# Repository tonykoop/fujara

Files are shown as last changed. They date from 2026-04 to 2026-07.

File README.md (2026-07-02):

# Fujara — Engineering Documentation for the Slovak Overtone Shepherd's Flute

> *Parametric design documentation for stave-built fujaras — the deep, harmonics-driven Slovak shepherd's flute, traditionally 5–8 feet tall and tuned to play melodies from the natural overtone series rather than from finger holes.*

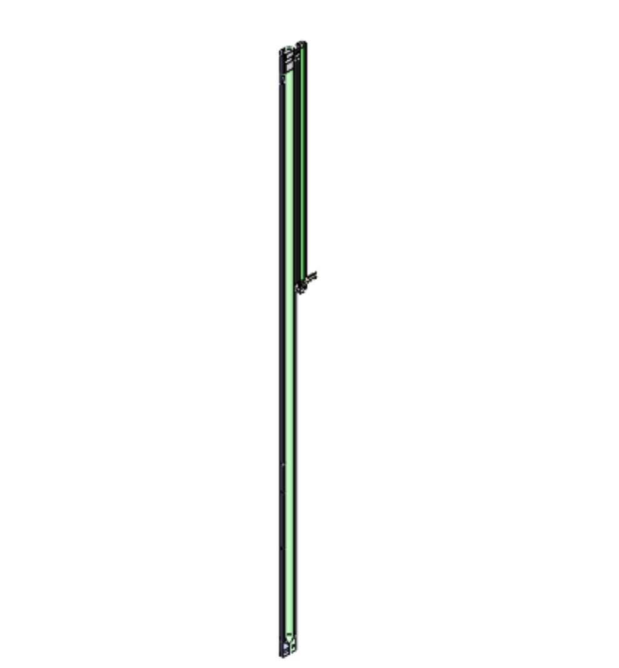
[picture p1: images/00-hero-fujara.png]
Hero photo

*Early fujara body concept render: a tall overtone flute body with side air tube and three-hole voicing, captured here as a parametric CAD/design-table problem before the first physical build.*

**Status:** L2 V5 build-packet candidate

V5 build-packet candidate for design review. The repo contains
design-table, SolidWorks, OpenSCAD starter, vector-plate, print-packet, and
validation artifacts, but it is **not build-ready or empirically verified**
until the bore, flue/labium, side air tube, and tuning-response measurements in
`validation.csv` are captured.

## What this is

Engineering documentation for the **fujara** — a tall, three-hole, side-blown overtone flute originating with the shepherds of central Slovakia. The fujara is recognized by UNESCO as a Masterpiece of the Oral and Intangible Heritage of Humanity (proclaimed 2005, inscribed on the Representative List in 2008).

This repository combines:

1. **A parametric design table** ([`design-table/fujara-dimensions-parametric.xlsx`](design-table/fujara-dimensions-parametric.xlsx)) covering fundamentals from **D2 (~73 Hz, 94" blank) up through F#3 (~185 Hz, 40" blank)**, with formulas that derive every build dimension — bore ID at four candidate aspect ratios (45:1 / 50:1 / 55:1 / 60:1), wall thickness, the three traditional finger-hole positions, blank dimensions — from a single input: the target fundamental note.
2. **CAD geometry** for the body, the side-blown mouthpiece chamber, the labium/voicing geometry at the top of the main bore, and the cutting jigs.
3. **Acoustic analysis** comparing the fujara's harmonic-series voicing to my [Native American flute](https://github.com/tonykoop/flutes) calculations — the design table includes a "NAF CALC K2" cross-reference column.

For a browsable studio map of the current design tables, CAD sources, capstone analysis, validation caveats, and open release blockers, open [`explorer.html`](explorer.html).

Sister project to [`flutes`](https://github.com/tonykoop/flutes), [`djembe`](https://github.com/tonykoop/djembe), [`dundun`](https://github.com/tonykoop/dundun), [`didgeridoo`](https://github.com/tonykoop/didgeridoo), and [`ashiko-drum-workshop`](https://github.com/tonykoop/ashiko-drum-workshop).

## Cultural attribution

The fujara originates with the shepherds of the **Podpoľanie region of central Slovakia** and is considered an emblem of Slovak rural and pastoral culture. UNESCO recognized "Fujara and its music" on the Representative List of the Intangible Cultural Heritage of Humanity in 2008 (initially proclaimed a Masterpiece in 2005). The instrument carries deep cultural significance in Slovak folk music — particularly in *trávnice* (grass songs) and shepherd melodies — and contemporary makers in Slovakia continue traditional methods, often using elderberry or other native woods.

The instruments documented in this repository are built in respect for that tradition by a non-Slovak maker, using stave construction with locally-available North American hardwoods. The engineering documented here is my own derivation; the cultural and musical practice belongs to the Slovak communities from whom the instrument originates.

## Background — what makes a fujara different from every other flute in this portfolio

The fujara is acoustically and architecturally distinctive in three ways:

**1. Melody comes from the harmonic series, not from finger holes.** A fujara has only **three finger holes** (compared to six on a Native American flute, six on a recorder). Those three holes shift the air column's effective length only slightly — they're tuning aids, not melody keys. The melody itself is produced by the player **overblowing** the air column to excite progressively higher harmonics: the 2nd partial (octave above fundamental), 3rd (perfect 5th above that), 4th (octave above the 2nd), 5th (major 3rd), 6th, 7th, 8th, and so on. Combined with the three hole positions, this yields the lydian-flavored modal scale characteristic of fujara melody.

**2. Side-blown air path with a parallel chamber.** Unlike an end-blown flute (didgeridoo, recorder), the fujara has a thin secondary tube running parallel to the main bore for the player's air. The mouthpiece is at the top of this side tube; air travels down it, gets routed across a precisely-cut **labium** (sound-hole edge) at the top of the main bore, and excites the main air column. This split allows the player to address the labium at exactly the right angle and pressure without their face being directly above the bore — important when the instrument is 6+ feet tall.

**3. The instrument is *long*.** A fujara tuned to D2 (~73 Hz) wants a build length of roughly 94 inches — close to 8 feet. Even a shorter F#3 fujara is over 3 feet. The proportions are dictated by acoustics: a low fundamental at audible loudness needs a long air column. The challenge of building one is that you cannot just CNC-mill an 8-foot pipe out of one block of hardwood — staves are practically required.

## The parametric design table

The single engineering-heavy artifact in this repository is the parametric design table. Variables are listed in column A, calculated/tabulated values flow from them:

**User-set variables (per key):**

| Var | Meaning | Range across D2 → F#3 |
|---|---|---|
| A | Blank length | 94" (D2) → 40" (F#3) |
| B | Blank width | 2.25" → 1.5" |
| C | Blank thickness | 1.125" → 0.75" |
| D | Mouthpiece length | 20" → 14" |
| F | Spacing | 0.75" (constant) |
| H | Extra length (chuck jaws) | 2.5" |
| K | Bore inner diameter | 1.25" → 0.875" |
| L | Wall thickness | 0.3125" → 0.1875" |
| M | Nest distance from mouthpiece | 17.75" → 9.75" |
| N–P | Sunken nest depth, width, length | 0.34" / 0.875" / 4.0" |
| Q | Sound hole + flue width | 0.625" → 0.375" |
| R | Sound hole length | 0.25" |

**Calculated/derived (per key, formula-driven):**

- Long Chamber length (the playing tube) and acoustic length (with K1 foot-end and K2 sound-hole end corrections)
- The three hole positions: **Hole 3 at 68%, Hole 2 at 73%, and Hole 1 at 83%** of the way from the foot end of the long chamber. These percentages are the traditional fujara hole positions.
- Hole frequencies for each note in the resulting scale, derived from the chromatic equal-temperament reference `f = 440 × 2^((n-49)/12)`.
- Inner diameters at four candidate **length-to-diameter aspect ratios — 45:1, 50:1, 55:1, 60:1** — to evaluate trade-offs between bright/forward and dark/recessive voicing.

The table extends from **D2 (piano key 18) up to F#3 (piano key 34)** — about an octave and a half of fundamentals, encompassing both the deepest traditional fujaras and the more compact "fujarka" variants.

## Engineering challenges this repository documents

**1. Acoustic length and end correction.** A fujara's effective acoustic length differs from its physical length because of two end corrections: K1 at the open foot end (~0.4 × bore radius) and K2 at the sound-hole end (much larger, varying with sound-hole geometry). The design table calculates K2 directly from the sound-hole + nest geometry rather than using a constant — and cross-references against my Native American flute K2 calculations as a sanity check.

**2. Stave construction at unusual proportions.** Building an 8-foot stave-glued cylinder is not the same engineering problem as building an 18-inch ashiko or a 30-inch djembe body. The aspect ratio makes glue-up clamping and lathe turning their own categories of challenge — you can't fit a 94-inch blank between standard lathe centers.

**3. Voicing the labium.** Unlike a NAF (where a removable bird/fetish block does the voicing), the fujara's labium is cut directly into the main bore at the top of the long chamber, with the side-tube air path positioned to address it. Small differences in labium geometry produce large differences in playability. The design table establishes the geometry; the build is where the voicing is dialed in.

## CAD and jig design

This repo now keeps both the original SolidWorks source set and a lightweight
OpenSCAD starter at [`CAD/fujara.scad`](CAD/fujara.scad). The OpenSCAD file is
a review scaffold with named parameters tied back to `family-spec.csv`,
`sw-reference/Fujara-SW-Design-Table.csv`, and the SolidWorks dimension CSVs;
it is not a substitute for exporting and reviewing the native CAD before shop
use.

Repository structure is laid out for:

- `/CAD/fujara-body/` — the long chamber geometry and side-tube assembly, parametric in target fundamental.
- `/CAD/labium-and-nest/` — the cut at the top of the main bore that the air strikes, and the sunken nest where the side tube meets the main body.
- `/CAD/jigs/` — cutting fixtures. The hole-positioning jig is the most interesting — it has to mark Hole 3, Hole 2, Hole 1 at the calculated percentages of the long chamber length, which itself varies by key.

## Comparison across the instrument portfolio

The fujara closes a useful gap across my instrument repos:

| Instrument | Body | Acoustic principle | Tuning |
|---|---|---|---|
| ashiko | truncated cone | open membrane (head) | drum |
| djembe | goblet | open membrane (head) | drum |
| dundun | cylinder, dual-headed | dual coupled membranes | drum |
| didgeridoo | long cylinder/cone | overblown bore, lip drone | overtone series |
| flutes (NAF) | short cylinder | fipple + finger holes | pentatonic minor |
| **fujara** | **long cylinder** | **fipple + overblown overtone series** | **harmonic series** |

The fujara is the only flute in the portfolio that derives its melody from overblowing rather than finger holes — and the only one tall enough that *single-piece construction is impractical*, making stave-build the natural method.

## What this work is for

- **The acoustic question** — does a parametric design table that works for short NAFs scale up to 8-foot fujaras? The shared "NAF CALC K2" reference column in the design table is the bridge: same end-correction model, very different proportions.
- **The fabrication question** — what stave count, glue-up sequence, and lathe arrangement make an 8-foot tall hollow wooden cylinder achievable for one person to build?
- **The portfolio frame** — the fujara extends the engineering documentation to a sixth instrument family and a seventh continent (Slovakia / Eastern Europe). Together with the others, the repos document a coherent practice across drum and flute traditions on multiple continents.

## License

Released under [CC-BY 4.0](LICENSE) — use freely with attribution. The fujara originates with Slovak culture and is recognized by UNESCO as Intangible Cultural Heritage; the engineering documentation, parametric design table, and CAD work in this repository are my own work, free to reuse and adapt with credit.

## Repository structure

```
fujara/
├── README.md                  ← you are here
├── LICENSE                    ← CC-BY 4.0
├── .gitignore
├── design-table/
│   └── fujara-dimensions-parametric.xlsx   ← the engineering core
├── research/                  ← Slovak fujara references, UNESCO documentation
├── analysis/                  ← acoustic length math, harmonic series mapping
├── CAD/
│   ├── fujara-body/           ← long chamber + side tube parametric in key
│   ├── labium-and-nest/       ← labium cut + side-tube interface
│   └── jigs/                  ← hole-positioning jig (variable by key)
├── drawings/                  ← PDF exports
├── images/                    ← finished-build photos + figures
└── reference/                 ← fujara playing references, scale documentation
```

## Status

| Section | Status |
|---|---|
| Repo description, license, gitignore | ✓ done |
| Parametric design table | ✓ committed (the engineering core) |
| Cultural attribution | ✓ done |
| Hero render / concept image | ✓ committed; concept-only |
| CAD — body geometry | SolidWorks sources plus OpenSCAD starter committed |
| CAD — labium and nest | SolidWorks sources present; shop review required |
| CAD — jigs | placeholders and legacy CNC files present; not released for cutting |
| Acoustic length cross-check vs. NAF | explicit in packet; empirical fujara measurements still required |
| Physical builds | no measured prototype evidence committed |
| Evolution-pipeline intake | Stage 0 intake added under `evolution/` (manifest, design-intent, revisions); Gate A not yet run |

A repository in motion, not a finished portfolio piece.

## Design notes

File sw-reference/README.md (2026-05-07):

# Fujara — SolidWorks Reference

Authoritative SolidWorks-side reference for the Fujara assembly. Companion to
`design-table/fujara_equations.md` (per-part explanatory content) and
`drone-flutes/sw-reference/Drone-Flutes-SolidWorks-MasterLayout.docx` (sister-instrument template).

## Files

- `Fujara-SolidWorks-MasterLayout.md` — design intent for the parametric skeleton: master sketch hierarchy, tier-1/2/3 globals, per-part inheritance, configuration scheme, quality gates, Pack-and-Go forward path. **Read first.**
- `Fujara-Master-Inputs.csv` — flat list of every `g_*` and `c_*` global plus tier-3 derived dims and voicing literals. The human-edit surface for the design table.
- `Fujara-SW-Design-Table.csv` — SW-shaped design table. Open in Excel, save as `Fujara-SW-Design-Table.xlsx`, then in SolidWorks: `Insert > Tables > Design Table > From Existing File`.

## Workflow

```
Master_Inputs.csv (edit globals here)
  ↓
Fujara-SW-Design-Table.csv → save as .xlsx
  ↓
Insert > Tables > Design Table > From Existing File
  ↓
G2Fujara_MasterLayout.SLDPRT (skeleton part, Tools > Equations)
  ↓
Sketch dimensions = g_<name>
  ↓
Downstream parts consume master sketches via Convert Entities + share globals via the same design table
  ↓
Extract_Dimensions.swp → CAD/fujara-body/G2Fujara_Assembly.SLDASM_dimensions.csv
  ↓
ingest_dimension_csv.py validates SW vs Excel
```

## Configurations (initial)

| Configuration | Status |
|---|---|
| `MASTER_TEMPLATE` | seed; preserves current build values; **never delete** |
| `G2_69in` | matches current single-config geometry from May 2026 macro dump |
| `D2_94in` | TBD — populate from `design-table/fujara-dimensions-parametric.xlsx` |
| `F2_77in` | TBD — populate from workbook |
| `A2_60in` | TBD — populate from workbook |

The non-MASTER_TEMPLATE rows have placeholder body lengths — replace with the workbook's per-key values before activating those configurations in SW.

## Migration to Moseno

The MasterLayout part is what Pack-and-Go's into the Moseno repo. See
`moseno/sw-reference/Fujara-to-Moseno-Migration.md` for the rename map and
the Moseno-specific deltas (external blow-pipe, six diatonic finger holes,
four foot tuning holes).

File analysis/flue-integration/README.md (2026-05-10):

# Flue integration variant study (fujara #2)

**Readiness:** L2 design comparison + first-pass 1-D Webster re-run.
**Physics gate:** met (re-uses the merged capstone PR #3 solver).
**Empirical gate:** deferred — no prototype data, no L4 claim.

## Question

The current G2 fujara build has three voicing parts above the labium:

- `G2FujaraTop` / `FujaraBottomG2` — the two halves of the split-blank
  body. Already carry the long fipple-ramp / flue-dam features
  (~349 mm / ~393 mm long) milled into their inside faces.
- `G2FujaraFlue` — a 31.75 mm × 53.975 mm cylindrical block plugged
  into the bore at the head joint. Carries the air duct + windway
  engagement.
- `G2FujaraFluePlug` — a removable wax-sealed plug for fine-tuning.

This study asks: **can the G2FujaraFlue block be eliminated and its
features rolled into G2FujaraTop + FujaraBottomG2?**

## Variants compared

| | Separate-flue (current G2) | Integrated-flue |
|---|---|---|
| Body parts above labium | top + bottom + flue block | top + bottom |
| Permanent glue joints in head | 3 (top↔bottom, top↔flue, bottom↔flue) | 1 (top↔bottom) |
| Flue plug retained? | yes (wax-sealed) | yes (wax-sealed) |
| Active resonator | labium → foot (unchanged) | labium → foot (unchanged) |
| Bore geometry below labium | unchanged | unchanged |

The flue plug stays in both variants — it is the user-facing voicing
adjustment, not a manufacturing artifact.

## Findings (TL;DR)

1. **Acoustically a wash.** The 1-D Webster solver reports
   `delta_modal = 0.000 Hz` and `delta_coupled = 0.000 Hz` across all
   five modes. Both variants share the same labium-to-foot length, the
   same bore ID, and the same wall geometry — the only inputs the 1-D
   model sees. See [acoustic-impact.md](acoustic-impact.md).

2. **Geometry is interchangeable.** The integrated variant absorbs the
   54 mm flue-block features as additional pocket cuts on the inside
   faces of the two body halves — the split-blank construction already
   exposes both faces to CNC. See
   [geometry-comparison.md](geometry-comparison.md).

3. **Manufacturing trades complexity for finality.** Integrated drops
   one part, two glue joints, and one alignment fixture. In exchange,
   the windway becomes irreplaceable once the body halves are glued —
   the separate-flue variant lets you swap a recut block without
   rebuilding the whole instrument. See
   [manufacturing-impact.md](manufacturing-impact.md).

4. **Recommendation:** integrated wins for production runs once the
   voicing literals stabilise. Separate wins during prototyping and
   for repair-friendliness. See [recommendation.md](recommendation.md).

## Reproduce

The cavity FEM re-runs the merged capstone solver against the same
A2 baseline (110 Hz, 50:1 aspect):

```
python3 analysis/flue-integration/scripts/integrated_flue_cavity.py
```

Outputs land in `analysis/flue-integration/data/`. The script imports
from `capstone/scripts/{fujara_design_math,acoustic_cavity_fem}.py` —
no solver code is duplicated.

## Files

- [README.md](README.md) — this overview
- [geometry-comparison.md](geometry-comparison.md) — side-by-side
  dimension table
- [acoustic-impact.md](acoustic-impact.md) — Webster re-run + sensitivity
- [manufacturing-impact.md](manufacturing-impact.md) — joinery, jig, tolerance
- [recommendation.md](recommendation.md) — when each variant wins
- `scripts/integrated_flue_cavity.py` — comparison driver
- `data/integrated-vs-separate.csv` — per-mode delta
- `data/sensitivity-end-correction.csv` — f0 vs ±2 mm end-correction shift

## Hardware-development gate

| Gate | Status | Evidence |
|---|---|---|
| Math | met | Reuses capstone closed-form geometry |
| Physics | met | 1-D Webster + wall-flex correction re-run |
| Empirical | deferred | Requires a prototype of the integrated variant |

The deferred empirical gate is the honest line. The 1-D model cannot
distinguish the two variants; promotion to L4 requires a built-and-blown
integrated-flue body and a comparison of measured f0, second-mode
purity, and overblow stability against the existing G2 build.

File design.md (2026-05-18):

# Fujara V5 Candidate Design Notes

Current status: V5 build-packet candidate, not build-ready.

The fujara is treated here as an open-open edge-tone/overtone flute. The long
main bore controls the fundamental and overblown harmonic series; the side air
tube and flue deliver the jet to the labium and can strongly affect response,
but they are not modeled as a second pitched resonator in this packet.

## Governing Acoustic Model

- `acoustic_law`: `open_open`
- `end_condition`: `both_ends_open`
- First-pass pipe relation: `L_eff = c / (2 f)`
- Room-temperature validator check: 20 C speed of sound.
- Warm-playing discipline: final tuning must compare room measurements with a
  breath-warmed condition before any trim/cut geometry is released.

For the A2 study baseline at 110 Hz, the simple open-open relation gives a
room-temperature effective length near 1559 mm before end-correction choices.
The committed family-spec row records a validator-compatible first-pass
geometry length of 1550.96 mm after the validator's default open-open end
correction. Existing SolidWorks and workbook dimensions remain the design
evidence to review, not proof of a tuned physical build.

## Bore, Flue, And Side-Tube Discipline

The V5 packet separates three questions that were previously easy to blend:

- Main bore: length, inner diameter, wall thickness, and open-end correction.
- Flue/labium: jet width, sound-hole length, nest depth, edge distance, and
  voicing adjustability.
- Side air tube: delivery path length, leakage, pressure drop, junction angle,
  and alignment to the labium.

The side tube should be measured as an air-delivery branch. Do not use it to
move the fundamental unless a measured prototype shows a repeatable coupled
resonance effect.

## Fabrication Authority

Candidate fabrication authority is limited to the design tables, native
SolidWorks files, SolidWorks dimension CSVs, the OpenSCAD starter, and the
dimensioned vector plate. Generated or rendered images are concept-only. The
DXF is a dimensioned review plate, not CAM-ready toolpath output.

## Promotion Blockers

- Measure bore stations at the foot, mid-body, branch/labium zone, and top.
- Measure flue width, sound-hole length, labium edge distance, and nest depth.
- Confirm side-tube leakage and junction angle before treating response claims
  as stable.
- Record tuner measurements for fundamental and overblown partials at a known
  temperature/humidity.
- Export/review CAD/DXF from the authoritative CAD workflow before machining.

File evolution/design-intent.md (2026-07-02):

# Design Intent — fujara rev A

- Master CAD: `CAD/fujara.scad` (sha256: 190f380fcafa50e0e100f06de4f9074fb25d0c7fa3dfdc7ff3e39e73c57e09af) with native SolidWorks assembly `CAD/fujara-body/Fujara_Assembly.SLDASM`, driven by `design-table/fujara-dimensions-parametric.xlsx` (sha256: 8067350d3233be8ecccbec798d0cbfb39151a577be4614266ba0883d7fdd3033)
- Function: Slovak overtone shepherd's flute (fujara) — a deep, harmonics-driven stave-built flute (traditionally 5–8 ft tall) that plays melodies from the natural overtone series rather than from finger holes. Long open-open main bore with a side air-delivery tube (jet delivery, not a pitched resonator) and three-hole voicing. First pass uses an open-open validator model.
- Environment: long stave glue-up (bore distortion risk); breath-contact finishes must be cured/food-safe; overtone response depends on bore + flue/labium + side tube measured together. Cultural attribution to Slovak fujara tradition stays visible (engineering derivation, not ownership).
- Target qty: 1 (per selected key). Deadline: TBD. Budget/unit ceiling: TBD.

## Critical dimensions (carry tolerances)

| Feature | Nominal | Tolerance | Why critical | Source |
| --- | --- | --- | --- | --- |
| A2 predicted geometric length | 1550.96 mm | measure fundamental + overtone alignment | fundamental pitch (A2 = 110.00 Hz) | family-spec.csv FUJ-A2-STUDY (physics_derived) |
| Main bore ID | 31.75 mm | measure after stave glue-up | bore governs pitch/overtones | family-spec.csv FUJ-A2-STUDY |
| Bore aspect ratio | 49.0 | recompute from measured bore | slender-bore overtone behavior | family-spec.csv FUJ-A2-STUDY |
| Three tone-hole positions | 68/73/83% of long chamber length | tune to overtone scale physically | melodic overtone scale | family-spec.csv hole_rule |
| Flue width | TBD | response-critical; adjust by hand | voicing / speaking | family-spec.csv (measurement_required) |
| Side air tube role | air-delivery branch (measurement_required) | measure leakage/pressure/junction | jet delivery + response | family-spec.csv side_tube_role |

## Incidental (free for DFM)

- Exterior body styling/taper, decorative carving/banding, stave count cosmetics, finish color, mouthpiece exterior — subject to breath-safety.

## Must-nots (DFM may never violate)

- Flue/labium/voicing geometry is response-critical and tuning-sensitive: refine by hand, never freeze from the scaffold or a lossy export (risks.md Acoustic).
- Do not treat SolidWorks files as authority for a given key until a configuration-specific export is reviewed (risks.md Fabrication).
- DXF/SVG plates are review plates, not CNC toolpaths — do not cut from them (register / risks.md).
- Do not treat the side air tube as a pitched resonator without measurements (family-spec).
- Breath-contact finishes/adhesives must be fully cured and food-safe (risks.md Safety).

## Material intent

- Preferred: stave-built wood body per bom.csv; long stock with adequate lathe/workholding capacity.
- Acceptable subs: per sourcing.csv (spec-first; live prices unverified; breath-safe finishes only).
- Forbidden: uncured/non-food-safe interior finishes on breath-contact surfaces.

## Stage status

Stage 0 intake complete 2026-07-01. Gate A (Alpha shop compile) NOT yet run — no concessions logged, nothing presented as shippable. L2 candidate; authority remains measurement-gated.

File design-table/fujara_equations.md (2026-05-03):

# Fujara Equations & Global Variables

Starter parametric scheme. Add globals via **Tools > Equations** in each part, then drive feature dims from them.

Conventions:
- All values in **mm** (SolidWorks accepts mm even when the part displays in inches).
- Names in `snake_case`.
- A leading `g_` marks a true design-master global (the small set you'd actually tune).
- A leading `c_` marks a fit-clearance constant (interference is negative).

---

## Tier 1 — Design master globals

These are the only numbers you change to retune the whole instrument. **Define identically in every part that uses them.** (Long-term: move to assembly-level externals or a master sketch — for now, sync by hand.)

| Global | Value (mm) | Value (in) | Used in |
|---|---|---|---|
| `g_body_OD` | 47.625 | 1.875 | top, bottom |
| `g_body_ID` | 31.75 | 1.250 | top, bottom (= 2 × bore radius) |
| `g_body_L_finished` | 1755.775 | 69.125 | top, bottom, assembly |
| `g_body_L_blank` | 1803.4 | 71.000 | top, bottom |
| `g_body_blank_W` | 57.15 | 2.250 | top, bottom |
| `g_mp_block_OD` | 28.575 | 1.125 | mouthpiece top + bottom block |
| `g_mp_block_ID` | 15.875 | 0.625 | mouthpiece top + bottom block |
| `g_mp_block_L_blank` | 735.584 | 28.960 | mouthpiece top + bottom block |
| `g_mp_block_blank_W` | 38.1 | 1.500 | mouthpiece top + bottom block |
| `g_mp_tube_OD` | 15.875 | 0.625 | mouthpiece (blow-tube part) |
| `g_mp_tube_ID` | 9.525 | 0.375 | mouthpiece, toptube |
| `g_dowel_OD` | 6.35 | 0.250 | top, bottom (matches 1/4" stock) |
| `g_thru_passage_OD` | 12.7 | 0.500 | flue, body bottom, mp blocks, fipple chamfer |

---

## Tier 2 — Fit / clearance constants

Define once in each part; same value everywhere. **Sign convention**: clearance is positive (hole is bigger), interference is negative.

| Constant | Value (mm) | Value (in) | Use case |
|---|---|---|---|
| `c_glue_gap` | 0.0762 | 0.003 | wood-on-wood permanent glued joints (body halves mating, breath connector glued in place) |
| `c_wax_seal_fit` | 0.0762 | 0.003 | removable parts sealed with beeswax (flue plug — pulls out for drying/cleaning) |
| `c_slip_fit` | 0.381 | 0.015 | non-sealed slip fit (ornament tubes in mounting holes) |
| `c_dowel_clearance` | 0.0 | 0.000 | dowel pin hole = pin OD (snug, glued) |
| `c_cork_interference` | -0.1524 | -0.006 | cork plug oversized vs bore — interference seal blocks horizontal air path, redirecting flow vertically through breath connector |

`c_glue_gap` and `c_wax_seal_fit` happen to share a value today but represent different design intent. Keep them separate so when you dial in the actual wax thickness through testing, you don't accidentally widen every glue joint in the instrument.

### Air flow path (for context — drives which fits matter)

Player → horizontal channel in body bottom → blocked by **cork** (interference seal) → vertical up through **breath connector** tube (glue-fit through both body halves) → into voicing area → through **flue plug** slot (0.040" height, wax-sealed, removable) → across the cutting edge of the flue chamfer (sound is produced here).

---

## Tier 3 — Per-part equations

Format: `"name" = expression`. Paste into **Tools > Equations** > Global Variables.

### G2FujaraTop.SLDPRT

```
"g_body_OD" = 47.625
"g_body_ID" = 31.75
"g_body_L_finished" = 1755.775
"g_body_L_blank" = 1803.4
"g_body_blank_W" = 57.15
"g_dowel_OD" = 6.35
"g_thru_passage_OD" = 12.7
"c_glue_gap" = 0.0762
"c_dowel_clearance" = 0
"board_thickness" = "g_body_blank_W" / 2
"blank_length" = "g_body_L_blank"
"blank_width" = "g_body_blank_W"
"bore_inner_radius" = "g_body_ID" / 2
"outer_diameter" = "g_body_OD"
"finished_length" = "g_body_L_finished"
"dowel_pin_diameter" = "g_dowel_OD" + "c_dowel_clearance"
```

Voicing (unique acoustic params — keep as literals, **not** globals):
```
"fipple_gap" = 10.16
"fipple_ramp" = 349.0659
"flue_dam" = 392.6991
"flue_depth" = 12.1285        ' Sketch5
"flue_depth" = 0.8382          ' Sketch8 — note same name, different sketch is fine
"fipple_height" = 0.254
"fipple_ramp_in" = 87.2665
```

Tuning (finger holes — these are the per-pitch numbers; each fujara key gets its own set):
```
"hole1_diameter" = 7.62
"hole2_diameter" = 7.62
"hole3_diameter" = 7.62
"fipple_to_hole1" = 1157.224
"fipple_to_hole2" = 1242.314
"fipple_to_hole3" = 1412.494
```

End cap groove (driven by OD — already correct in your model):
```
"groove_width" = 3.175
"groove_depth" = 6.35
"groove_location" = "g_body_OD"     ' confirms your IsDriven=TRUE
```

### FujaraBottomG2.SLDPRT

Same `g_*` and `c_*` block as top, plus:
```
"thickness" = "g_body_blank_W" / 2
"blank_length" = "g_body_L_blank"
"blank_width" = "g_body_blank_W"
"inner_bore_radius" = "g_body_ID" / 2
"outer_diameter" = "g_body_OD"
"finished_length" = "g_body_L_finished"
"dowel_pin_diameter" = "g_dowel_OD" + "c_dowel_clearance"
"mouthpiece_hole" = "g_thru_passage_OD" + "c_glue_gap"   ' so the 12.7 mp tube glues cleanly
```

> Recommendation: rename `thickness` → `board_thickness` here too, so the top/bottom CSV columns line up.

Mouthpiece tube mounting hole (already has slip fit — make it explicit):
```
"tube_diameter" = "g_mp_tube_OD" + "c_slip_fit"     ' = 15.875 + 0.381 = 16.256 ✓
"bracket_length" = 691.134
```

### G2Fujara_MouthpieceBottom.SLDPRT *(and Top — same equations both halves)*

```
"g_mp_block_OD" = 28.575
"g_mp_block_ID" = 15.875
"g_mp_block_L_blank" = 735.584
"g_mp_block_blank_W" = 38.1
"g_mp_tube_OD" = 15.875
"g_thru_passage_OD" = 12.7
"c_glue_gap" = 0.0762
"c_slip_fit" = 0.381

"thickness" = "g_mp_block_blank_W" / 2
"blank_length" = "g_mp_block_L_blank"
"blank_width" = "g_mp_block_blank_W"
"outer_diameter" = "g_mp_block_OD"
"inner_diameter" = "g_mp_block_ID" + "c_glue_gap"     ' tube OD 15.875, bore 15.952, glue film
"mouthpiece_through_hole" = "g_thru_passage_OD" + "c_glue_gap"
"mouthpiece_location" = 22.225
"counterbore_diameter" = "g_mp_tube_OD" + "c_slip_fit"   ' = 16.256
```

### mouthpiece.SLDPRT (the blow-tube)

```
"g_mp_tube_OD" = 15.875
"g_mp_tube_ID" = 9.525
"mouthpiece_outer_diameter" = "g_mp_tube_OD"
"mouthpiece_inner_diameter" = "g_mp_tube_ID"
"height@tube" = 50.8                 ' literal — overall tube length is its own design choice
"mouthpiece_curved_cut" = 21.4548
```

### Cork.SLDPRT

```
"g_mp_block_ID" = 15.875
"c_cork_interference" = -0.1524
"mid_diameter" = "g_mp_block_ID" - "c_cork_interference"   ' = 15.875 + 0.1524 = 16.027
"taper" = 122.173
"half_height" = 6.35
```

Subtracting a negative gives oversize. If that reads weirdly, flip the sign convention: define `c_cork_press = 0.1524` (always positive) and write `mid_diameter = g_mp_block_ID + c_cork_press`. Pick whichever stays cleaner in your head.

### G2FujaraFlue.SLDPRT (the voicing block)

```
"g_body_ID" = 31.75
"g_thru_passage_OD" = 12.7
"c_glue_gap" = 0.0762

"flue_block_diameter" = "g_body_ID" - "c_glue_gap"   ' = 31.674 — slips into bore with glue film
"flue_width" = "g_thru_passage_OD"
"duct_diameter" = "g_thru_passage_OD"
"flue_engagement" = 3.8862
"duct_location" = 22.225
```

### G2FujaraFluePlug.SLDPRT *(removable, wax-sealed — not glued)*

```
"g_thru_passage_OD" = 12.7
"c_wax_seal_fit" = 0.0762
"flue_plug_width" = "g_thru_passage_OD" - "c_wax_seal_fit"   ' = 12.6238 ✓
"flue_plug_length" = 53.975
"slot_radius" = 5.08
"slot_location" = 22.225
"airway_passage" = 9.525
"flue_height@slot" = 1.016    ' 0.040" — voicing-critical, no clearance, sealed with beeswax
```

The 0.040" slot height is the air-jet thickness — keep as a literal, this is a voicing-tuning parameter.

### toptube.SLDPRT / bottomtube.SLDPRT

These look like ornamental/structural tubes that slip into the mounting holes:
```
"g_mp_tube_OD" = 15.875
"g_mp_tube_ID" = 9.525
"tube_od" = "g_mp_tube_OD"
"tube_id" = "g_mp_tube_ID"
"height@tube" = 15.875       ' literal — could be a separate design global if these need to scale
```

### Assembly (Fujara_Assembly.SLDASM)

```
"g_body_L_finished" = 1755.775
"cut_to_length" = "g_body_L_finished"
```

The assembly sketch now carries the **voicing-aim measurement**:

```
true_sound_hole_to_splitting_edge_offset = 0.2354 mm = 0.0093"   ' IsDriven=TRUE
```

This is a **measured outcome**, not an input — SolidWorks computes it from the geometry. Don't try to drive it from a global; instead, watch it as a KPI. If you change anything in the flue plug, body alignment, or fipple geometry and this number drifts, you'll see it on the next macro run. The 0.0093" sits in the typical fujara voicing window (~0.005"–0.015") — leave it as the canary.

---

## What this buys you

- Change `g_body_L_finished` once — every `finished_length`, `cut_to_length`, etc. updates.
- Change `c_glue_gap` once — every glued joint adjusts together. Test-drive your fits without chasing 12 dims.
- The renamed `D1` dims (board_thickness, height@tube, etc.) become equation-driven, so they show up in the CSV as `IsLinked=TRUE` and the macro will print the formula in `EquationOrComment`.
- The dimensions that are *coincidentally* equal (the 12.7s that aren't all the same passage, the 15.875s that aren't all the tube OD) stay as literals — preserves design intent.

## Suggested next moves

1. Add the master `g_*` globals to `G2FujaraTop` first, drive its dims, save and rerun the macro. Confirm `IsLinked=TRUE` shows up where expected.
2. Repeat for the other parts.
3. Rename `thickness` → `board_thickness` on the bottom half + mouthpiece blocks for consistency.
4. Once it's all wired up, your `fujara-dimensions-parametric.xlsx` design table only needs to expose the `g_*` and `c_*` rows — everything else propagates.

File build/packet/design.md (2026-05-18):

# Fujara Issue #5 V5 Starter

Issue context: `fujara` needs a V5 starter with explicit **bore** and **side-branch** authority gates.

## Scope

- Keep the packet at **V5 build-packet candidate for design review** until
  measurements justify a higher label.
- Focus on long-bore geometry, flue/labium response, and side air-tube delivery
  without treating the side tube as a pitched resonator by default.
- Record what is *observed* vs what is *inferred* from design history.

## Known and Inferred

Observed inputs:

- Existing fujara design table (`fujara-design-table.xlsx`, `design-table/fujara-dimensions-parametric.xlsx`) contains derived candidate dimensions and length-to-diameter ratios.
- Repo CAD references are present for the instrument body and labium structures but are not validated as fabrication-ready in this lane.

Inferred/Starter scope:

- Side air-tube relation to the labium remains the key response variable that
  should be measured before any authoritative CAD/DXF updates.
- Main-bore station geometry, end correction, flue width, sound-hole length,
  labium distance, and side-tube leakage are tracked as measurement blockers
  until `validation-loop` rows are populated.

## Authority Rules for this Packet

- `family-spec.csv` is the packet acoustic-law register and declares a
  validator-checkable open-open edge-tone/overtone flute row.
- `bore-station-plan.csv` is a measurement scaffold, not authority on its own.
- `visual-output-register.csv` must keep generated or concept outputs as non-authoritative unless proven by measured rows.
- No branch transitions to L3/L4 until acoustic-law and bore/side-branch measurement gates are passed.

## Gate Plan

Populate measurement rows and update gate status in this order:

1. Confirm acoustic-law row and side air-tube delivery hypothesis in `family-spec.csv`.
2. Measure bore stations and side-branch transition distances in `bore-station-plan.csv`.
3. Complete `validation-loop.csv` for response, bore station capture, and authority gating.
4. Advance `validation.csv` gates only when all evidence is present.

## First Tests to Collect

- Main-bore stations: mouth-end, side-branch injection point, and labium end.
- Side-branch geometry: entry path length, offset to labium, and junction angle.
- Side-branch response behavior: leak/suction checks and basic pressure-to-stability notes.
- One non-structural visual check only (photo/plan review) before any fabrication claim.

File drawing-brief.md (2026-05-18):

# Fujara Drawing Brief

Current status: V5 build-packet candidate, not build-ready.

## Drawing Set

- `drawings/fujara.svg`: human-readable vector review plate.
- `drawings/fujara.dxf`: dimensioned review plate for CAD/CAM handoff checks.
- `CAD/fujara.scad`: OpenSCAD starter showing named parameters and layout.
- `print-packet/assembly-plate.pdf`: annotated review/assembly plate.

## Authority Chain

Fabrication dimensions are controlled by the design tables, SolidWorks source
CAD, SolidWorks dimension CSVs, and reviewed CAD/DXF exports. The SVG, DXF,
OpenSCAD starter, and print plate in this lane are candidate review artifacts
that must be checked against the selected key/configuration before machining.

Generated images and renders are concept-only and do not control bore length,
hole position, flue geometry, side-tube placement, or toolpaths.

## Required Callouts

- Target note and frequency.
- Open-open governing model and temperature assumption.
- Long chamber length and bore ID source.
- Hole positions at 68%, 73%, and 83% of long chamber length.
- Flue width, sound-hole length, labium edge distance, and side-tube junction
  as measurement-required until captured.
- Explicit "not CAM-ready" note on any DXF that has not been shop-reviewed.

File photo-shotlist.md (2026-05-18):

# Fujara Photo Shotlist

Use neutral shop documentation. Do not publish private location, family, or
child imagery.

| shot_id | subject | purpose | status |
| --- | --- | --- | --- |
| PH-001 | Full instrument against a height reference | Scale and public overview | needed |
| PH-002 | Labium and flue close-up | Response-critical geometry | needed |
| PH-003 | Side air tube junction | Delivery path and leak-check evidence | needed |
| PH-004 | Bore foot/end view | End correction and bore ID reference | needed |
| PH-005 | Three-hole layout | Hole position verification | needed |
| PH-006 | Tuner capture during fundamental | Validation evidence | needed |
| PH-007 | Tuner capture during overblown partials | Harmonic-series validation | needed |
| PH-008 | Assembly fixture/workholding | Fabrication repeatability | needed |

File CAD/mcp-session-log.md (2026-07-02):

# MCP Session Log

V5 provenance — aligned with `tonykoop/instrument-maker` V5 build-packet standard.

This repository has historical SolidWorks and design-table artifacts plus
Round 30 hand-authored review artifacts and a bob/r1 monolithic-variant scaffold.
No Claude Desktop MCP session was run in any lane.

| session_id | tool | input_authority | outputs | role | authority_result | review_status | notes |
| --- | --- | --- | --- | --- | --- | --- | --- |
| 2026-05-18-scad-v1 | openscad | design-table/fujara-dimensions-parametric.xlsx; sw-reference/Fujara-SW-Design-Table.csv | CAD/fujara.scad | cad_authoring | pending_measurement | unreviewed | OpenSCAD starter from design-table/SolidWorks references; review scaffold; NOT fabrication authority. |
| 2026-05-18-svg-dxf-v1 | illustrator_manual | design-table/fujara-dimensions-parametric.xlsx | drawings/fujara.svg; drawings/fujara.dxf | drawing_cleanup | derived_preview | unreviewed | Vector review plates; candidate dimension references; not CAM toolpaths. |
| 2026-05-18-print-v1 | manual | design.md; bom.csv; validation.csv | print-packet/assembly-plate.pdf | print_plate | derived_preview | unreviewed | Generated from packet text for review; no Photoshop/Illustrator MCP session available. |
| 2026-05-29-bob-r1-monolithic | openscad | CAD/fujara.scad; family-spec.csv; design-table/fujara-dimensions-parametric.xlsx | CAD/fujara-body-monolithic/fujara-monolithic.scad | cad_authoring | pending_measurement | unreviewed | Monolithic body variant (issue #2): integrates Flue_Top geometry into Body_Top + Body_Bottom modules. All flue/labium dimensions are measurement-required starters. Not fabrication authority. |
| fable-v5-refresh-2026-07-01 | claude-code (Fable 5) | design-table/fujara-dimensions-parametric.xlsx | fujara-design-table.xlsx, design-table/fujara-dimensions-parametric.xlsx | packet_refresh | fabrication | self_checked | V5 refresh pass; historical design-table workbooks reviewed against parametric authority. No dimension changes. Provenance row registers fujara-design-table.xlsx into the log to satisfy V5 fabrication-artifact logging. |
| fable-v5-refresh-2026-07-01 | solidworks (native source, pre-existing) | design-table/fujara-dimensions-parametric.xlsx | CAD/fujara-body/Fujara_Assembly.SLDASM, CAD/fujara-body/G2Fujara_Assembly.SLDASM_dimensions.csv | source_registration | fabrication | self_checked | Registers pre-existing native SolidWorks assembly + its extracted G2 dimension CSV into the provenance log (no MCP session run). Candidate dimension review only; select/review per key before build. |
| fable-v5-refresh-2026-07-01 | claude-code (Fable 5) + OpenSCAD CLI | design-table/fujara-dimensions-parametric.xlsx | CAD/fujara.scad | cad_authoring | pending_measurement | self_checked | Existing OpenSCAD starter (kept, not rewritten). openscad render check: pass (openscad -o STL, exit 0). |
| fable-v5-refresh-2026-07-01 | claude-code (Fable 5) | design-table/fujara-dimensions-parametric.xlsx | build/wolfram/side-branch-relation/fujara_sidebranch_starter.wl | analysis_source | derived_preview | unreviewed | Existing Wolfram side-branch starter; source-only (not executed). L2 evidence. |

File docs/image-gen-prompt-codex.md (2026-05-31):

# Image Generation Prompt

Concept visualization only. Do not treat generated images as dimensional, tuning, CAD, DXF, or fabrication authority.

## Hero Prompt

Photorealistic studio product photograph of a finished stave-built fujara concept, an extremely tall Slovak overtone flute with a long main wooden bore, a parallel side air tube, three finger holes low on the body, and a visible labium or voicing window near the top where the side tube meets the main pipe. Warm hardwood staves, oil finish, subtle shepherd-flute silhouette, full height shown with a stool or wall mark for scale, clean studio background, soft directional lighting, three-quarter product angle, about a 50mm lens, high detail.

## In-Context Prompt

Photorealistic image of the fujara staged upright in a bright woodshop or quiet folk rehearsal room, leaning safely on a padded stand, side air tube and three-hole layout visible. Include long clamps, bore gauges, and a design table notebook with no readable text nearby. Natural light, realistic proportions, environmental storytelling around validating a very long side-blown overtone flute.

## Detail/Macro Prompt

Close-up macro of the fujara side-tube junction and labium area: parallel air tube feeding into a carefully cut voicing window on the main bore, crisp splitting edge, oiled hardwood, tight joinery, three-hole body fading into the background, soft raking light, photorealistic high detail.

## Negative / Avoid

Avoid logos, watermarks, readable text, recorder-like headjoints, six-hole flute layouts, impossible tube connections, miniature proportions, and fake traditional decoration.

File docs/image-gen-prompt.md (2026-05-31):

# Image-Gen Prompts

Concept image only; not fabrication authority. Do not include cut-ready dimensions, hole locations, or toolpaths.

## Hero Prompt

A single tall Slovak fujara overtone flute standing nearly vertical as a finished physical object, photographed in a clean neutral studio. The instrument is a very long, slender stave-built wooden cylinder — close to two meters tall — with a smooth turned hardwood surface showing warm North American hardwood grain and subtle vertical glue lines from the staves. Its signature recognizable feature is the thin secondary air tube running parallel to the main bore for roughly the upper third of the length, joined to the main body at a sunken nest where the side tube meets the labium; a side-blown mouthpiece sits at the very top of this parallel tube. The main bore shows an open foot end at the bottom and a small cut labium / sound-hole near the top of the long chamber, with only three modest finger holes spaced along the lower body. Hand-rubbed oiled finish, slightly satin sheen, a faint chamfer at the open foot. Realistic scale cues — the flute is taller than an adult, leaning gently against a plain seamless backdrop. Soft directional studio light from the upper left, gentle falloff, 3/4 product-photography angle, ~50mm lens, high detail, photorealistic, no text labels.

## In-Context Prompt

The same tall stave-built fujara staged upright in a quiet woodworking shop, leaning near a workbench with shavings and a few hand tools softly out of focus in the background, the parallel side air tube and top mouthpiece catching window light. Warm natural daylight from a side window, environmental storytelling of a one-person shop where an eight-foot wooden flute is built from staves, shallow depth of field, the full slender length receding gently into soft focus. Concept visualization only, photorealistic, no text.

## Detail Prompt

Macro close-up of the fujara's signature voicing zone: the junction where the thin parallel side air tube meets the main bore at the sunken nest, with the cut labium / sound-hole edge on the main body just below it. Show the precise beveled edge of the labium, the small rectangular sound-hole opening, the flue gap delivering the air jet, and the turned hardwood grain with faint stave glue lines around the nest. Raking low-angle light to reveal the edge geometry and surface texture, very shallow depth of field, high detail, no measurements, no callouts.

## Negative / Avoid

No text, logos, watermarks, or fake maker marks; no dimension lines, measurement callouts, or tuning numbers; no impossible mechanisms; no extra finger holes beyond three; the side air tube is an air-delivery branch, not a second bell — keep it thin and parallel; anatomically plausible hands if a player is shown.

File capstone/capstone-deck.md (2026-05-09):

# Fujara L:D Aspect-Ratio Capstone — Parametric Modal + Acoustic FEM

Tracking issue: `tonykoop/fujara#1`. Sister repo:
[`instrument-maker`](https://github.com/tonykoop/instrument-maker) (v4.3
release candidate).

Status: **L3-frontier** (analysis only). Empirical gate explicitly deferred
until a physical prototype is built and measured.

---

## Slide 1 — Scope

Sweep the four canonical fujara L:D aspect ratios — **45 / 50 / 55 / 60** —
at a fixed design fundamental and report:

1. a parametric design table that generates all build dimensions from the
   target fundamental and the chosen L:D;
2. the lowest five **structural** bending modes of the wooden tube (modal
   FEM scaffold);
3. the lowest five **acoustic cavity** modes of the air column, computed
   modal-only (rigid wall) and coupled (wall flexibility included);
4. an honest comparison and a punch list for the next builder.

The goal is *not* a prediction of perfect tuning. The goal is to land an
analysis scaffold that a future build/measurement loop can plug into.

### Design fundamental

**A2 (110 Hz)** — sits between the deepest D2 (~73 Hz, 94" blank) and the
smallest fujarka F#3 (~185 Hz) documented in
`design-table/fujara-dimensions-parametric.xlsx`, and lines up with the
existing 1.25" bore + 50:1 baseline used in the SolidWorks parts.

---

## Slide 2 — Project intent

The fujara is the only flute in this portfolio whose melody comes from
**overblowing the harmonic series**, not from finger holes. That makes the
cavity-mode spectrum the design target — every mode the player wants to
sound has to be a near-rational ratio of the fundamental, and the wooden
tube must not have a structural mode coincident with one of them.

L:D is the timbre lever. Same fundamental, different bore diameter:

- low L:D (45) → wider bore → more forward, brighter voice, more harmonic
  energy in the upper partials, but easier to overblow;
- high L:D (60) → narrower bore → recessive, dark, breath-economical voice,
  harder to drive the upper partials cleanly.

This capstone is an attempt to put numbers on that intuition before
committing wood.

---

## Slide 3 — Governing models

Three closed-form physics models, all FE-validated in this study.

```
open-open pipe       f_n = n c / (2 L_eff),   L_eff = L + 2 * 0.6 * a
free-free EB beam    f_n = (beta_n L)^2 / (2 pi L^2) * sqrt(EI / (rho A))
wall-flex perturb    dc/c = -0.5 * (rho_air c^2) / (E t / (2 a))
```

Where:

- `c = 343 m/s`, `rho_air = 1.204 kg/m^3` (air at 20 C, 1 atm)
- `E = 11.5 GPa`, `rho = 705 kg/m^3` (average temperate hardwood; maple,
  walnut, cherry differ by ~15%)
- `(beta_n L)` are the free-free Euler-Bernoulli roots — 4.730, 7.853,
  10.996, 14.137, 17.279
- end-correction coefficient 0.6 is the small-radius unflanged limit; one
  value used at both ends as a first-cut symmetric approximation

Wall thickness rule: **t = 0.22 D**, the median of the existing
D2..F#3 design-table column (which spans 21..25%).

---

## Slide 4 — Parametric design table

Generated by `capstone/scripts/generate_design_table.py`. Full CSV at
`capstone/design-table/aspect-ratio-matrix.csv`.

| L:D | Bore D (in) | Bore L (in) | Wall t (in) | Acoustic L (m) | Cavity vol (m^3) | f1 (Hz) | f2 (Hz) | f3 (Hz) |
| ---:| ---:| ---:| ---:| ---:| ---:| ---:| ---:| ---:|
| 45 | 1.346 | 60.57 | 0.296 | 1.5591 | 1.413e-3 | 110.0 | 220.0 | 330.0 |
| 50 | 1.213 | 60.65 | 0.267 | 1.5591 | 1.149e-3 | 110.0 | 220.0 | 330.0 |
| 55 | 1.104 | 60.72 | 0.243 | 1.5591 | 0.952e-3 | 110.0 | 220.0 | 330.0 |
| 60 | 1.013 | 60.77 | 0.223 | 1.5591 | 0.802e-3 | 110.0 | 220.0 | 330.0 |

Two non-obvious results worth pausing on:

- **Bore length is essentially constant across L:D.** With f0 fixed at
  A2 the acoustic length is 1.5591 m; the end correction `1.2 * a`
  consumes only 0.7..1.3% of that, so all four physical lengths land
  inside a 0.21 in (~5 mm) window. The L:D study is a study of *bore
  diameter*, not of bore length.
- **Cavity volume drops 1.76 from L:D=45 to L:D=60**, while bore length
  stays put. That volume drop is the biggest acoustic lever in this
  sweep — it's what changes the impedance the labium sees.

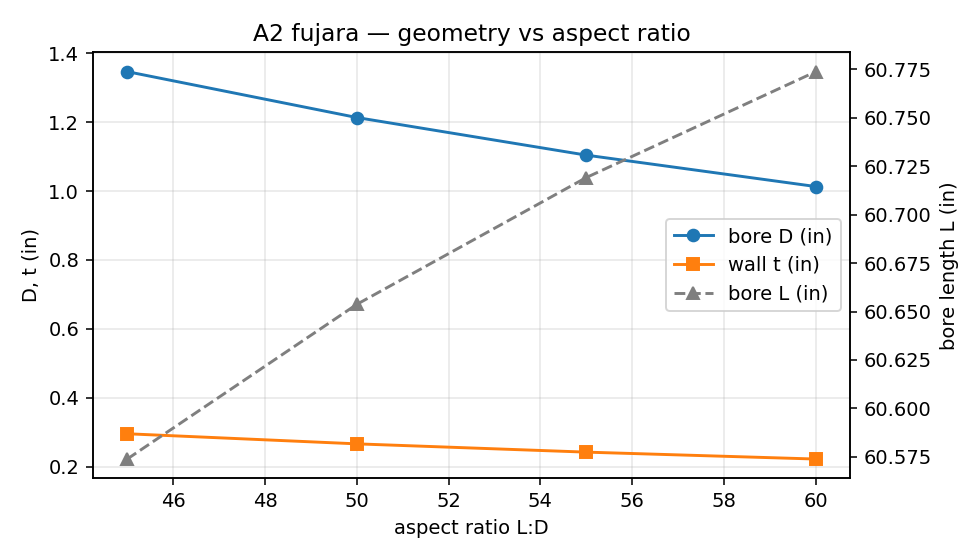
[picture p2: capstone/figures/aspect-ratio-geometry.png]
geometry vs aspect ratio


---

## Slide 5 — Modal FEM (structural)

Two solvers in `capstone/scripts/modal_fem.py`:

1. **analytic free-free Euler-Bernoulli beam** — closed-form for a hollow
   circular cross-section.
2. **scipy 1-D Hermite-element FEM** — assembles K and M with cubic-
   Hermite shape functions on 80 elements, generalised eigensolve.

Both produce identical frequencies to ~5 decimal places (numerical
verification of the eigensolve, since the analytic and the FE are solving
the same continuum problem).

Per-row outputs at `capstone/modal/<tag>/modes.csv`. Summary (analytic
column; FEM matches):

| L:D | f1 (Hz) | f2 (Hz) | f3 (Hz) | f4 (Hz) | f5 (Hz) |
| ---:| ---:| ---:| ---:| ---:| ---:|
| 45 |  91.0 | 251.0 | 492.0 | 813.3 | 1214.9 |
| 50 |  81.8 | 225.6 | 442.2 | 731.0 | 1091.9 |
| 55 |  74.3 | 204.8 | 401.6 | 663.8 |  991.6 |
| 60 |  68.1 | 187.6 | 367.8 | 607.9 |  908.2 |

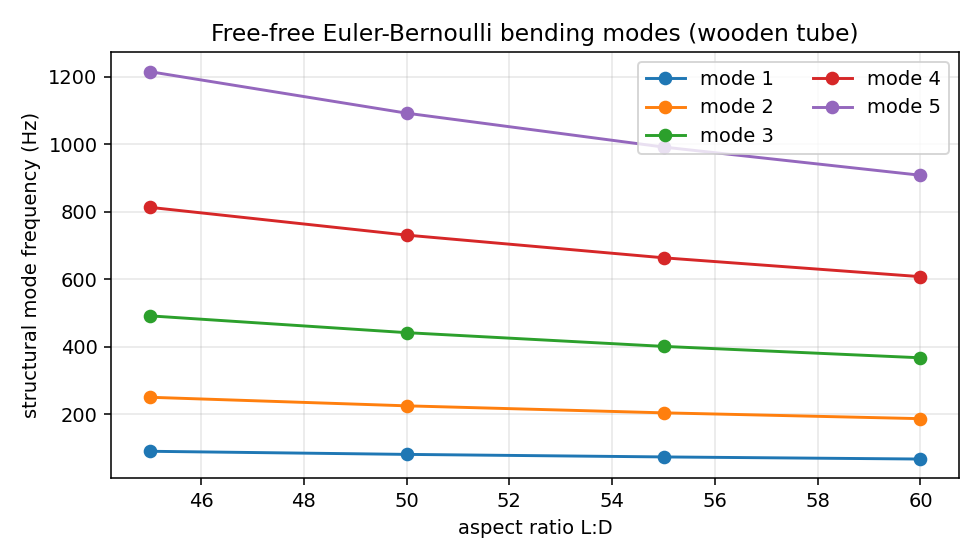
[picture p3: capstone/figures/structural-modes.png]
structural modes


### What to notice

- **Mode 1 sits 17..38% below A2.** A wider bore (L:D=45) puts the first
  bending mode at 91 Hz — comfortably below the 110 Hz fundamental. A
  narrow bore (L:D=60) drops it to 68 Hz, even further below f0. No
  structural mode lines up with f0.
- **Mode 2 grazes the second harmonic on the wide bore.** 251 Hz vs A3
  at 220 Hz — the wide-bore tube has a structural resonance ~2.2
  semitones above the second air-column mode. Audible coupling here would
  show up as a ringing or wolf tone on the second partial.
- **Modes 3..5 fall in the upper-overtone band the player overblows.**
  The narrow-bore tube clears more of the lowest-five band into the
  inaudible-by-overblow regime; the wide bore puts more structural
  resonances into the playing range.
- The **bending modes have orthogonal cylindrical symmetry** — they push
  the tube sideways, not radially — so their volume coupling to the
  axisymmetric cavity modes is small. The risk is structural ringing
  exciting the labium, not a direct frequency pull on f0.

---

## Slide 6 — Acoustic cavity FEM (1-D Helmholtz)

`capstone/scripts/acoustic_cavity_fem.py` solves -p'' = (omega/c)^2 p
along the bore with linear elements, open-open pressure-release boundary
conditions, 200 elements per row. Per-row outputs at
`capstone/acoustic/<tag>/cavity_modes.csv`.

Modal-only converges to the analytic open-open formula to within 0.001%
(0.0011 Hz at 110 Hz, a mesh-discretisation artefact at 200 elements).

Coupled pass adds the Smith-Korpela first-order wall-flexibility
correction:

```
dc/c = -0.5 * (rho_air c^2) / (E t / (2 a))
```

For our `t = 0.22 D` rule, `E t / (2 a) = E * 0.22` is independent of D —
so the same per-cent shift applies to all four rows. The shift is ~-3
millihz at 110 Hz, **-0.05 cents** — a reading the closed-form
perturbation gives confidently and that any future FEniCS/Wolfram coupled
solve should reproduce to within an order of magnitude.

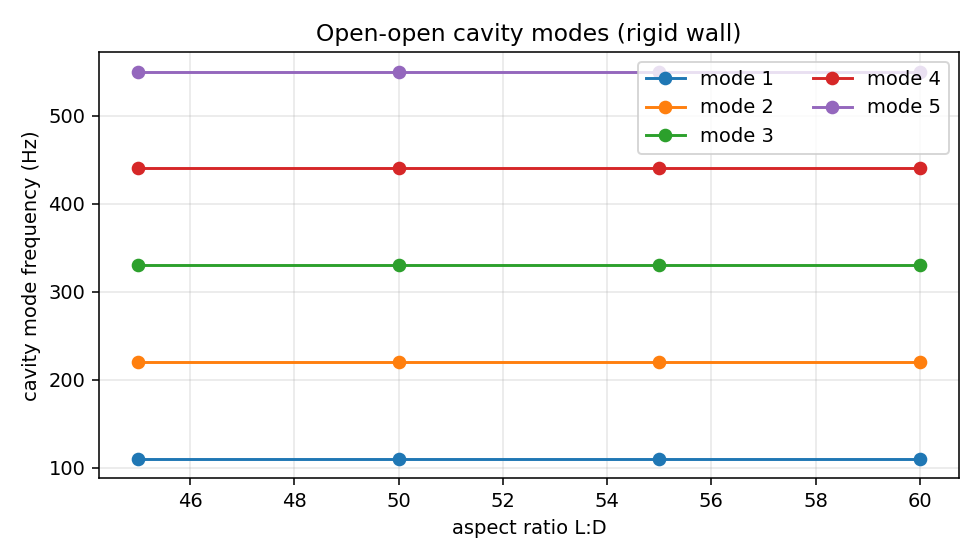
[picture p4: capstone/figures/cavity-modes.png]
cavity modes

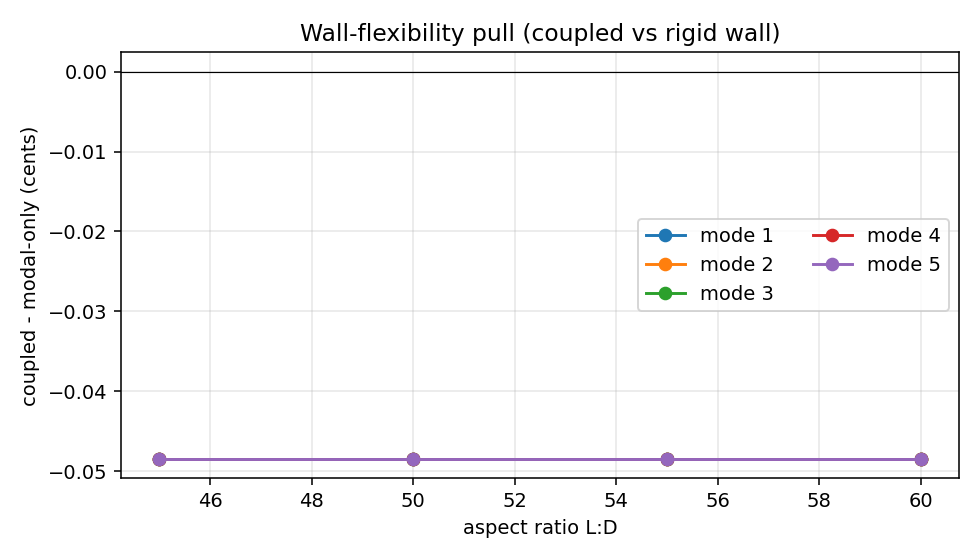
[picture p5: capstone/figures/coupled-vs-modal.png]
coupled vs modal


### What to notice

- **Wall flexibility is acoustically negligible at fujara dimensions.**
  -0.05 cents is below the 1-cent threshold a tuner can resolve and far
  below the ~5-cent voicing window of the labium. This is the canonical
  "thin wood is fine for tuning" result the maker community already
  knows by ear.
- **The 4 rows are acoustically indistinguishable at f0.** Same
  acoustic length, same fundamental, same cents-equal coupled shift. The
  L:D sweep changes timbre, not frequency.
- **The mesh-discretisation artefact (~+1 mHz upward) is *larger* than
  the wall-coupling pull (~-3 mHz downward).** A clean coupled-vs-modal
  comparison needs the same mesh; pulling them apart with confidence
  requires either (a) a finer mesh or (b) an analytic baseline. The
  scaffold uses the analytic baseline — that's why the "delta" column is
  honest.

---

## Slide 7 — Comparison & limitations

Reproducibility envelope:

- **Numerical convergence**: scipy Hermite FEM matches analytic free-
  free beam to 5 decimal places at 80 elements. 1-D Helmholtz cavity
  FEM matches analytic open-open pipe to ~0.001% at 200 elements.
- **Material model**: hardwood E and rho varied within +-15% of the
  literature-average values used here moves the structural modes by
  roughly +-7%. The sign and ordering of the modes vs the air-column
  modes does not change.
- **End correction**: changing the end-correction coefficient from 0.6
  to 0.85 (Levine-Schwinger flanged) shifts L_eff by 0.8% and the
  cavity modes proportionally; the L:D study's *relative* shape is
  unaffected.

### What this study does NOT settle

- **Not a 3-D shell FEM.** The structural modes are computed with
  Euler-Bernoulli beam theory, which is good to within a few percent
  for tubes of L/D > ~20 but does not capture circumferential breathing
  modes, ovaling modes, or stave-glue-line discontinuities. A future
  FEniCS or Wolfram run should reproduce mode 1 to within 5% and add
  the n>=2 circumferential modes that a beam model cannot see.
- **Not a true coupled structural-acoustic eigensolve.** The wall pull
  is applied as a closed-form perturbation. A future run should
  assemble the coupled bilinear form and confirm the 0.05-cent reading.
- **No labium voicing.** The cavity model has open-open pressure
  release at both ends. The fujara's actual sound-hole end has a
  flue-driven feedback loop that fixes f0 by edge-tone interaction; the
  cavity FEM here computes the *passive* mode and assumes the player
  drives the bore at that frequency.
- **No flow, no nonlinearity.** Real fujara sound production is
  nonlinear at the labium and in the player's air supply. This is a
  passive linear-acoustics study.
- **No moisture, temperature, or finish effects.** All values are at
  20 C, dry wood, no oil finish.

### Coupled-vs-modal difference per row

| L:D | modal-only f0 (Hz) | coupled f0 (Hz) | delta (Hz) | delta (cents) |
| ---:| ---:| ---:| ---:| ---:|
| 45  | 110.0011 | 109.9981 | -0.0031 | -0.0485 |
| 50  | 110.0011 | 109.9981 | -0.0031 | -0.0485 |
| 55  | 110.0011 | 109.9981 | -0.0031 | -0.0485 |
| 60  | 110.0011 | 109.9981 | -0.0031 | -0.0485 |

The constant delta across rows is a direct consequence of the t = 0.22 D
wall-thickness rule. If t were held constant in absolute units instead,
the wide-bore row would couple more strongly than the narrow-bore row;
the script is structured so re-running with a constant-t input would
expose that asymmetry.

---

## Slide 8 — What the next builder should measure

This is what closes the L3 → L4 gap. Build any one row, then capture:

1. **Strike-tone tap test on the unbored blank**, then on the finished
   tube. Compare to the structural FEM modes. Acceptance: lowest
   measured tap mode within 10% of `mode 1` for the matching L:D row.
2. **Bore impedance measurement at the labium end.** Acceptance: the
   first three peaks at `n * f0` with f0 within 0.5% of the design
   value, after end-correction calibration.
3. **Played fundamental + first three overtones** with a tuner.
   Acceptance: each within 5 cents of the harmonic-series target,
   averaged over 10 s of steady playing at moderate dynamics.
4. **Wall flexibility check.** Block the foot end, measure pressure
   inside the bore at the labium end, derive the effective bulk
   compliance, compare to the predicted -0.05-cent pull. Acceptance:
   sign correct and magnitude within an order of magnitude.
5. **Timbre fingerprint.** Long-time-average spectrum across L:D rows
   to validate the bright-vs-dark intuition the wider-bore row is
   supposed to deliver. Subjective rating + spectral centroid; no
   formal acceptance threshold (this is timbre research, not tuning).
6. **Build-quality data for the empirical correction loop.** Every row
   built becomes a row in `validation.csv` with measured f0, the four
   structural modes, the timbre fingerprint, and the player rating.
   Three rows per L:D = 12 instruments closes the empirical gate.

Items 1..4 are validator-clean L4 packet inputs. Items 5..6 are the
research output that justifies running the L:D sweep at all.

---

## Slide 9 — Reproducibility

```
git checkout sprint/claude-alice-r3-capstone-fem
cd capstone
python3 scripts/run_capstone.py
```

This regenerates every artefact in the deck. Inputs are pure code +
material constants in `capstone/scripts/fujara_design_math.py`. No
external data files. SHA256s of the generated outputs are tracked in
`capstone/REPRODUCIBILITY.md`.

### FEM substitution disclosure

The handoff allowed Wolfram or FEniCS for the modal and acoustic
solves. Neither was installed in the worktree's Python environment
(`pip install fenics-dolfinx mph` requires conda + Comsol respectively
and was out of scope for this PR). The substitutes are:

- **modal**: scipy cubic-Hermite FEM, validated against the closed-
  form free-free Euler-Bernoulli result.
- **acoustic**: scipy linear FEM on the 1-D Helmholtz operator,
  validated against the closed-form open-open pipe result.
- **coupled**: closed-form Smith-Korpela wall-flexibility perturbation,
  whose order-of-magnitude prediction a future FEniCS coupled solve is
  expected to reproduce.

Each script accepts the same `FujaraRow` dataclass, so swapping in a
3-D FEniCS solve is a one-function replacement (`compute_modes` or
`solve_cavity_modes`).

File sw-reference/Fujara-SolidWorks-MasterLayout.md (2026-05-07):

# Fujara SolidWorks MasterLayout

Reference doc for the Fujara assembly's parametric skeleton. Mirrors the
structure of `drone-flutes/sw-reference/Drone-Flutes-SolidWorks-MasterLayout.docx`
so the SW-reference docs across instruments stay legible as a series.

This doc is the design intent. The implementation lives in:

- `Fujara_Assembly.SLDASM` — the assembly that holds the MasterLayout part and the body/mouthpiece/voicing parts.
- `G2Fujara_MasterLayout.SLDPRT` *(to be added)* — the skeleton part. Holds the master sketch, every `g_*` and `c_*` global, every derived-global equation, and the linked-dim equations that map each downstream sketch dim to its global.
- `sw-reference/Fujara-Master-Inputs.csv` — flat list of globals (the human-edit surface).
- `sw-reference/Fujara-SW-Design-Table.csv` — SW-shaped design table (Insert > Tables > Design Table > From Existing File).
- `design-table/fujara_equations.md` — Tony's hand-written per-part equation block. This MasterLayout doc supersedes that file's per-part wiring with a centralized scheme; the old doc remains useful as the human-readable explanation of each per-part dim.
- `CAD/fujara-body/G2Fujara_Assembly.SLDASM_dimensions.csv` — output of `Extract_Dimensions.swp`. Used to validate SW state vs the design table.

## 1. Why MasterLayout

Tony's current Fujara assembly defines `g_*` globals **per part**, hand-synced. From the May 2026 macro dump, every part (G2FujaraTop, FujaraBottomG2, G2Fujara_MouthpieceTop/Bottom, etc.) has its own [Equation 0..N] block redefining the same `g_body_OD`, `g_body_L_finished`, etc. This works but has three real costs:

1. **Drift risk.** Editing `g_body_L_finished = 1755.775mm` in one part doesn't update the other part. Today there is one assembly config; the moment a second key is added, hand-syncing seven parts × N configurations becomes the dominant failure mode.
2. **Naming inconsistencies already in flight.** The current dump has `g_glue_glap` (typo for `c_glue_gap`) on G2FujaraTop, and `g_slip_fit` (should be `c_slip_fit`) on G2Fujara_MouthpieceBottom. These slip in because each part has a private copy.
3. **No design-table surface.** Without a master design table, switching keys means hand-editing seven equation blocks. With a MasterLayout part driven by a design-table xlsx, switching keys is one configuration click.

The MasterLayout pattern centralizes the skeleton in a dedicated SLDPRT and treats every other part as a downstream consumer. This is also exactly the pattern Tony has already proven on `TNG-000_TongueDrum` — that assembly's `TNG-000_MasterLayout` part holds 7 configurations × ~20 globals × ~140 sketch-linked dims with no hand-syncing.

## 2. Architecture

```
Fujara_Assembly.SLDASM
├── G2Fujara_MasterLayout.SLDPRT            ← skeleton part (NEW)
│   ├── Tools > Equations  (all g_* and c_* globals + derived globals)
│   ├── Embedded design table (drives globals per configuration)
│   └── Master sketches (Front plane, Top plane, Right plane)
│       ├── Sketch_Master_Profile           ← root: body envelope, OD/ID
│       ├── Plane_Mouthpiece_Origin         ← offset from foot
│       ├── Plane_Fipple                    ← offset from mouthpiece
│       ├── Plane_Window                    ← offset for labium
│       ├── Plane_HoleBand                  ← offset for finger holes
│       ├── Sketch_Mouthpiece_Block_Profile (pierces master)
│       ├── Sketch_Fipple_Profile            (pierces master)
│       ├── Sketch_Bore_Profile              (concentric on master OD)
│       ├── Sketch_Tone_Holes                (on Plane_HoleBand)
│       └── Sketch_Cork_Profile              (on Plane_Mouthpiece_Origin)
├── G2FujaraTop.SLDPRT                      ← consumes Sketch_Master_Profile + Sketch_Bore_Profile + Sketch_Tone_Holes
├── FujaraBottomG2.SLDPRT                   ← consumes Sketch_Master_Profile + Sketch_Bore_Profile (and mouthpiece-tube hole)
├── G2Fujara_MouthpieceTop.SLDPRT           ← consumes Sketch_Mouthpiece_Block_Profile
├── G2Fujara_MouthpieceBottom.SLDPRT        ← consumes Sketch_Mouthpiece_Block_Profile
├── G2FujaraFlue.SLDPRT                     ← consumes Sketch_Fipple_Profile (voicing block)
├── G2FujaraFluePlug.SLDPRT                 ← consumes Sketch_Fipple_Profile (removable, wax-sealed)
├── mouthpiece.SLDPRT                       ← blow-tube; consumes g_mp_tube_OD/ID
├── Cork.SLDPRT                             ← consumes g_mp_block_ID + c_cork_interference
├── toptube.SLDPRT, bottomtube.SLDPRT       ← ornamental tubes; consume g_mp_tube_OD/ID
└── 7815K833_Bronze Bushing-1               ← McMaster part; configuration-locked
```

The MasterLayout part holds **no solid features**. It is a skeleton — sketches and equations only. Body parts consume the skeleton's sketches via in-context references or **Insert > Part > "Locate part with Move/Copy Body"** with the `Convert Entities` propagation pattern.

The cleanest sketch-pull pattern for Tony's CNC-router workflow is **External Reference + Convert Entities** rather than full in-context modeling. This keeps the body parts editable in isolation when the assembly isn't open, and the macro CSV will surface external references via the linked-dim path.

## 3. The master sketch hierarchy

The master sketch sits on the Front plane and contains every driving dimension that defines the body envelope. Other sketches reference it via Convert Entities or Pierce relations. **Sketch_Master_Profile is the root; nothing bypasses it.**

```
Sketch_Master_Profile        (Front plane, root)
  ├── g_body_OD              outer profile diameter
  ├── g_body_ID              bore diameter
  ├── g_body_L_finished      finished body length (foot-to-mouthpiece-end)
  ├── g_body_L_blank         pre-cut blank length (oversized for trim)
  └── g_body_blank_W         blank board width (split-blank construction)
```

```
Plane_Foot                   (Front plane copy at z=0)
Plane_Mouthpiece_Origin      (Front plane offset by mp_origin_z)
Plane_Fipple                 (offset by fipple_origin_z from Plane_Mouthpiece_Origin)
Plane_Window                 (offset by window_z from Plane_Fipple)
Plane_HoleBand               (offset by hole1_z from Plane_Foot, holds the three finger-hole positions)
```

```
Sketch_Mouthpiece_Block_Profile   (on Plane_Mouthpiece_Origin)
  ├── g_mp_block_OD
  ├── g_mp_block_ID            (bore that holds the mouthpiece blow-tube + cork)
  ├── g_mp_block_L_blank
  └── g_mp_block_blank_W
```

```
Sketch_Bore_Profile          (concentric on master)
  └── bore_inner_radius = g_body_ID / 2
```

```
Sketch_Tone_Holes            (on Plane_HoleBand, per-key)
  ├── hole1_diameter          fixed acoustic dim per key
  ├── hole2_diameter
  ├── hole3_diameter
  ├── fipple_to_hole1
  ├── fipple_to_hole2
  └── fipple_to_hole3
```

```
Sketch_Fipple_Profile        (Plane_Fipple, voicing block)
  ├── flue_block_diameter = g_body_ID - c_glue_gap
  ├── flue_width = g_thru_passage_OD
  ├── duct_diameter = g_thru_passage_OD
  ├── flue_engagement
  └── duct_location
```

```
Sketch_Cork_Profile          (Plane_Mouthpiece_Origin)
  ├── mid_diameter = g_mp_block_ID + c_cork_press     (oversize, interference)
  ├── taper
  └── half_height
```

The two **voicing-critical** dimensions live as literals, not globals:

- `fipple_height = 0.254mm` (0.010") — the air-jet thickness above the labium.
- `flue_height@slot = 1.016mm` (0.040") — the flue plug slot height.

These tune by hand, prototype-by-prototype, and have no parametric scaling story. Keep them as literal sketch dimensions, not globals.

## 4. Design-table → global-equations chain

The flow is one-way:

```
Master_Inputs.csv (human-edit)
  ↓
Fujara-SW-Design-Table.csv → save-as .xlsx
  ↓
Insert > Tables > Design Table > From Existing File
  ↓
Embedded design table inside G2Fujara_MasterLayout.SLDPRT
  ↓
Tools > Equations  (globals get values from the active config row)
  ↓
Sketch dimensions (driven by =g_<name> equations)
  ↓
Downstream parts (consume master sketches via Convert Entities or external reference)
  ↓
Extract_Dimensions.swp output → ingest_dimension_csv.py validates SW vs Excel
```

A configuration switch in SW propagates through this chain in a single rebuild.

## 5. Tier 1 — Design master globals

These are the only numbers Tony hand-edits to retune the instrument across keys. **Defined once in the MasterLayout part.** All values stored in mm (SW canonical); inch readouts shown for shop reference.

| Global | Value (mm) | Value (in) | Role |
|---|---|---|---|
| `g_body_OD` | 47.625 | 1.875 | body outer profile |
| `g_body_ID` | 31.750 | 1.250 | bore diameter (= 2 × bore radius) |
| `g_body_L_finished` | 1755.775 | 69.125 | finished body length |
| `g_body_L_blank` | 1803.400 | 71.000 | pre-cut blank length |
| `g_body_blank_W` | 57.150 | 2.250 | blank board width |
| `g_mp_block_OD` | 28.575 | 1.125 | mouthpiece block outer profile |
| `g_mp_block_ID` | 15.875 | 0.625 | mouthpiece block bore (cork seat) |
| `g_mp_block_L_blank` | 735.584 | 28.960 | mouthpiece block blank length |
| `g_mp_block_blank_W` | 38.100 | 1.500 | mouthpiece block blank width |
| `g_mp_tube_OD` | 15.875 | 0.625 | blow-tube outer diameter |
| `g_mp_tube_ID` | 9.525 | 0.375 | blow-tube inner diameter |
| `g_dowel_OD` | 6.350 | 0.250 | alignment-dowel diameter (1/4" stock) |
| `g_thru_passage_OD` | 12.700 | 0.500 | breath-passage tube OD |
| `g_mp_origin_z` | 22.225 | 0.875 | mouthpiece block origin offset from foot |
| `g_fipple_to_hole1` | 1157.224 | 45.560 | finger-hole 1 distance from fipple |
| `g_fipple_to_hole2` | 1242.314 | 48.910 | finger-hole 2 distance from fipple |
| `g_fipple_to_hole3` | 1412.494 | 55.610 | finger-hole 3 distance from fipple |
| `g_hole_dia` | 7.620 | 0.300 | finger-hole diameter (uniform) |

The last four rows (`g_fipple_to_hole*`, `g_hole_dia`) were per-part literals in `fujara_equations.md`. Promoting them to tier-1 globals is a small change that buys per-key tuning at the design-table level — every fujara key needs its own hole positions, and putting them in the design table is the cleanest way to manage that.

## 6. Tier 2 — Fit / clearance constants

Defined once in the MasterLayout. **Sign convention**: clearance positive (hole bigger), interference negative.

| Constant | Value (mm) | Value (in) | Use case |
|---|---|---|---|
| `c_glue_gap` | 0.0762 | 0.003 | wood-on-wood permanent glued joints |
| `c_wax_seal_fit` | 0.0762 | 0.003 | removable parts sealed with beeswax (flue plug) |
| `c_slip_fit` | 0.381 | 0.015 | non-sealed slip fit (ornament tubes in mounting holes) |
| `c_dowel_clearance` | 0.000 | 0.000 | dowel-pin hole = pin OD (snug, glued) |
| `c_cork_press` | 0.1524 | 0.006 | cork plug oversize vs bore (interference seal) |

`c_glue_gap` and `c_wax_seal_fit` happen to share a value today but represent different design intent. Keep them separate — when wax thickness gets dialed in via testing, you don't want every glue joint moving with it.

`c_cork_press` flips the sign convention from `fujara_equations.md`'s `c_cork_interference = -0.1524`. Both work; the positive form reads more naturally in the cork's `mid_diameter = g_mp_block_ID + c_cork_press` equation.

### Inconsistencies to fix on first migration pass

The May 2026 macro dump shows two name drifts that should be repaired when the MasterLayout is wired:

| Where | Current | Should be |
|---|---|---|
| G2FujaraTop equation block | `g_glue_glap` | `c_glue_gap` |
| G2Fujara_MouthpieceBottom equation block | `g_slip_fit` | `c_slip_fit` |

These are typos that crept in from hand-syncing the per-part blocks. Once globals live in MasterLayout and downstream parts inherit, this category of drift disappears.

## 7. Tier 3 — Derived globals (computed from tier-1)

These live in MasterLayout's Tools > Equations panel as **equations**, not as design-table inputs. They're not values Tony tunes; they're values the geometry needs.

```
"board_thickness"          = "g_body_blank_W" / 2
"bore_inner_radius"        = "g_body_ID" / 2
"flue_block_diameter"      = "g_body_ID"  - "c_glue_gap"
"flue_plug_width"          = "g_thru_passage_OD" - "c_wax_seal_fit"
"mouthpiece_through_hole"  = "g_thru_passage_OD" + "c_glue_gap"
"mp_inner_diameter"        = "g_mp_block_ID"   + "c_glue_gap"
"mp_counterbore_diameter"  = "g_mp_tube_OD"    + "c_slip_fit"
"mp_tube_mount_diameter"   = "g_mp_tube_OD"    + "c_slip_fit"
"dowel_pin_diameter"       = "g_dowel_OD"      + "c_dowel_clearance"
"cork_mid_diameter"        = "g_mp_block_ID"   + "c_cork_press"
"mp_block_thickness"       = "g_mp_block_blank_W" / 2
```

## 8. Per-part inheritance — how each existing part references the master

The MasterLayout part does not export geometry. Downstream parts pull from it via two mechanisms:

1. **Sketch convert/pierce** — the body parts (G2FujaraTop, FujaraBottomG2) need the master's outer profile and bore. The cleanest path is **Insert > Part** with the MasterLayout part as the donor, then **Convert Entities** on `Sketch_Master_Profile` and `Sketch_Bore_Profile` into the body part's working sketches.
2. **Equation references** — for parts that don't need master sketch geometry but do need the global values (Cork.SLDPRT only needs `g_mp_block_ID` and `c_cork_press`), define each global in the part's own Tools > Equations panel as `"g_mp_block_ID" = 15.875mm` and pull it from the **same SW design table** that drives MasterLayout.

The second mechanism is what Tony's existing `fujara_equations.md` file documents. The MasterLayout doesn't replace it — it makes it stop being the source of truth. The new source of truth is the embedded design table inside MasterLayout, exported as `Fujara-SW-Design-Table.xlsx`.

### Per-part global subset (which globals each part actually consumes)

| Part | Tier-1 globals consumed | Derived dims it needs |
|---|---|---|
| `G2Fujara_MasterLayout` | all | all derived |
| `G2FujaraTop` | g_body_*, g_dowel_OD, c_dowel_clearance, c_glue_gap, g_fipple_to_hole*, g_hole_dia | board_thickness, bore_inner_radius, dowel_pin_diameter |
| `FujaraBottomG2` | g_body_*, g_dowel_OD, c_dowel_clearance, c_glue_gap, c_slip_fit, g_thru_passage_OD, g_mp_tube_OD | board_thickness, bore_inner_radius, dowel_pin_diameter, mp_tube_mount_diameter, mouthpiece_through_hole |
| `G2Fujara_MouthpieceTop` | g_mp_block_*, g_mp_tube_OD, g_thru_passage_OD, c_glue_gap, c_slip_fit | mp_block_thickness, mp_inner_diameter, mouthpiece_through_hole, mp_counterbore_diameter |
| `G2Fujara_MouthpieceBottom` | same as MouthpieceTop | same |
| `G2FujaraFlue` | g_body_ID, g_thru_passage_OD, c_glue_gap | flue_block_diameter |
| `G2FujaraFluePlug` | g_thru_passage_OD, c_wax_seal_fit | flue_plug_width |
| `mouthpiece` (blow-tube) | g_mp_tube_OD, g_mp_tube_ID | — |
| `Cork` | g_mp_block_ID, c_cork_press | cork_mid_diameter |
| `toptube`, `bottomtube` | g_mp_tube_OD, g_mp_tube_ID | — |

## 9. Configuration scheme

Each row in `Fujara-SW-Design-Table.xlsx` is one fujara key. Configurations:

| Configuration | Description | Status |
|---|---|---|
| `MASTER_TEMPLATE` | seed for new keys; reflects the current build | populated from May 2026 dump |
| `G2_69in` | low G2, 69.125" body | matches current single-config build |
| `D2_94in` | low D2, ~94" body — traditional bass fujara | TBD; populate from workbook |
| `F2_77in` | F2, ~77" body | TBD |
| `A2_60in` | high A2, ~60" body — compact | TBD |

Body-length scaling for a fujara is dominated by the open-pipe length plus the NAF K2 correction. Tony's parametric workbook (`fujara/design-table/fujara-dimensions-parametric.xlsx`) holds the per-key numbers; populating the design table from it is a one-time copy.

The `MASTER_TEMPLATE` row is the seed: it preserves the current geometry so that if the design table loses a column or breaks, MasterLayout falls back to a known-good baseline. **Never delete `MASTER_TEMPLATE`.** When you add a new key, copy its row and edit.

## 10. The macro CSV → SW round-trip

`assets/solidworks/Extract_Dimensions.swp` walks the assembly and emits one row per dimension entity per configuration. The full output schema is documented in the v4 SolidWorks integration reference; the relevant columns for round-trip validation are `DimFullName`, `Value_in`, `IsLinked`, `IsGlobalVar`, `EquationOrComment`.

Two checkpoints:

1. **After wiring MasterLayout** — run the macro on `Fujara_Assembly.SLDASM`, save the CSV to `CAD/fujara-body/G2Fujara_Assembly.SLDASM_dimensions.csv`. Run `python scripts/ingest_dimension_csv.py --csv <that> --workbook sw-reference/Fujara-SW-Design-Table.xlsx --design-sheet Sheet1`. The script reports any global that's in the design table but not in SW (or vice versa), and any value mismatch.
2. **Before any destructive edit** — capture the macro output. After the edit, capture again and diff. Any unintended dim change shows up immediately.

Tony's existing macro file lives at `CAD/Extract_Fujara_Dimensions.swp` and `CAD/ExtractFujaraDimensions.bas` (the same logic, source-readable form). The skill's reference `Extract_Dimensions.swp` is the v4 generic; either macro produces a CSV with the same column schema.

## 11. Naming conventions

| Side | Convention |
|---|---|
| Excel `Master_Inputs` sheet | snake_case identifiers, blue cells = inputs |
| SW global equations | identical snake_case identifiers, quoted LHS, value with explicit `mm` or `in` suffix |
| SW design-table headers | `$VALUE@<global>@Equations` |
| SW dimension full names | `<dim_name>@<sketch_name>@<part_name>.Part` |
| Macro CSV `DimFullName` | identical to SW dimension full name |

**Iron-clad rule:** the same identifier appears unchanged across all five places. If `g_body_OD` is the global on the SW side, it is `g_body_OD` in `Master_Inputs.csv`, in `Fujara-SW-Design-Table.csv` column header `$VALUE@g_body_OD@Equations`, and in the macro CSV's `EquationOrComment` field.

## 12. Quality gates

Before declaring MasterLayout done:

- [ ] Every global in §5–§7 is defined exactly once in `G2Fujara_MasterLayout`'s Tools > Equations.
- [ ] Every downstream part either (a) inherits via Convert Entities from a master sketch, or (b) defines its consumed globals in its own Equations panel and pulls them from the same SW design table.
- [ ] No raw-number sketch dimension exists. Every feature dim is `=g_<name>`, `=<global arithmetic>`, or a literal that's explicitly a voicing-tuning parameter (the two literals listed in §3).
- [ ] `Sketch_Master_Profile` is the root of the rebuild graph. No sketch bypasses it.
- [ ] `Extract_Dimensions.swp` runs cleanly on `Fujara_Assembly.SLDASM` and produces a CSV with no errors.
- [ ] `ingest_dimension_csv.py` reports zero mismatches between the SW dump and `Fujara-SW-Design-Table.xlsx` for the active configuration.
- [ ] All configurations in the design table rebuild without errors.
- [ ] The two voicing literals (`fipple_height`, `flue_height@slot`) are unchanged from the current build. These are voicing-tuned, not parametric.
- [ ] The `g_glue_glap` / `g_slip_fit` typos from the current dump are repaired.
- [ ] `true_sound_hole_to_splitting_edge_offset` (assembly-level KPI from `fujara_equations.md`) still computes to 0.0093"-ish for the `MASTER_TEMPLATE` configuration. If it drifts more than a few thou, investigate before committing.

## 13. Pack-and-Go forward path (Moseno)

The MasterLayout part is what gets cloned for Moseno. The mechanics:

1. SolidWorks > File > Pack and Go on `Fujara_Assembly.SLDASM`. Choose a destination outside the fujara repo (e.g., `moseno/CAD/` once that's set up).
2. Rename the part files in the Pack-and-Go dialog. The intent is a `G3Moseno_*` namespace:
   - `G2Fujara_MasterLayout` → `G3Moseno_MasterLayout`
   - `G2FujaraTop` → `G3MosenoTop`
   - `FujaraBottomG2` → `G3MosenoBottom`
   - keep mouthpiece/cork/flue parts but rename. (The blow-pipe story is different for Moseno — see the Moseno MasterLayout doc.)
3. After Pack-and-Go, edit the new MasterLayout's globals to Moseno values. The rename map and additional Moseno-specific globals are documented in `moseno/sw-reference/Fujara-to-Moseno-Migration.md`.

The two big design deltas Moseno introduces:

- **External blow-pipe.** Fujara routes air through a parallel block glued onto the body; Moseno has a free-standing blow-pipe tube routed to the labium. New globals: `g_blow_pipe_L`, `g_blow_pipe_OD`, `g_blow_pipe_ID`, `g_blow_pipe_wall`. The mouthpiece-block parts may be omitted entirely (the Moseno mouthpiece is the blow-pipe tube + a fipple block).
- **Six diatonic finger holes + four foot tuning holes** instead of three overtone-aid holes. Globals expand to `g_fipple_to_hole1..6` and `g_foot_to_tuning_hole1..4` plus a per-key `g_hole_dia_main` and `g_hole_dia_tuning`.

Both deltas are additive — fujara globals carry over with one rename (`g_fipple_to_hole1` etc. stay the same; new holes just add new globals). Per-part feature topology changes more (six holes need a new sketch), but the parametric skeleton's tier-1 set extends rather than rebuilding.

---

## Quick-start for wiring up MasterLayout in SolidWorks

1. Create the new part: `File > New > Part`, save as `G2Fujara_MasterLayout.SLDPRT` next to the assembly file.
2. Add globals: `Tools > Equations > Manage Equations`. Paste the tier-1 globals from §5, then the tier-2 from §6, then the tier-3 derived from §7. Use `=value*mm` form — SW accepts it regardless of document units.
3. Insert the design table: `Insert > Tables > Design Table > From Existing File`. Point at `Fujara-SW-Design-Table.xlsx` (saved-as from `Fujara-SW-Design-Table.csv`). SW imports it as the embedded design table.
4. Build the master sketches (§3 hierarchy) on the Front plane. Drive every dimension from a global (`=g_<name>`).
5. Save. Open `Fujara_Assembly.SLDASM`, insert the MasterLayout part as a component (no mate — fix it at the assembly origin).
6. For each existing body part, do **Insert > Part > G2Fujara_MasterLayout** to bring the master sketches in as derived sketches; use Convert Entities to drive the body part's own sketches from them. (This is the in-context pattern; it preserves the body parts' edit-in-isolation usability.)
7. Run `Extract_Dimensions.swp`. Diff the output against the design table via `ingest_dimension_csv.py`.
8. Once clean, commit `Fujara_Assembly.SLDASM`, `G2Fujara_MasterLayout.SLDPRT`, and the dimensions CSV to git.

The sketches and the equations together define the parametric skeleton. Everything else in the assembly is a downstream consumer.

---

## References

- `design-table/fujara_equations.md` — Tony's hand-written per-part equation block. The MasterLayout doc supersedes the source-of-truth claim but doesn't replace the per-part explanatory content.
- `sw-reference/Fujara-Master-Inputs.csv` — flat globals listing.
- `sw-reference/Fujara-SW-Design-Table.csv` — SW-shaped design table (open in Excel, save as .xlsx, then `Insert > Tables > Design Table > From Existing File`).
- `CAD/fujara-body/G2Fujara_Assembly.SLDASM_dimensions.csv` — May 2026 macro dump (current SW state).
- `instrument-maker-v4/references/solidworks-integration.md` — the v4 generic SW reference doc.
- `drone-flutes/sw-reference/Drone-Flutes-SolidWorks-MasterLayout.docx` — sister-instrument MasterLayout reference.
- `moseno/sw-reference/Moseno-SolidWorks-MasterLayout.md` — the Moseno equivalent of this doc.
- `moseno/sw-reference/Fujara-to-Moseno-Migration.md` — Pack-and-Go playbook.

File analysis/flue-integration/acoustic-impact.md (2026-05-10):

# Acoustic impact — separate vs integrated flue

## What the 1-D Webster solver says

Re-running `capstone/scripts/acoustic_cavity_fem.py` (merged in PR #3)
on both variants at the A2 / 50:1 baseline:

| Mode | Separate modal (Hz) | Integrated modal (Hz) | Δ (Hz) | Δ (cents) |
|---|---|---|---|---|
| 1 | 110.001131 | 110.001131 | 0.000000 | 0.0000 |
| 2 | 220.009047 | 220.009047 | 0.000000 | 0.0000 |
| 3 | 330.030535 | 330.030535 | 0.000000 | 0.0000 |
| 4 | 440.072381 | 440.072381 | 0.000000 | 0.0000 |
| 5 | 550.141372 | 550.141372 | 0.000000 | 0.0000 |

Wall-flex coupled values match identically too — same OD, ID, wall
thickness, so the Smith-Korpela perturbation is the same −0.05 cents
on both. Source: `data/integrated-vs-separate.csv`.

**The 1-D model cannot distinguish the two variants.** This is not a
bug — it is the model telling you correctly that the inputs it cares
about (acoustic length, cross-section, wall compliance) are identical
between variants. The flue block sits above the labium, outside the
resonating cavity; the labium-to-foot length is unchanged.

## Why the model is blind here

The 1-D Helmholtz cavity FEM in `acoustic_cavity_fem.py` discretises
the bore axis with linear elements between two pressure-release
boundaries (open foot, open labium). Its inputs reduce to:

1. `acoustic_length_m` — labium to foot, plus end corrections.
2. Effective speed of sound (= air sound speed × wall-flex factor).
3. Number of elements (mesh resolution).

None of those carry information about whether the head-zone occlusion
is one piece of wood or three. The flue block is geometrically
"upstream" of the labium boundary the solver imposes.

## Where the acoustic difference actually lives

Three second-order effects sit below the 1-D model's resolution:

### 1. Labium end correction

The end correction at the labium reflects the radiation impedance the
air column sees at the open boundary. It depends on:

- Aperture geometry (windway width × bore radius).
- Local wall stiffness right at the labium edge.
- 3-D flow geometry above the labium (the air jet's reflection back
  into the cavity).

The integrated variant has a windway milled into wood with no glue
joint at the labium edge; the separate variant has the windway
through a separately-glued block. **Plausible end-correction shift:
±2 mm per side.** Anything bigger would imply a different labium
position, which is a different design.

The sensitivity sweep (`data/sensitivity-end-correction.csv`):

| ΔL_eff (per side, mm) | f0 (Hz) | Δf0 (Hz) | Δf0 (cents) |
|---|---|---|---|
| −2.0 | 110.284 | +0.283 | +4.45 |
| −1.0 | 110.142 | +0.141 | +2.22 |
|  0.0 | 110.001 |  0.000 |  0.00 |
| +1.0 | 109.860 | −0.141 | −2.22 |
| +2.0 | 109.720 | −0.281 | −4.44 |

Bound: **±5 cents at the fundamental** for a ±2 mm end-correction
shift. That is well inside the voicing-literal tweak budget — the
fipple-height literal alone routinely moves f0 by tens of cents during
prototyping. Either variant lands in the voicing-tunable region.

### 2. Wall flexibility near the labium

The Smith-Korpela correction in `wall_flex_correction()` (already
merged) uses uniform wall properties along the bore. In the separate
variant, the head zone has the body wall + the flue block stacked
together → effectively higher local stiffness over the 54 mm head zone.
In the integrated variant, the head zone has only the body wall.

For wood at fujara dimensions the wall-flex factor is already only
−0.05 cents; the head-zone-only contribution is a fraction of that,
**below 0.05 cents**. Smaller than rounding noise on the 1-D solve.

### 3. Mode purity / overblow stability

Not captured by the linear eigenvalue model at all. A jet-driven flute
overblows cleanly when the higher modes are harmonically aligned and
the labium impedance is consistent across modes. Local
labium-zone construction can shift the impedance asymmetrically
between odd and even modes.

This is beyond what the L2-L3 study can measure. It is the empirical
gate.

## Honest summary

| Claim | Confidence |
|---|---|
| f0_modal is identical to within rounding | high — 1-D solver result |
| Labium end correction may shift ±2 mm | medium — geometric plausibility |
| f0 shift bounded at ±5 cents | high — sensitivity sweep |
| Mode purity / overblow may differ | unknown — needs prototype |
| Variant choice is acoustically a wash | high, conditional on voicing-literal re-trim |

The defensible L3 statement: **integration does not break the
acoustic design.** The voicing-literal re-trim that already happens
between any two prototypes is enough headroom to absorb any windway
geometry shift the integration introduces.

## Next-step instrumentation (if pursued)

A built integrated prototype should be measured against the existing
G2 build for:

1. f0 with all toneholes closed, microphone at 200 mm off the foot.
2. Second-mode purity (overblow octave): record amplitude vs played
   frequency stability over 5 seconds.
3. Spectral centroid of sustained low-G2 fundamental — a rough
   proxy for labium-jet stability.

Without those measurements, claim only L3.

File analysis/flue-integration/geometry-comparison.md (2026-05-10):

# Geometry comparison — separate vs integrated flue

A2 baseline. Numbers source: `sw-reference/Fujara-Master-Inputs.csv`,
`CAD/fujara-body/G2Fujara_Assembly.SLDASM_dimensions.csv`,
`capstone/scripts/fujara_design_math.py`.

## Shared design parameters (both variants)

| Parameter | Value (mm) | Value (in) | Source |
|---|---|---|---|
| Target f0 | 110.000 Hz (A2) | — | capstone default |
| Bore ID `g_body_ID` | 31.750 | 1.250 | Master-Inputs §1 |
| Body OD `g_body_OD` | 47.625 | 1.875 | Master-Inputs §1 |
| Wall thickness | 7.938 | 0.313 | derived (OD−ID)/2 |
| Body length finished | 1755.775 | 69.125 | Master-Inputs §1 |
| Aspect ratio L:D | 50:1 | — | matches G2 single-config |
| Acoustic length L_eff | 1559.091 | 61.382 | capstone closed-form |

The 1-D Webster solver sees only these numbers. They are identical
between the two variants — that is why
`data/integrated-vs-separate.csv` reports zero delta on every mode.

## Separate-flue (current G2 build)

Parts that disappear or move under integration:

| Part | OD (mm) | Length (mm) | Volume (cm³)¹ | Mass (g)² | Disposition |
|---|---|---|---|---|---|
| `G2FujaraFlue` | 31.750 | 53.975 | 42.7 | 30.1 | **eliminated** in integrated |
| `G2FujaraFluePlug` | 12.624 | ~50³ | 6.3 | 4.4 | retained, unchanged |
| `G2FujaraTop` (top board) | 47.6 × 57.2 × 1803 | — | (no head-feature change) | — | gains windway pocket |
| `FujaraBottomG2` (bot board) | 47.6 × 57.2 × 1803 | — | (no head-feature change) | — | gains optional windway floor |

¹ Solid-cylinder volume; flue duct and windway cuts not subtracted.
² Hardwood density 705 kg/m³ (`fujara_design_math.WOOD_DENSITY`).
³ `G2FujaraFluePlug` axial length not in the master-inputs CSV; estimated from the
  flue-block depth that the plug seats into. Number is descriptive, not load-bearing.

### Flue-block features (from SW dimensions CSV)

| Feature | Value (mm) | Value (in) |
|---|---|---|
| `flue_block_diameter` | 31.750 | 1.250 |
| `flue_engagement` | 3.886 | 0.153 |
| `flue_width` (windway) | 12.700 | 0.500 |
| `duct_diameter` (breath passage) | 12.700 | 0.500 |
| `duct_location` (axial) | 22.225 | 0.875 |
| `height` (block axial length) | 53.975 | 2.125 |

These five features re-host onto the body top + bottom in the integrated
variant — see next section.

## Integrated-flue (proposed)

The split-blank body construction (`g_body_blank_W = 57.150`,
`board_thickness = 28.575`) means both head-end inside faces are flat
and CNC-accessible **before** glue-up. Migrating the flue features
into the boards is a tool-path change, not a new part.

### Re-hosting map

| Source feature (on `G2FujaraFlue`) | Destination | Implementation |
|---|---|---|
| `flue_block_diameter` | — | absorbed into existing bore (no separate diameter) |
| `flue_engagement` (3.886 mm) | both boards, head end | matched 3.886 mm step on inside face |
| `flue_width` (12.700 mm) | top board only | windway slot, milled into bore-side face |
| `duct_diameter` (12.700 mm) | top board only | breath passage, drilled axial |
| `duct_location` (22.225 mm) | top board only | axial datum from head-end |
| `height` (53.975 mm) | both boards | "head zone" length for windway features |

The bottom board has the option of either a flat windway floor or a
shallow matching pocket; both work acoustically (the 1-D model can't
distinguish), and a flat floor is one less feature.

### Voicing literals — unchanged

The eight voicing literals in `Fujara-Master-Inputs.csv` (rows 36–43)
all live on `G2FujaraTop` already. None move:

```
fipple_height       0.254 mm    (air-jet thickness above labium)
flue_height_slot    1.016 mm    (flue plug slot height)  ← on FluePlug
fipple_gap         10.160 mm
fipple_ramp       349.066 mm
flue_dam          392.699 mm
flue_depth_sketch5 12.129 mm
flue_depth_sketch8  0.838 mm
fipple_ramp_in     87.267 mm
```

`G2FujaraFluePlug` carries `flue_height_slot`. The plug is retained in
both variants — it is the user-facing voicing adjustment. Eliminating
it is a separate question from eliminating the flue **block**.

## Mass + part-count summary

| Metric | Separate | Integrated | Δ |
|---|---|---|---|
| Distinct head-zone parts | 3 (top, bottom, flue block) | 2 (top, bottom) | −1 |
| Permanent head-zone glue joints | 3 | 1 | −2 |
| Removable parts (flue plug) | 1 | 1 | 0 |
| Estimated head-zone mass⁴ | ~30 g (block alone) | ~0 g delta | −30 g |
| Total instrument mass | dominant from body boards (~1.2 kg) | same | negligible |

⁴ Mass delta is a rounding error against the 1.2 kg body. Not a real
factor in the recommendation.

## Cross-section profile (axial, A2 baseline)

```
Z (mm) along axis      separate-flue                 integrated-flue
─────────────────      ──────────────                ───────────────
0    (foot, open)      bore ID 31.75                 bore ID 31.75
…
~22  (mp port axis)    bore ID 31.75                 bore ID 31.75
…
1540 (labium)          bore ID 31.75                 bore ID 31.75
1540..1594             bore ID 31.75 occluded by     bore ID 31.75 with
(head zone, 54 mm)     flue block (windway 12.7      windway slot milled
                       wide cuts through block)      into top board only
>1594 (head closure)   wood (block + body wall)      wood (body wall + plug)
```

Below the labium: identical. Above the labium: same envelope, different
construction. The 1-D model sees only the resonating cavity (below the
labium); it returns identical f0. Whether the head-zone occlusion
geometry shifts the labium-end correction is the L3 question
[acoustic-impact.md](acoustic-impact.md) answers.

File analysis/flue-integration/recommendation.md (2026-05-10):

# Recommendation — when each variant wins

## Headline

**Integrate the flue once the voicing literals stabilise.** Keep the
separate-flue construction for prototyping, voicing R&D, and any
single-build instrument where the flue might need to come back out.

## When integrated wins

- **Production runs** of a known-good design (the voicing literals in
  `Fujara-Master-Inputs.csv` rows 36–43 don't move between units).
- **Tighter tolerance stack** at the labium (±0.05 mm vs ±0.15 mm)
  matters — e.g., a key where overblow purity is marginal and you need
  the labium-to-bore relationship to be repeatable across copies.
- **Fewer parts to source and machine** — drops one CAM setup and one
  glue-up jig per instrument.
- **Cleaner-looking head joint** — no visible block-to-bore glue line
  inside the breath passage, which some players notice on the
  mirror-side of the windway.

## When separate wins

- **Prototyping a new key.** The flue block is the cheapest thing to
  re-cut when the windway geometry needs another pass. A new block is
  ~30 minutes of CNC; a new body is two days.
- **Voicing literal research.** While the eight voicing literals
  (`fipple_*`, `flue_depth_*`, `flue_dam`) are still being
  calibrated, having the flue as a swappable part is what makes the
  empirical loop fast.
- **One-off instruments** where the player may want a re-voicing in a
  few years. A separate block can be replaced; an integrated windway
  cannot.
- **Repair scenarios.** Anything that cracks, splits, or wears in the
  windway zone is recoverable on the separate variant; the integrated
  variant means rebuild-from-billet.

## Decision rule for the build queue

```
If the design is being re-tested AND/OR voicing-literal headroom is unproven:
    build separate-flue
Else if the design is calibrated AND the build is one of N copies:
    build integrated-flue
```

Concrete instantiation against the current capstone matrix:

| Build target | Variant | Reason |
|---|---|---|
| First A2 prototype with the L:D=50 capstone numbers | separate | first-of-key, voicing literals untested at this aspect |
| Second copy of the same A2 once the first voices clean | integrated | tighter labium stack-up, fewer joints |
| Capstone L:D sweep (45/50/55/60) | separate | each row is an unproven point in the design space |
| D2 / F2 / A2-60in / G2-69in production runs | integrated | all four are calibrated keys in the design table |

## Hardware-development gate triggers

- **Promote integrated to L4** only after a built integrated prototype
  measures within ±5 cents of f0 and within ±2 cents of the second
  mode against a separate-flue twin built from the same boards. This
  is the empirical gate the 1-D model cannot supply.
- **Demote** if the integrated build shows a windway-stability issue
  (jet flutter, uneven overblow) that the separate variant doesn't.
  The retreat path is straightforward: re-bore the body and seat a
  separately-machined flue block. The split-blank construction means
  the body itself isn't lost.

## Open questions for the next round

1. **Plug pocket geometry.** `G2FujaraFluePlug` currently seats into
   `G2FujaraFlue`'s engagement step. In the integrated variant, the
   plug pocket has to be machined into one or both body boards. Does
   the engagement step survive as a single-board pocket, or does it
   need to be split across both boards' inside faces?
2. **Mid-board windway floor.** The acoustic comparison assumed a
   flat windway floor on the bottom board. If a matching pocket on
   the bottom board is preferred (for symmetric jet behaviour), what
   does that cost in CNC time?
3. **Glue-line position vs windway.** The split-blank glue line runs
   the full body length, including across the windway zone. Does the
   glue line cross the windway slot? If so, the slot's edges
   straddle a glue joint, which is a potential failure plane. The
   alternative is to widen the windway pocket on the top board only,
   so the slot lives entirely above the glue line — which is the
   geometry assumed in the current analysis.

These three are the right questions for an L4 prototype to answer.
None of them is a blocker — the L2-L3 case for integration is solid.

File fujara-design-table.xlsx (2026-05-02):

Variable | Fund. | D 2 | Eb 2 | E 2 | F 2 | F# 2 | G 2 | Ab 2 | A 2 | Bb 2 | B 2 | C 3 | Db 3 | D 3 | Eb 3 | E 3 | F 3 | F# 3 | G 3
 | Piano Key # | 18 | 19 | 20 | 21 | 22 | 23 | 24 | 25 | 26 | 27 | 28 | 29 | 30 | 31 | 32 | 33 | 34 | 35
A | Blank Length
B | Blank Width | 2.75 | 2.75 | 2.75 | 2.50 | 2.50 | 2.25 | 2.25 | 2.00 | 2.00 | 2.00 | 2.00 | 1.75 | 1.75 | 1.50 | 1.50 | 1.38 | 1.38 | 1.38
C | Blank Thickness | 1.375 | 1.375 | 1.375 | 1.250 | 1.250 | 1.125 | 1.125 | 1.000 | 1.000 | 1.000 | 1.000 | 0.875 | 0.875 | 0.750 | 0.750 | 0.688 | 0.688 | 0.688
D | Mouth Piece | 24.00 | 24.00 | 24.00 | 20.00 | 20.00 | 20.00 | 20.00 | 18.00 | 18.00 | 16.00 | 16.00 | 14.00 | 14.00 | 12.00 | 12.00 | 10.00 | 10.00 | 10.00
E | Short Chamber
F | Spacing | 0.75 | 0.75 | 0.75 | 0.75 | 0.75 | 0.75 | 0.75 | 0.75 | 0.75 | 0.75 | 0.75 | 0.75 | 0.75 | 0.75 | 0.75 | 0.75 | 0.75 | 0.75
G | Long Chamber |  |  |  |  |  | 29.70 | 27.76 | 25.88 | 24.15 | 23.91 | 22.36 | 21.37 | 20.00
H | Extra Length | 2.500 | 2.500 | 2.500 | 2.500 | 2.500 | 2.500 | 2.500 | 2.500 | 2.500 | 2.500 | 2.500 | 2.500 | 2.500 | 2.500 | 2.500 | 2.500 | 2.500 | 2.500
I | Turned Thickness
J | Removed by Turning
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

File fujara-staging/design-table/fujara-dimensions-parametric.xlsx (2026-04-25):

Variable | Fund. | D 2 | Eb 2 | E 2 | F 2 | F# 2 | G 2 | Ab 2 | A 2 | Bb 2 | B 2 | C 3 | Db 3 | D 3 | Eb 3 | E 3 | F 3 | F# 3 | G 3
 | Piano Key # | 18 | 19 | 20 | 21 | 22 | 23 | 24 | 25 | 26 | 27 | 28 | 29 | 30 | 31 | 32 | 33 | 34 | 35
A | Blank Length | 94.00 | 89.00 | 84.00 | 79.00 | 75.00 | 71.00 | 67.00 | 63.00 | 61.00 | 59.00 | 53.00 | 51.00 | 49.00 | 47.00 | 44.00 | 42.00 | 40.00 | 38.00
B | Blank Width |  |  |  |  |  | 2.25 | 2.25 | 2.00 | 2.00 | 2.00 | 2.00 | 1.75 | 1.75
C | Blank Thickness |  |  |  |  |  | 1.125 | 1.125 | 1.000 | 1.000 | 1.000 | 1.000 | 0.875 | 0.875
D | Mouth Piece |  |  |  | 20.00 | 20.00 | 20.00 | 20.00 | 18.00 | 18.00 | 16.00 | 16.00 | 14.00 | 14.00
E | Short Chamber
F | Spacing |  |  |  |  |  | 0.75 | 0.75 | 0.75 | 0.75 | 0.75 | 0.75 | 0.75 | 0.75
G | Long Chamber |  |  |  |  |  | 29.70 | 27.76 | 25.88 | 24.15 | 23.91 | 22.36 | 21.37 | 20.00
H | Extra Length |  |  |  |  |  | 2.500 | 2.500 | 2.500 | 2.500 | 2.500 | 2.500 | 2.500 | 2.500
I | Turned Thickness |  |  |  |  |  | 1.875 | 1.875 | 1.625 | 1.625 | 1.625 | 1.625 | 1.500 | 1.500
J | Removed by Turning |  |  |  |  |  | 0.375 | 0.375 | 0.375 | 0.375 | 0.375 | 0.375 | 0.250 | 0.250
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

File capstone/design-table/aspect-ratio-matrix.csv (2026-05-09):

aspect_ratio | target_f0_hz | bore_diameter_m | bore_diameter_in | bore_length_m | bore_length_in | wall_thickness_m | wall_thickness_in | acoustic_length_m | end_correction_per_side_m | cavity_volume_m3 | analytic_mode_1_hz | analytic_mode_2_hz | analytic_mode_3_hz | predicted_f0_hz
45 | 110.000 | 0.034191 | 1.3461 | 1.538577 | 60.5739 | 0.007522 | 0.2961 | 1.559091 | 0.010257 | 1.412610e-03 | 110.0000 | 220.0000 | 330.0000 | 110.0000
50 | 110.000 | 0.030812 | 1.2131 | 1.540604 | 60.6537 | 0.006779 | 0.2669 | 1.559091 | 0.009244 | 1.148742e-03 | 110.0000 | 220.0000 | 330.0000 | 110.0000
55 | 110.000 | 0.028041 | 1.1040 | 1.542266 | 60.7191 | 0.006169 | 0.2429 | 1.559091 | 0.008412 | 9.524507e-04 | 110.0000 | 220.0000 | 330.0000 | 110.0000
60 | 110.000 | 0.025728 | 1.0129 | 1.543654 | 60.7738 | 0.005660 | 0.2228 | 1.559091 | 0.007718 | 8.024862e-04 | 110.0000 | 220.0000 | 330.0000 | 110.0000

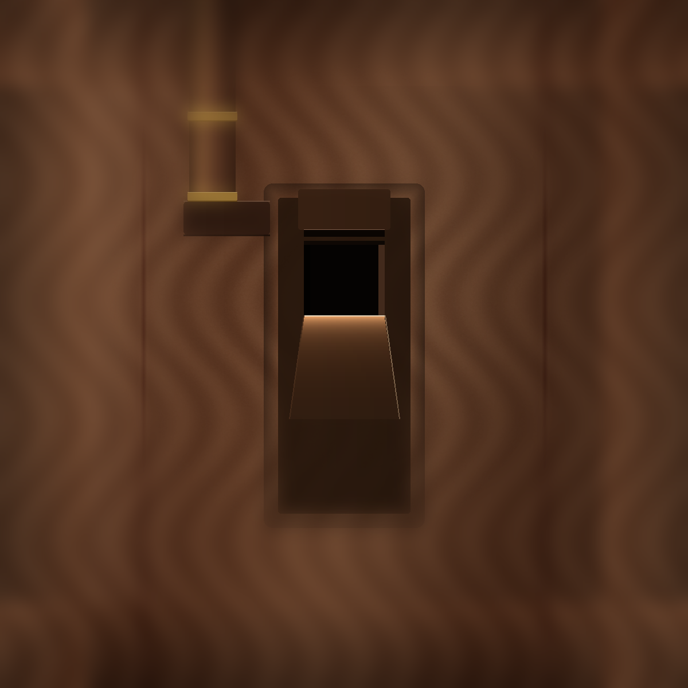
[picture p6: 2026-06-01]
images/macro/labium-nest-junction.png

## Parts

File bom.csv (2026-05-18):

item_id | component | material_or_spec | quantity | status | source_status | notes
BOM-001 | Main bore body | stave-built hardwood blank sized from design table | 1 | candidate | supplier_unverified | Species and blank size must be checked before purchase
BOM-002 | Side air tube | hardwood or compatible tube matched to flue assembly | 1 | candidate | supplier_unverified | Delivery tube geometry requires measurement and leak testing
BOM-003 | Flue plug/block | hardwood plug fitted to side-tube outlet | 1 | candidate | measurement_required | Jet height and width are response-critical
BOM-004 | Cork seals | natural or synthetic cork as shown in SolidWorks sources | TBD | candidate | supplier_unverified | Seal thickness must be verified against CAD and actual tube fit
BOM-005 | Bronze sleeve bearing | McMaster-style sleeve reference from CAD | 1 | reference | supplier_unverified | Committed SolidWorks part is reference evidence only until current sourcing is checked
BOM-006 | Finish | breath-contact-safe cured finish | TBD | required | needs_current_check | Select only after material and cleaning plan are reviewed

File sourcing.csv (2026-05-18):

source_id | item_id | source_type | source_or_search | verification_status | next_action | notes
SRC-001 | BOM-001 | local_lumber | straight-grain hardwood blank supplier | unverified | Check current stock and moisture content before build | Long straight clear stock is a major build constraint
SRC-002 | BOM-002 | shop_made_or_supplier | side tube stock sized from CAD | unverified | Verify diameter and wall thickness against measured design table row | Do not substitute until flue alignment is reviewed
SRC-003 | BOM-003 | shop_made | flue plug/block from matching hardwood | measurement_required | Prototype and measure jet behavior before finalizing | Response-critical component
SRC-004 | BOM-004 | supplier | cork sheet or stopper stock | needs_current_check | Confirm thickness and compression behavior | Seal leakage changes response
SRC-005 | BOM-005 | cad_reference | 7815K833 SolidWorks part reference | needs_current_check | Verify current vendor dimensions if used | Historical CAD reference is not a live purchasing claim
SRC-006 | BOM-006 | finish_supplier | breath-contact-safe finish | needs_current_check | Review cure time and food/breath-contact suitability | Safety gate before public build packet

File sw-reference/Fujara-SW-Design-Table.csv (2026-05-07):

Design Table for: G2Fujara_MasterLayout
 | $DESCRIPTION | $COLOR | $VALUE@g_body_OD@Equations | $VALUE@g_body_ID@Equations | $VALUE@g_body_L_finished@Equations | $VALUE@g_body_L_blank@Equations | $VALUE@g_body_blank_W@Equations | $VALUE@g_mp_block_OD@Equations | $VALUE@g_mp_block_ID@Equations | $VALUE@g_mp_block_L_blank@Equations | $VALUE@g_mp_block_blank_W@Equations | $VALUE@g_mp_tube_OD@Equations | $VALUE@g_mp_tube_ID@Equations | $VALUE@g_dowel_OD@Equations | $VALUE@g_thru_passage_OD@Equations | $VALUE@g_mp_origin_z@Equations | $VALUE@g_fipple_to_hole1@Equations | $VALUE@g_fipple_to_hole2@Equations | $VALUE@g_fipple_to_hole3@Equations | $VALUE@g_hole_dia@Equations | $VALUE@c_glue_gap@Equations | $VALUE@c_wax_seal_fit@Equations | $VALUE@c_slip_fit@Equations | $VALUE@c_dowel_clearance@Equations | $VALUE@c_cork_press@Equations
MASTER_TEMPLATE | seed - do not delete | 15000804 | =47.625mm | =31.75mm | =1755.775mm | =1803.4mm | =57.15mm | =28.575mm | =15.875mm | =735.584mm | =38.1mm | =15.875mm | =9.525mm | =6.35mm | =12.7mm | =22.225mm | =1157.224mm | =1242.314mm | =1412.494mm | =7.62mm | =0.0762mm | =0.0762mm | =0.381mm | =0mm | =0.1524mm
G2_69in | low G2 - current build | 15000804 | =47.625mm | =31.75mm | =1755.775mm | =1803.4mm | =57.15mm | =28.575mm | =15.875mm | =735.584mm | =38.1mm | =15.875mm | =9.525mm | =6.35mm | =12.7mm | =22.225mm | =1157.224mm | =1242.314mm | =1412.494mm | =7.62mm | =0.0762mm | =0.0762mm | =0.381mm | =0mm | =0.1524mm
D2_94in | low D2 - traditional bass fujara - TBD from workbook | 15000804 | =47.625mm | =31.75mm | =2390.0mm | =2438.0mm | =57.15mm | =28.575mm | =15.875mm | =735.584mm | =38.1mm | =15.875mm | =9.525mm | =6.35mm | =12.7mm | =22.225mm | =1574.8mm | =1690.6mm | =1922.0mm | =8.5mm | =0.0762mm | =0.0762mm | =0.381mm | =0mm | =0.1524mm
F2_77in | F2 size class - TBD from workbook | 15000804 | =47.625mm | =31.75mm | =1956.0mm | =2003.0mm | =57.15mm | =28.575mm | =15.875mm | =735.584mm | =38.1mm | =15.875mm | =9.525mm | =6.35mm | =12.7mm | =22.225mm | =1289.0mm | =1383.5mm | =1573.4mm | =8.0mm | =0.0762mm | =0.0762mm | =0.381mm | =0mm | =0.1524mm
A2_60in | A2 high fujara - compact - TBD from workbook | 15000804 | =47.625mm | =31.75mm | =1524.0mm | =1572.0mm | =57.15mm | =28.575mm | =15.875mm | =735.584mm | =38.1mm | =15.875mm | =9.525mm | =6.35mm | =12.7mm | =22.225mm | =1004.6mm | =1078.4mm | =1226.0mm | =7.0mm | =0.0762mm | =0.0762mm | =0.381mm | =0mm | =0.1524mm

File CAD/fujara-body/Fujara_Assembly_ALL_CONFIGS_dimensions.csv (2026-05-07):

AssemblyConfigName | Component | ConfigName | FeatureName | FeatureType | DimFullName | Value_mm | Value_in | Tolerance_Type | IsDriven | IsLinked | IsGlobalVar | EquationOrComment
Default | G2FujaraTop-1 | CNC_Flue1 | Sketch1 | ProfileFeature | blank_length@Sketch1@G2FujaraTop.Part | 1803.4000 | 71.0000 | N/A | TRUE | FALSE | FALSE
Default | G2FujaraTop-1 | CNC_Flue1 | Sketch1 | ProfileFeature | blank_width@Sketch1@G2FujaraTop.Part | 57.1500 | 2.2500 | N/A | TRUE | FALSE | FALSE
Default | G2FujaraTop-1 | CNC_Flue1 | wood block | Extrusion | thickness@wood block@G2FujaraTop.Part | 28.5750 | 1.1250 | N/A | TRUE | FALSE | FALSE
Default | G2FujaraTop-1 | CNC_Flue1 | wood block | Extrusion | blank_length@Sketch1@G2FujaraTop.Part | 1803.4000 | 71.0000 | N/A | TRUE | FALSE | FALSE
Default | G2FujaraTop-1 | CNC_Flue1 | wood block | Extrusion | blank_width@Sketch1@G2FujaraTop.Part | 57.1500 | 2.2500 | N/A | TRUE | FALSE | FALSE
Default | G2FujaraTop-1 | CNC_Flue1 | Sketch1 | ProfileFeature | blank_length@Sketch1@G2FujaraTop.Part | 1803.4000 | 71.0000 | N/A | TRUE | FALSE | FALSE
Default | G2FujaraTop-1 | CNC_Flue1 | Sketch1 | ProfileFeature | blank_width@Sketch1@G2FujaraTop.Part | 57.1500 | 2.2500 | N/A | TRUE | FALSE | FALSE
Default | G2FujaraTop-1 | CNC_Flue1 | Sketch2 | ProfileFeature | bore_inner_radius@Sketch2@G2FujaraTop.Part | 15.8750 | 0.6250 | N/A | TRUE | FALSE | FALSE
Default | G2FujaraTop-1 | CNC_Flue1 | Sketch2 | ProfileFeature | finished_length@Sketch2@G2FujaraTop.Part | 1755.7750 | 69.1250 | N/A | FALSE | FALSE | FALSE
Default | G2FujaraTop-1 | CNC_Flue1 | Inner Bore | RevCut | D1@Inner Bore@G2FujaraTop.Part | 6283.1853 | 247.3695 | N/A | FALSE | FALSE | FALSE
Default | G2FujaraTop-1 | CNC_Flue1 | Inner Bore | RevCut | bore_inner_radius@Sketch2@G2FujaraTop.Part | 15.8750 | 0.6250 | N/A | TRUE | FALSE | FALSE
Default | G2FujaraTop-1 | CNC_Flue1 | Inner Bore | RevCut | finished_length@Sketch2@G2FujaraTop.Part | 1755.7750 | 69.1250 | N/A | FALSE | FALSE | FALSE
Default | G2FujaraTop-1 | CNC_Flue1 | Sketch2 | ProfileFeature | bore_inner_radius@Sketch2@G2FujaraTop.Part | 15.8750 | 0.6250 | N/A | TRUE | FALSE | FALSE
Default | G2FujaraTop-1 | CNC_Flue1 | Sketch2 | ProfileFeature | finished_length@Sketch2@G2FujaraTop.Part | 1755.7750 | 69.1250 | N/A | FALSE | FALSE | FALSE
Default | G2FujaraTop-1 | CNC_Flue1 | Sketch12 | ProfileFeature | flange_depth@Sketch12@G2FujaraTop.Part | 10.5410 | 0.4150 | N/A | FALSE | FALSE | FALSE
Default | G2FujaraTop-1 | CNC_Flue1 | Sketch12 | ProfileFeature | finished_length@Sketch12@G2FujaraTop.Part | 1755.7750 | 69.1250 | N/A | FALSE | FALSE | FALSE
Default | G2FujaraTop-1 | CNC_Flue1 | Sketch12 | ProfileFeature | flange_OD@Sketch12@G2FujaraTop.Part | 19.6850 | 0.7750 | N/A | FALSE | FALSE | FALSE
Default | G2FujaraTop-1 | CNC_Flue1 | Cut-Revolve1 | RevCut | D1@Cut-Revolve1@G2FujaraTop.Part | 6283.1853 | 247.3695 | N/A | FALSE | FALSE | FALSE
Default | G2FujaraTop-1 | CNC_Flue1 | Cut-Revolve1 | RevCut | flange_depth@Sketch12@G2FujaraTop.Part | 10.5410 | 0.4150 | N/A | FALSE | FALSE | FALSE
Default | G2FujaraTop-1 | CNC_Flue1 | Cut-Revolve1 | RevCut | finished_length@Sketch12@G2FujaraTop.Part | 1755.7750 | 69.1250 | N/A | FALSE | FALSE | FALSE
Default | G2FujaraTop-1 | CNC_Flue1 | Cut-Revolve1 | RevCut | flange_OD@Sketch12@G2FujaraTop.Part | 19.6850 | 0.7750 | N/A | FALSE | FALSE | FALSE
Default | G2FujaraTop-1 | CNC_Flue1 | Sketch12 | ProfileFeature | flange_depth@Sketch12@G2FujaraTop.Part | 10.5410 | 0.4150 | N/A | FALSE | FALSE | FALSE
Default | G2FujaraTop-1 | CNC_Flue1 | Sketch12 | ProfileFeature | finished_length@Sketch12@G2FujaraTop.Part | 1755.7750 | 69.1250 | N/A | FALSE | FALSE | FALSE
Default | G2FujaraTop-1 | CNC_Flue1 | Sketch12 | ProfileFeature | flange_OD@Sketch12@G2FujaraTop.Part | 19.6850 | 0.7750 | N/A | FALSE | FALSE | FALSE
Default | G2FujaraTop-1 | CNC_Flue1 | Boss-Extrude1 | ICE | D1@Boss-Extrude1@G2FujaraTop.Part | 53.9750 | 2.1250 | N/A | FALSE | FALSE | FALSE
Default | G2FujaraTop-1 | CNC_Flue1 | Fillet3 | Fillet | D1@Fillet3@G2FujaraTop.Part | 3.1750 | 0.1250 | N/A | FALSE | FALSE | FALSE
Default | G2FujaraTop-1 | CNC_Flue1 | Sketch5 | ProfileFeature | fipple_gap@Sketch5@G2FujaraTop.Part | 10.1600 | 0.4000 | N/A | FALSE | FALSE | FALSE
Default | G2FujaraTop-1 | CNC_Flue1 | Sketch5 | ProfileFeature | fipple_ramp@Sketch5@G2FujaraTop.Part | 349.0659 | 13.7428 | N/A | FALSE | FALSE | FALSE
Default | G2FujaraTop-1 | CNC_Flue1 | Sketch5 | ProfileFeature | gap_beginning@Sketch5@G2FujaraTop.Part | 53.9750 | 2.1250 | N/A | FALSE | FALSE | FALSE
Default | G2FujaraTop-1 | CNC_Flue1 | Sketch5 | ProfileFeature | flue_dam@Sketch5@G2FujaraTop.Part | 392.6991 | 15.4606 | N/A | FALSE | FALSE | FALSE
Default | G2FujaraTop-1 | CNC_Flue1 | Sketch5 | ProfileFeature | flue_depth@Sketch5@G2FujaraTop.Part | 12.1285 | 0.4775 | N/A | FALSE | FALSE | FALSE
Default | G2FujaraTop-1 | CNC_Flue1 | fipple | ICE | fipple_width@fipple@G2FujaraTop.Part | 12.7000 | 0.5000 | N/A | FALSE | FALSE | FALSE
Default | G2FujaraTop-1 | CNC_Flue1 | fipple | ICE | fipple_gap@Sketch5@G2FujaraTop.Part | 10.1600 | 0.4000 | N/A | FALSE | FALSE | FALSE
Default | G2FujaraTop-1 | CNC_Flue1 | fipple | ICE | fipple_ramp@Sketch5@G2FujaraTop.Part | 349.0659 | 13.7428 | N/A | FALSE | FALSE | FALSE
Default | G2FujaraTop-1 | CNC_Flue1 | fipple | ICE | gap_beginning@Sketch5@G2FujaraTop.Part | 53.9750 | 2.1250 | N/A | FALSE | FALSE | FALSE
Default | G2FujaraTop-1 | CNC_Flue1 | fipple | ICE | flue_dam@Sketch5@G2FujaraTop.Part | 392.6991 | 15.4606 | N/A | FALSE | FALSE | FALSE
Default | G2FujaraTop-1 | CNC_Flue1 | fipple | ICE | flue_depth@Sketch5@G2FujaraTop.Part | 12.1285 | 0.4775 | N/A | FALSE | FALSE | FALSE
Default | G2FujaraTop-1 | CNC_Flue1 | Sketch5 | ProfileFeature | fipple_gap@Sketch5@G2FujaraTop.Part | 10.1600 | 0.4000 | N/A | FALSE | FALSE | FALSE
Default | G2FujaraTop-1 | CNC_Flue1 | Sketch5 | ProfileFeature | fipple_ramp@Sketch5@G2FujaraTop.Part | 349.0659 | 13.7428 | N/A | FALSE | FALSE | FALSE
Default | G2FujaraTop-1 | CNC_Flue1 | Sketch5 | ProfileFeature | gap_beginning@Sketch5@G2FujaraTop.Part | 53.9750 | 2.1250 | N/A | FALSE | FALSE | FALSE
Default | G2FujaraTop-1 | CNC_Flue1 | Sketch5 | ProfileFeature | flue_dam@Sketch5@G2FujaraTop.Part | 392.6991 | 15.4606 | N/A | FALSE | FALSE | FALSE
Default | G2FujaraTop-1 | CNC_Flue1 | Sketch5 | ProfileFeature | flue_depth@Sketch5@G2FujaraTop.Part | 12.1285 | 0.4775 | N/A | FALSE | FALSE | FALSE
Default | G2FujaraTop-1 | CNC_Flue1 | Sketch3 | ProfileFeature | hole3_diameter@Sketch3@G2FujaraTop.Part | 7.6200 | 0.3000 | N/A | FALSE | FALSE | FALSE
Default | G2FujaraTop-1 | CNC_Flue1 | Sketch3 | ProfileFeature | hole2_diameter@Sketch3@G2FujaraTop.Part | 7.6200 | 0.3000 | N/A | FALSE | FALSE | FALSE
Default | G2FujaraTop-1 | CNC_Flue1 | Sketch3 | ProfileFeature | hole1_diameter@Sketch3@G2FujaraTop.Part | 7.6200 | 0.3000 | N/A | FALSE | FALSE | FALSE
Default | G2FujaraTop-1 | CNC_Flue1 | Sketch3 | ProfileFeature | fipple_to_hole1@Sketch3@G2FujaraTop.Part | 1157.2240 | 45.5600 | N/A | FALSE | FALSE | FALSE
Default | G2FujaraTop-1 | CNC_Flue1 | Sketch3 | ProfileFeature | fipple_to_hole2@Sketch3@G2FujaraTop.Part | 1242.3140 | 48.9100 | N/A | FALSE | FALSE | FALSE
Default | G2FujaraTop-1 | CNC_Flue1 | Sketch3 | ProfileFeature | fipple_to_hole3@Sketch3@G2FujaraTop.Part | 1412.4940 | 55.6100 | N/A | FALSE | FALSE | FALSE
Default | G2FujaraTop-1 | CNC_Flue1 | finger holes | ICE | depth@finger holes@G2FujaraTop.Part | 25.4000 | 1.0000 | N/A | FALSE | FALSE | FALSE
Default | G2FujaraTop-1 | CNC_Flue1 | finger holes | ICE | hole3_diameter@Sketch3@G2FujaraTop.Part | 7.6200 | 0.3000 | N/A | FALSE | FALSE | FALSE
Default | G2FujaraTop-1 | CNC_Flue1 | finger holes | ICE | hole2_diameter@Sketch3@G2FujaraTop.Part | 7.6200 | 0.3000 | N/A | FALSE | FALSE | FALSE
Default | G2FujaraTop-1 | CNC_Flue1 | finger holes | ICE | hole1_diameter@Sketch3@G2FujaraTop.Part | 7.6200 | 0.3000 | N/A | FALSE | FALSE | FALSE
Default | G2FujaraTop-1 | CNC_Flue1 | finger holes | ICE | fipple_to_hole1@Sketch3@G2FujaraTop.Part | 1157.2240 | 45.5600 | N/A | FALSE | FALSE | FALSE
Default | G2FujaraTop-1 | CNC_Flue1 | finger holes | ICE | fipple_to_hole2@Sketch3@G2FujaraTop.Part | 1242.3140 | 48.9100 | N/A | FALSE | FALSE | FALSE
Default | G2FujaraTop-1 | CNC_Flue1 | finger holes | ICE | fipple_to_hole3@Sketch3@G2FujaraTop.Part | 1412.4940 | 55.6100 | N/A | FALSE | FALSE | FALSE
Default | G2FujaraTop-1 | CNC_Flue1 | Sketch3 | ProfileFeature | hole3_diameter@Sketch3@G2FujaraTop.Part | 7.6200 | 0.3000 | N/A | FALSE | FALSE | FALSE
Default | G2FujaraTop-1 | CNC_Flue1 | Sketch3 | ProfileFeature | hole2_diameter@Sketch3@G2FujaraTop.Part | 7.6200 | 0.3000 | N/A | FALSE | FALSE | FALSE
Default | G2FujaraTop-1 | CNC_Flue1 | Sketch3 | ProfileFeature | hole1_diameter@Sketch3@G2FujaraTop.Part | 7.6200 | 0.3000 | N/A | FALSE | FALSE | FALSE
Default | G2FujaraTop-1 | CNC_Flue1 | Sketch3 | ProfileFeature | fipple_to_hole1@Sketch3@G2FujaraTop.Part | 1157.2240 | 45.5600 | N/A | FALSE | FALSE | FALSE
Default | G2FujaraTop-1 | CNC_Flue1 | Sketch3 | ProfileFeature | fipple_to_hole2@Sketch3@G2FujaraTop.Part | 1242.3140 | 48.9100 | N/A | FALSE | FALSE | FALSE
Default | G2FujaraTop-1 | CNC_Flue1 | Sketch3 | ProfileFeature | fipple_to_hole3@Sketch3@G2FujaraTop.Part | 1412.4940 | 55.6100 | N/A | FALSE | FALSE | FALSE
Default | G2FujaraTop-1 | CNC_Flue1 | Sketch9 | ProfileFeature | fipple_height@Sketch9@G2FujaraTop.Part | 0.2540 | 0.0100 | N/A | FALSE | FALSE | FALSE
Default | G2FujaraTop-1 | CNC_Flue1 | Sketch9 | ProfileFeature | fipple_ramp_in@Sketch9@G2FujaraTop.Part | 87.2665 | 3.4357 | N/A | FALSE | FALSE | FALSE
Default | G2FujaraTop-1 | CNC_Flue1 | fipple inside chamfer | ICE | fipple_height@Sketch9@G2FujaraTop.Part | 0.2540 | 0.0100 | N/A | FALSE | FALSE | FALSE
Default | G2FujaraTop-1 | CNC_Flue1 | fipple inside chamfer | ICE | fipple_ramp_in@Sketch9@G2FujaraTop.Part | 87.2665 | 3.4357 | N/A | FALSE | FALSE | FALSE
Default | G2FujaraTop-1 | CNC_Flue1 | Sketch9 | ProfileFeature | fipple_height@Sketch9@G2FujaraTop.Part | 0.2540 | 0.0100 | N/A | FALSE | FALSE | FALSE
Default | G2FujaraTop-1 | CNC_Flue1 | Sketch9 | ProfileFeature | fipple_ramp_in@Sketch9@G2FujaraTop.Part | 87.2665 | 3.4357 | N/A | FALSE | FALSE | FALSE
Default | G2FujaraTop-1 | CNC_Flue1 | Sketch8 | ProfileFeature | flue_depth@Sketch8@G2FujaraTop.Part | 0.8382 | 0.0330 | N/A | FALSE | FALSE | FALSE
Default | G2FujaraTop-1 | CNC_Flue1 | flue | ICE | flue_depth@Sketch8@G2FujaraTop.Part | 0.8382 | 0.0330 | N/A | FALSE | FALSE | FALSE
Default | G2FujaraTop-1 | CNC_Flue1 | Sketch8 | ProfileFeature | flue_depth@Sketch8@G2FujaraTop.Part | 0.8382 | 0.0330 | N/A | FALSE | FALSE | FALSE
Default | G2FujaraTop-1 | CNC_Flue1 | Fillet1 | Fillet | radius@Fillet1@G2FujaraTop.Part | 0.3810 | 0.0150 | N/A | FALSE | FALSE | FALSE
Default | G2FujaraTop-1 | CNC_Flue1 | Sketch10 | ProfileFeature | dowel_pin_diameter@Sketch10@G2FujaraTop.Part | 6.3500 | 0.2500 | N/A | TRUE | FALSE | FALSE
Default | G2FujaraTop-1 | CNC_Flue1 | Sketch10 | ProfileFeature | dowel_pin_location@Sketch10@G2FujaraTop.Part | 15.8750 | 0.6250 | N/A | FALSE | FALSE | FALSE
Default | G2FujaraTop-1 | CNC_Flue1 | dowel pin hole | ICE | depth@dowel pin hole@G2FujaraTop.Part | 15.2400 | 0.6000 | N/A | FALSE | FALSE | FALSE
Default | G2FujaraTop-1 | CNC_Flue1 | dowel pin hole | ICE | dowel_pin_diameter@Sketch10@G2FujaraTop.Part | 6.3500 | 0.2500 | N/A | TRUE | FALSE | FALSE
Default | G2FujaraTop-1 | CNC_Flue1 | dowel pin hole | ICE | dowel_pin_location@Sketch10@G2FujaraTop.Part | 15.8750 | 0.6250 | N/A | FALSE | FALSE | FALSE
Default | G2FujaraTop-1 | CNC_Flue1 | Sketch10 | ProfileFeature | dowel_pin_diameter@Sketch10@G2FujaraTop.Part | 6.3500 | 0.2500 | N/A | TRUE | FALSE | FALSE
Default | G2FujaraTop-1 | CNC_Flue1 | Sketch10 | ProfileFeature | dowel_pin_location@Sketch10@G2FujaraTop.Part | 15.8750 | 0.6250 | N/A | FALSE | FALSE | FALSE
Default | G2FujaraTop-1 | CNC_Flue1 | Chamfer1 | Chamfer | D1@Chamfer1@G2FujaraTop.Part | 16.7386 | 0.6590 | N/A | FALSE | FALSE | FALSE
Default | G2FujaraTop-1 | CNC_Flue1 | Chamfer1 | Chamfer | D2@Chamfer1@G2FujaraTop.Part | 785.3982 | 30.9212 | N/A | FALSE | FALSE | FALSE
Default | G2FujaraTop-1 | CNC_Flue1 | Sketch6 | ProfileFeature | outer_diameter@Sketch6@G2FujaraTop.Part | 47.6250 | 1.8750 | N/A | TRUE | FALSE | FALSE
Default | G2FujaraTop-1 | CNC_Flue1 | outside diameter | ICE | outer_diameter@Sketch6@G2FujaraTop.Part | 47.6250 | 1.8750 | N/A | TRUE | FALSE | FALSE
Default | G2FujaraTop-1 | CNC_Flue1 | Sketch6 | ProfileFeature | outer_diameter@Sketch6@G2FujaraTop.Part | 47.6250 | 1.8750 | N/A | TRUE | FALSE | FALSE
Default | G2FujaraTop-1 | CNC_Flue1 | Sketch11 | ProfileFeature | groove_width@Sketch11@G2FujaraTop.Part | 3.1750 | 0.1250 | N/A | FALSE | FALSE | FALSE
Default | G2FujaraTop-1 | CNC_Flue1 | Sketch11 | ProfileFeature | groove_depth@Sketch11@G2FujaraTop.Part | 6.3500 | 0.2500 | N/A | FALSE | FALSE | FALSE
Default | G2FujaraTop-1 | CNC_Flue1 | Sketch11 | ProfileFeature | groove_location@Sketch11@G2FujaraTop.Part | 47.6250 | 1.8750 | N/A | TRUE | FALSE | FALSE
Default | G2FujaraTop-1 | CNC_Flue1 | Sketch11 | ProfileFeature | finished_length@Sketch11@G2FujaraTop.Part | 1755.7750 | 69.1250 | N/A | TRUE | FALSE | FALSE
Default | G2FujaraTop-1 | CNC_Flue1 | end length locator | RevCut | D1@end length locator@G2FujaraTop.Part | 6283.1853 | 247.3695 | N/A | FALSE | FALSE | FALSE
Default | G2FujaraTop-1 | CNC_Flue1 | end length locator | RevCut | groove_width@Sketch11@G2FujaraTop.Part | 3.1750 | 0.1250 | N/A | FALSE | FALSE | FALSE
Default | G2FujaraTop-1 | CNC_Flue1 | end length locator | RevCut | groove_depth@Sketch11@G2FujaraTop.Part | 6.3500 | 0.2500 | N/A | FALSE | FALSE | FALSE
Default | G2FujaraTop-1 | CNC_Flue1 | end length locator | RevCut | groove_location@Sketch11@G2FujaraTop.Part | 47.6250 | 1.8750 | N/A | TRUE | FALSE | FALSE
Default | G2FujaraTop-1 | CNC_Flue1 | end length locator | RevCut | finished_length@Sketch11@G2FujaraTop.Part | 1755.7750 | 69.1250 | N/A | TRUE | FALSE | FALSE
Default | G2FujaraTop-1 | CNC_Flue1 | Sketch11 | ProfileFeature | groove_width@Sketch11@G2FujaraTop.Part | 3.1750 | 0.1250 | N/A | FALSE | FALSE | FALSE
Default | G2FujaraTop-1 | CNC_Flue1 | Sketch11 | ProfileFeature | groove_depth@Sketch11@G2FujaraTop.Part | 6.3500 | 0.2500 | N/A | FALSE | FALSE | FALSE
Default | G2FujaraTop-1 | CNC_Flue1 | Sketch11 | ProfileFeature | groove_location@Sketch11@G2FujaraTop.Part | 47.6250 | 1.8750 | N/A | TRUE | FALSE | FALSE
Default | G2FujaraTop-1 | CNC_Flue1 | Sketch11 | ProfileFeature | finished_length@Sketch11@G2FujaraTop.Part | 1755.7750 | 69.1250 | N/A | TRUE | FALSE | FALSE
Default | G2FujaraTop-1 | CNC_Flue1 | chamfer at foot | Chamfer | length@chamfer at foot@G2FujaraTop.Part | 1.9050 | 0.0750 | N/A | FALSE | FALSE | FALSE
Default | G2FujaraTop-1 | CNC_Flue1 | chamfer at foot | Chamfer | angle@chamfer at foot@G2FujaraTop.Part | 785.3982 | 30.9212 | N/A | FALSE | FALSE | FALSE
Default | G2FujaraTop-1 | CNC_Flue1 | [Equation 0] | Equation |  |  |  |  |  |  | TRUE | "g_body_OD"= 47.625mm
Default | G2FujaraTop-1 | CNC_Flue1 | [Equation 1] | Equation |  |  |  |  |  |  | TRUE | "g_body_ID"= 31.75mm
Default | G2FujaraTop-1 | CNC_Flue1 | [Equation 2] | Equation |  |  |  |  |  |  | TRUE | "g_body_L_finished"= 1755.775mm
Default | G2FujaraTop-1 | CNC_Flue1 | [Equation 3] | Equation |  |  |  |  |  |  | TRUE | "g_body_L_blank"= 1803.4mm
Default | G2FujaraTop-1 | CNC_Flue1 | [Equation 4] | Equation |  |  |  |  |  |  | TRUE | "g_body_blank_W"= 57.15mm
Default | G2FujaraTop-1 | CNC_Flue1 | [Equation 5] | Equation |  |  |  |  |  |  | TRUE | "g_dowel_OD"= 6.35mm
Default | G2FujaraTop-1 | CNC_Flue1 | [Equation 6] | Equation |  |  |  |  |  |  | TRUE | "g_thru_passage_OD"= 12.7mm
Default | G2FujaraTop-1 | CNC_Flue1 | [Equation 7] | Equation |  |  |  |  |  |  | TRUE | "g_glue_glap"= 0.0762mm
Default | G2FujaraTop-1 | CNC_Flue1 | [Equation 8] | Equation |  |  |  |  |  |  | TRUE | "c_dowel_clearance"= 0mm
Default | G2FujaraTop-1 | CNC_Flue1 | [Equation 9] | Equation |  |  |  |  |  |  | FALSE | "thickness@wood block"= "g_body_blank_W" / 2
Default | G2FujaraTop-1 | CNC_Flue1 | [Equation 10] | Equation |  |  |  |  |  |  | FALSE | "blank_length@Sketch1"= "g_body_L_blank"
Default | G2FujaraTop-1 | CNC_Flue1 | [Equation 11] | Equation |  |  |  |  |  |  | FALSE | "blank_width@Sketch1"= "g_body_blank_W"
Default | G2FujaraTop-1 | CNC_Flue1 | [Equation 12] | Equation |  |  |  |  |  |  | FALSE | "bore_inner_radius@Sketch2"= "g_body_ID" / 2
Default | G2FujaraTop-1 | CNC_Flue1 | [Equation 13] | Equation |  |  |  |  |  |  | FALSE | "outer_diameter@Sketch6"= "g_body_OD"
Default | G2FujaraTop-1 | CNC_Flue1 | [Equation 14] | Equation |  |  |  |  |  |  | FALSE | "finished_length@Sketch11"= "g_body_L_finished"
Default | G2FujaraTop-1 | CNC_Flue1 | [Equation 15] | Equation |  |  |  |  |  |  | FALSE | "dowel_pin_diameter@Sketch10"= "g_dowel_OD" + "c_dowel_clearance"
Default | G2Fujara_MouthpieceTop-2 | Default | Sketch1 | ProfileFeature | blank_length@Sketch1@G2Fujara_MouthpieceTop.Part | 735.5840 | 28.9600 | N/A | TRUE | FALSE | FALSE
Default | G2Fujara_MouthpieceTop-2 | Default | Sketch1 | ProfileFeature | blank_width@Sketch1@G2Fujara_MouthpieceTop.Part | 38.1000 | 1.5000 | N/A | TRUE | FALSE | FALSE
Default | G2Fujara_MouthpieceTop-2 | Default | wood block | Extrusion | thickness@wood block@G2Fujara_MouthpieceTop.Part | 19.0500 | 0.7500 | N/A | TRUE | FALSE | FALSE
Default | G2Fujara_MouthpieceTop-2 | Default | wood block | Extrusion | blank_length@Sketch1@G2Fujara_MouthpieceTop.Part | 735.5840 | 28.9600 | N/A | TRUE | FALSE | FALSE
Default | G2Fujara_MouthpieceTop-2 | Default | wood block | Extrusion | blank_width@Sketch1@G2Fujara_MouthpieceTop.Part | 38.1000 | 1.5000 | N/A | TRUE | FALSE | FALSE
Default | G2Fujara_MouthpieceTop-2 | Default | Sketch1 | ProfileFeature | blank_length@Sketch1@G2Fujara_MouthpieceTop.Part | 735.5840 | 28.9600 | N/A | TRUE | FALSE | FALSE
Default | G2Fujara_MouthpieceTop-2 | Default | Sketch1 | ProfileFeature | blank_width@Sketch1@G2Fujara_MouthpieceTop.Part | 38.1000 | 1.5000 | N/A | TRUE | FALSE | FALSE
Default | G2Fujara_MouthpieceTop-2 | Default | Sketch2 | ProfileFeature | inner_diameter@Sketch2@G2Fujara_MouthpieceTop.Part | 15.9512 | 0.6280 | N/A | TRUE | FALSE | FALSE
Default | G2Fujara_MouthpieceTop-2 | Default | inner bore | ICE | inner_diameter@Sketch2@G2Fujara_MouthpieceTop.Part | 15.9512 | 0.6280 | N/A | TRUE | FALSE | FALSE
Default | G2Fujara_MouthpieceTop-2 | Default | Sketch2 | ProfileFeature | inner_diameter@Sketch2@G2Fujara_MouthpieceTop.Part | 15.9512 | 0.6280 | N/A | TRUE | FALSE | FALSE
Default | G2Fujara_MouthpieceTop-2 | Default | Sketch3 | ProfileFeature | mouthpiece_diameter@Sketch3@G2Fujara_MouthpieceTop.Part | 12.7762 | 0.5030 | N/A | TRUE | FALSE | FALSE
Default | G2Fujara_MouthpieceTop-2 | Default | Sketch3 | ProfileFeature | mouthpiece_location@Sketch3@G2Fujara_MouthpieceTop.Part | 22.2250 | 0.8750 | N/A | FALSE | FALSE | FALSE
Default | G2Fujara_MouthpieceTop-2 | Default | mouthpiece through hole | ICE | mouthpiece_diameter@Sketch3@G2Fujara_MouthpieceTop.Part | 12.7762 | 0.5030 | N/A | TRUE | FALSE | FALSE
Default | G2Fujara_MouthpieceTop-2 | Default | mouthpiece through hole | ICE | mouthpiece_location@Sketch3@G2Fujara_MouthpieceTop.Part | 22.2250 | 0.8750 | N/A | FALSE | FALSE | FALSE
Default | G2Fujara_MouthpieceTop-2 | Default | Sketch3 | ProfileFeature | mouthpiece_diameter@Sketch3@G2Fujara_MouthpieceTop.Part | 12.7762 | 0.5030 | N/A | TRUE | FALSE | FALSE
Default | G2Fujara_MouthpieceTop-2 | Default | Sketch3 | ProfileFeature | mouthpiece_location@Sketch3@G2Fujara_MouthpieceTop.Part | 22.2250 | 0.8750 | N/A | FALSE | FALSE | FALSE
Default | G2Fujara_MouthpieceTop-2 | Default | Sketch5 | ProfileFeature | counterbore_diameter@Sketch5@G2Fujara_MouthpieceTop.Part | 16.2560 | 0.6400 | N/A | TRUE | FALSE | FALSE
Default | G2Fujara_MouthpieceTop-2 | Default | counterbore | ICE | depth@counterbore@G2Fujara_MouthpieceTop.Part | 5.5499 | 0.2185 | N/A | FALSE | FALSE | FALSE
Default | G2Fujara_MouthpieceTop-2 | Default | counterbore | ICE | counterbore_diameter@Sketch5@G2Fujara_MouthpieceTop.Part | 16.2560 | 0.6400 | N/A | TRUE | FALSE | FALSE
Default | G2Fujara_MouthpieceTop-2 | Default | Sketch5 | ProfileFeature | counterbore_diameter@Sketch5@G2Fujara_MouthpieceTop.Part | 16.2560 | 0.6400 | N/A | TRUE | FALSE | FALSE
Default | G2Fujara_MouthpieceTop-2 | Default | Sketch4 | ProfileFeature | outer_diameter@Sketch4@G2Fujara_MouthpieceTop.Part | 28.5750 | 1.1250 | N/A | TRUE | FALSE | FALSE
Default | G2Fujara_MouthpieceTop-2 | Default | outer diameter | ICE | outer_diameter@Sketch4@G2Fujara_MouthpieceTop.Part | 28.5750 | 1.1250 | N/A | TRUE | FALSE | FALSE
Default | G2Fujara_MouthpieceTop-2 | Default | Sketch4 | ProfileFeature | outer_diameter@Sketch4@G2Fujara_MouthpieceTop.Part | 28.5750 | 1.1250 | N/A | TRUE | FALSE | FALSE
Default | G2Fujara_MouthpieceTop-2 | Default | [Equation 0] | Equation |  |  |  |  |  |  | TRUE | "g_mp_block_OD"= 28.575mm
Default | G2Fujara_MouthpieceTop-2 | Default | [Equation 1] | Equation |  |  |  |  |  |  | TRUE | "g_mp_block_ID"= 15.875mm
Default | G2Fujara_MouthpieceTop-2 | Default | [Equation 2] | Equation |  |  |  |  |  |  | TRUE | "g_mp_block_L_blank"= 735.584mm
Default | G2Fujara_MouthpieceTop-2 | Default | [Equation 3] | Equation |  |  |  |  |  |  | TRUE | "g_mp_block_blank_W"= 38.1mm
Default | G2Fujara_MouthpieceTop-2 | Default | [Equation 4] | Equation |  |  |  |  |  |  | TRUE | "g_mp_tube_OD"= 15.875mm
Default | G2Fujara_MouthpieceTop-2 | Default | [Equation 5] | Equation |  |  |  |  |  |  | TRUE | "g_thru_passage_OD"= 12.7mm
Default | G2Fujara_MouthpieceTop-2 | Default | [Equation 6] | Equation |  |  |  |  |  |  | TRUE | "c_glue_gap"= 0.0762mm
Default | G2Fujara_MouthpieceTop-2 | Default | [Equation 7] | Equation |  |  |  |  |  |  | TRUE | "c_slip_fit"= 0.381mm
Default | G2Fujara_MouthpieceTop-2 | Default | [Equation 8] | Equation |  |  |  |  |  |  | FALSE | "thickness@wood block"= "g_mp_block_blank_W" / 2
Default | G2Fujara_MouthpieceTop-2 | Default | [Equation 9] | Equation |  |  |  |  |  |  | FALSE | "blank_length@Sketch1"= "g_mp_block_L_blank"
Default | G2Fujara_MouthpieceTop-2 | Default | [Equation 10] | Equation |  |  |  |  |  |  | FALSE | "blank_width@Sketch1"= "g_mp_block_blank_W"
Default | G2Fujara_MouthpieceTop-2 | Default | [Equation 11] | Equation |  |  |  |  |  |  | FALSE | "outer_diameter@Sketch4"= "g_mp_block_OD"
Default | G2Fujara_MouthpieceTop-2 | Default | [Equation 12] | Equation |  |  |  |  |  |  | FALSE | "inner_diameter@Sketch2"= "g_mp_block_ID" + "c_glue_gap"
Default | G2Fujara_MouthpieceTop-2 | Default | [Equation 13] | Equation |  |  |  |  |  |  | FALSE | "mouthpiece_diameter@Sketch3"= "g_thru_passage_OD" + "c_glue_gap"
Default | G2Fujara_MouthpieceTop-2 | Default | [Equation 14] | Equation |  |  |  |  |  |  | FALSE | "counterbore_diameter@Sketch5"= "g_mp_tube_OD" + "c_slip_fit"
Default | mouthpiece-3 | Default | Sketch2 | ProfileFeature | mouthpiece_outer_diameter@Sketch2@mouthpiece.Part | 15.8750 | 0.6250 | N/A | FALSE | FALSE | FALSE
Default | mouthpiece-3 | Default | Sketch2 | ProfileFeature | mouthpiece_inner_diameter@Sketch2@mouthpiece.Part | 9.5250 | 0.3750 | N/A | FALSE | FALSE | FALSE
Default | mouthpiece-3 | Default | tube | Extrusion | height@tube@mouthpiece.Part | 50.8000 | 2.0000 | N/A | FALSE | FALSE | FALSE
Default | mouthpiece-3 | Default | tube | Extrusion | mouthpiece_outer_diameter@Sketch2@mouthpiece.Part | 15.8750 | 0.6250 | N/A | FALSE | FALSE | FALSE
Default | mouthpiece-3 | Default | tube | Extrusion | mouthpiece_inner_diameter@Sketch2@mouthpiece.Part | 9.5250 | 0.3750 | N/A | FALSE | FALSE | FALSE
Default | mouthpiece-3 | Default | Sketch2 | ProfileFeature | mouthpiece_outer_diameter@Sketch2@mouthpiece.Part | 15.8750 | 0.6250 | N/A | FALSE | FALSE | FALSE
Default | mouthpiece-3 | Default | Sketch2 | ProfileFeature | mouthpiece_inner_diameter@Sketch2@mouthpiece.Part | 9.5250 | 0.3750 | N/A | FALSE | FALSE | FALSE
Default | mouthpiece-3 | Default | Chamfer1 | Chamfer | size@Chamfer1@mouthpiece.Part | 1.2700 | 0.0500 | N/A | FALSE | FALSE | FALSE
Default | mouthpiece-3 | Default | Chamfer1 | Chamfer | angle@Chamfer1@mouthpiece.Part | 785.3982 | 30.9212 | N/A | FALSE | FALSE | FALSE
Default | mouthpiece-3 | Default | Sketch3 | ProfileFeature | mouthpiece_curved_cut@Sketch3@mouthpiece.Part | 21.4548 | 0.8447 | N/A | FALSE | FALSE | FALSE
Default | mouthpiece-3 | Default | curved_cut | ICE | mouthpiece_curved_cut@Sketch3@mouthpiece.Part | 21.4548 | 0.8447 | N/A | FALSE | FALSE | FALSE
Default | mouthpiece-3 | Default | Sketch3 | ProfileFeature | mouthpiece_curved_cut@Sketch3@mouthpiece.Part | 21.4548 | 0.8447 | N/A | FALSE | FALSE | FALSE
Default | G2FujaraFluePlug-1 | CNC_Flue1 | Sketch1 | ProfileFeature | flue_plug_width@Sketch1@G2FujaraFluePlug.Part | 12.6238 | 0.4970 | N/A | FALSE | FALSE | FALSE
Default | G2FujaraFluePlug-1 | CNC_Flue1 | Sketch1 | ProfileFeature | flue_plug_length@Sketch1@G2FujaraFluePlug.Part | 53.9750 | 2.1250 | N/A | FALSE | FALSE | FALSE
Default | G2FujaraFluePlug-1 | CNC_Flue1 | blank | Extrusion | thickness@blank@G2FujaraFluePlug.Part | 5.0800 | 0.2000 | N/A | FALSE | FALSE | FALSE
Default | G2FujaraFluePlug-1 | CNC_Flue1 | blank | Extrusion | flue_plug_width@Sketch1@G2FujaraFluePlug.Part | 12.6238 | 0.4970 | N/A | FALSE | FALSE | FALSE
Default | G2FujaraFluePlug-1 | CNC_Flue1 | blank | Extrusion | flue_plug_length@Sketch1@G2FujaraFluePlug.Part | 53.9750 | 2.1250 | N/A | FALSE | FALSE | FALSE
Default | G2FujaraFluePlug-1 | CNC_Flue1 | Sketch1 | ProfileFeature | flue_plug_width@Sketch1@G2FujaraFluePlug.Part | 12.6238 | 0.4970 | N/A | FALSE | FALSE | FALSE
Default | G2FujaraFluePlug-1 | CNC_Flue1 | Sketch1 | ProfileFeature | flue_plug_length@Sketch1@G2FujaraFluePlug.Part | 53.9750 | 2.1250 | N/A | FALSE | FALSE | FALSE
Default | G2FujaraFluePlug-1 | CNC_Flue1 | Sketch2 | ProfileFeature | slot_radius@Sketch2@G2FujaraFluePlug.Part | 5.0800 | 0.2000 | N/A | FALSE | FALSE | FALSE
Default | G2FujaraFluePlug-1 | CNC_Flue1 | Sketch2 | ProfileFeature | slot_location@Sketch2@G2FujaraFluePlug.Part | 22.2250 | 0.8750 | N/A | FALSE | FALSE | FALSE
Default | G2FujaraFluePlug-1 | CNC_Flue1 | slot | ICE | flue_height@slot@G2FujaraFluePlug.Part | 1.0160 | 0.0400 | N/A | FALSE | FALSE | FALSE
Default | G2FujaraFluePlug-1 | CNC_Flue1 | slot | ICE | slot_radius@Sketch2@G2FujaraFluePlug.Part | 5.0800 | 0.2000 | N/A | FALSE | FALSE | FALSE
Default | G2FujaraFluePlug-1 | CNC_Flue1 | slot | ICE | slot_location@Sketch2@G2FujaraFluePlug.Part | 22.2250 | 0.8750 | N/A | FALSE | FALSE | FALSE
Default | G2FujaraFluePlug-1 | CNC_Flue1 | Sketch2 | ProfileFeature | slot_radius@Sketch2@G2FujaraFluePlug.Part | 5.0800 | 0.2000 | N/A | FALSE | FALSE | FALSE
Default | G2FujaraFluePlug-1 | CNC_Flue1 | Sketch2 | ProfileFeature | slot_location@Sketch2@G2FujaraFluePlug.Part | 22.2250 | 0.8750 | N/A | FALSE | FALSE | FALSE
Default | G2FujaraFluePlug-1 | CNC_Flue1 | Sketch3 | ProfileFeature | airway_passage@Sketch3@G2FujaraFluePlug.Part | 9.5250 | 0.3750 | N/A | FALSE | FALSE | FALSE
Default | G2FujaraFluePlug-1 | CNC_Flue1 | Sketch3 | ProfileFeature | D1@Sketch3@G2FujaraFluePlug.Part | 22.2250 | 0.8750 | N/A | TRUE | FALSE | FALSE
Default | G2FujaraFluePlug-1 | CNC_Flue1 | through_hole | ICE | airway_passage@Sketch3@G2FujaraFluePlug.Part | 9.5250 | 0.3750 | N/A | FALSE | FALSE | FALSE
Default | G2FujaraFluePlug-1 | CNC_Flue1 | through_hole | ICE | D1@Sketch3@G2FujaraFluePlug.Part | 22.2250 | 0.8750 | N/A | TRUE | FALSE | FALSE
Default | G2FujaraFluePlug-1 | CNC_Flue1 | Sketch3 | ProfileFeature | airway_passage@Sketch3@G2FujaraFluePlug.Part | 9.5250 | 0.3750 | N/A | FALSE | FALSE | FALSE
Default | G2FujaraFluePlug-1 | CNC_Flue1 | Sketch3 | ProfileFeature | D1@Sketch3@G2FujaraFluePlug.Part | 22.2250 | 0.8750 | N/A | TRUE | FALSE | FALSE
Default | G2FujaraFluePlug-1 | CNC_Flue1 | Fillet1 | Fillet | radius@Fillet1@G2FujaraFluePlug.Part | 0.3810 | 0.0150 | N/A | FALSE | FALSE | FALSE
Default | G2FujaraFluePlug-1 | CNC_Flue1 | Move Face1 | MoveFace | D1@Move Face1@G2FujaraFluePlug.Part | 11.9888 | 0.4720 | N/A | FALSE | FALSE | FALSE
Default | G2FujaraFluePlug-1 | CNC_Flue1 | Plane1 | RefPlane | D1@Plane1@G2FujaraFluePlug.Part | 27.9400 | 1.1000 | N/A | FALSE | FALSE | FALSE
Default | G2FujaraFluePlug-1 | CNC_Flue1 | Sketch9 | ProfileFeature | D1@Plane1@G2FujaraFluePlug.Part | 27.9400 | 1.1000 | N/A | FALSE | FALSE | FALSE
Default | G2FujaraFluePlug-1 | CNC_Flue1 | Sketch9 | ProfileFeature | D1@Sketch9@G2FujaraFluePlug.Part | 0.2540 | 0.0100 | N/A | FALSE | FALSE | FALSE
Default | G2FujaraFluePlug-1 | CNC_Flue1 | Cut-Sweep1 | SweepCut | D1@Plane1@G2FujaraFluePlug.Part | 27.9400 | 1.1000 | N/A | FALSE | FALSE | FALSE
Default | G2FujaraFluePlug-1 | CNC_Flue1 | Cut-Sweep1 | SweepCut | D1@Sketch9@G2FujaraFluePlug.Part | 0.2540 | 0.0100 | N/A | FALSE | FALSE | FALSE
Default | G2FujaraFluePlug-1 | CNC_Flue1 | Sketch9 | ProfileFeature | D1@Plane1@G2FujaraFluePlug.Part | 27.9400 | 1.1000 | N/A | FALSE | FALSE | FALSE
Default | G2FujaraFluePlug-1 | CNC_Flue1 | Sketch9 | ProfileFeature | D1@Sketch9@G2FujaraFluePlug.Part | 0.2540 | 0.0100 | N/A | FALSE | FALSE | FALSE
Default | G2FujaraFluePlug-1 | CNC_Flue1 | Fillet2 | Fillet | D1@Fillet2@G2FujaraFluePlug.Part | 0.2540 | 0.0100 | N/A | FALSE | FALSE | FALSE
Default | G2Fujara_MouthpieceBottom-1 | Default | Sketch1 | ProfileFeature | blank_length@Sketch1@G2Fujara_MouthpieceBottom.Part | 735.5840 | 28.9600 | N/A | TRUE | FALSE | FALSE
Default | G2Fujara_MouthpieceBottom-1 | Default | Sketch1 | ProfileFeature | blank_width@Sketch1@G2Fujara_MouthpieceBottom.Part | 38.1000 | 1.5000 | N/A | TRUE | FALSE | FALSE
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

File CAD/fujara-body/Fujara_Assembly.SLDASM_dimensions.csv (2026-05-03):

Component | ConfigName | FeatureName | FeatureType | DimFullName | Value_mm | Value_in | Tolerance_Type | IsDriven | IsLinked | IsGlobalVar | EquationOrComment
7815K833_High-Strength 932 Bronze Flanged Sleeve Bearing-1 | 7815K833 | Sketch1 | ProfileFeature | Flange OD@Sketch1@7815K833_High-Strength 932 Bronze Flanged Sleeve Bearing.Part | 42.8625 | 1.6875 | N/A | FALSE | FALSE | FALSE
7815K833_High-Strength 932 Bronze Flanged Sleeve Bearing-1 | 7815K833 | Sketch1 | ProfileFeature | ID@Sketch1@7815K833_High-Strength 932 Bronze Flanged Sleeve Bearing.Part | 31.7500 | 1.2500 | N/A | FALSE | FALSE | FALSE
7815K833_High-Strength 932 Bronze Flanged Sleeve Bearing-1 | 7815K833 | Sketch1 | ProfileFeature | OD@Sketch1@7815K833_High-Strength 932 Bronze Flanged Sleeve Bearing.Part | 38.1508 | 1.5020 | N/A | FALSE | FALSE | FALSE
7815K833_High-Strength 932 Bronze Flanged Sleeve Bearing-1 | 7815K833 | Sketch2 | ProfileFeature | Flange Thickness@Sketch2@7815K833_High-Strength 932 Bronze Flanged Sleeve Bearing.Part | 3.1750 | 0.1250 | N/A | FALSE | FALSE | FALSE
7815K833_High-Strength 932 Bronze Flanged Sleeve Bearing-1 | 7815K833 | Sketch2 | ProfileFeature | Length@Sketch2@7815K833_High-Strength 932 Bronze Flanged Sleeve Bearing.Part | 12.7000 | 0.5000 | N/A | FALSE | FALSE | FALSE
7815K833_High-Strength 932 Bronze Flanged Sleeve Bearing-1 | 7815K833 | Revolve1 | Revolution | D1@Revolve1@7815K833_High-Strength 932 Bronze Flanged Sleeve Bearing.Part | 6283.1853 | 247.3695 | N/A | FALSE | FALSE | FALSE
7815K833_High-Strength 932 Bronze Flanged Sleeve Bearing-1 | 7815K833 | Fillet1 | Fillet | D1@Fillet1@7815K833_High-Strength 932 Bronze Flanged Sleeve Bearing.Part | 0.2134 | 0.0084 | N/A | TRUE | FALSE | FALSE
7815K833_High-Strength 932 Bronze Flanged Sleeve Bearing-1 | 7815K833 | Fillet2 | Fillet | D1@Fillet2@7815K833_High-Strength 932 Bronze Flanged Sleeve Bearing.Part | 0.2134 | 0.0084 | N/A | TRUE | FALSE | FALSE
7815K833_High-Strength 932 Bronze Flanged Sleeve Bearing-1 | 7815K833 | [Equation 0] | Equation |  |  |  |  |  |  | FALSE | "D1@Fillet1"=("OD@Sketch1"-"ID@Sketch1")/30
7815K833_High-Strength 932 Bronze Flanged Sleeve Bearing-1 | 7815K833 | [Equation 1] | Equation |  |  |  |  |  |  | FALSE | "D1@Fillet2"=("OD@Sketch1"-"ID@Sketch1")/30
toptube-3 | Default | Sketch2 | ProfileFeature | tube_od@Sketch2@toptube.Part | 15.8750 | 0.6250 | N/A | FALSE | FALSE | FALSE
toptube-3 | Default | Sketch2 | ProfileFeature | tube_id@Sketch2@toptube.Part | 9.5250 | 0.3750 | N/A | FALSE | FALSE | FALSE
toptube-3 | Default | tube | Extrusion | height@tube@toptube.Part | 15.8750 | 0.6250 | N/A | FALSE | FALSE | FALSE
toptube-3 | Default | tube | Extrusion | tube_od@Sketch2@toptube.Part | 15.8750 | 0.6250 | N/A | FALSE | FALSE | FALSE
toptube-3 | Default | tube | Extrusion | tube_id@Sketch2@toptube.Part | 9.5250 | 0.3750 | N/A | FALSE | FALSE | FALSE
toptube-3 | Default | Sketch2 | ProfileFeature | tube_od@Sketch2@toptube.Part | 15.8750 | 0.6250 | N/A | FALSE | FALSE | FALSE
toptube-3 | Default | Sketch2 | ProfileFeature | tube_id@Sketch2@toptube.Part | 9.5250 | 0.3750 | N/A | FALSE | FALSE | FALSE
toptube-3 | Default | Chamfer1 | Chamfer | size@Chamfer1@toptube.Part | 1.2700 | 0.0500 | N/A | FALSE | FALSE | FALSE
toptube-3 | Default | Chamfer1 | Chamfer | angle@Chamfer1@toptube.Part | 785.3982 | 30.9212 | N/A | FALSE | FALSE | FALSE
FujaraBottomG2-1 | Default | Sketch1 | ProfileFeature | blank_length@Sketch1@FujaraBottomG2.Part | 1803.4000 | 71.0000 | N/A | TRUE | FALSE | FALSE
FujaraBottomG2-1 | Default | Sketch1 | ProfileFeature | blank_width@Sketch1@FujaraBottomG2.Part | 57.1500 | 2.2500 | N/A | TRUE | FALSE | FALSE
FujaraBottomG2-1 | Default | wood block | Extrusion | thickness@wood block@FujaraBottomG2.Part | 28.5750 | 1.1250 | N/A | TRUE | FALSE | FALSE
FujaraBottomG2-1 | Default | wood block | Extrusion | blank_length@Sketch1@FujaraBottomG2.Part | 1803.4000 | 71.0000 | N/A | TRUE | FALSE | FALSE
FujaraBottomG2-1 | Default | wood block | Extrusion | blank_width@Sketch1@FujaraBottomG2.Part | 57.1500 | 2.2500 | N/A | TRUE | FALSE | FALSE
FujaraBottomG2-1 | Default | Sketch1 | ProfileFeature | blank_length@Sketch1@FujaraBottomG2.Part | 1803.4000 | 71.0000 | N/A | TRUE | FALSE | FALSE
FujaraBottomG2-1 | Default | Sketch1 | ProfileFeature | blank_width@Sketch1@FujaraBottomG2.Part | 57.1500 | 2.2500 | N/A | TRUE | FALSE | FALSE
FujaraBottomG2-1 | Default | Sketch2 | ProfileFeature | inner_bore_radius@Sketch2@FujaraBottomG2.Part | 15.8750 | 0.6250 | N/A | TRUE | FALSE | FALSE
FujaraBottomG2-1 | Default | Sketch2 | ProfileFeature | finished_length@Sketch2@FujaraBottomG2.Part | 1755.7750 | 69.1250 | N/A | FALSE | FALSE | FALSE
FujaraBottomG2-1 | Default | inner bore | RevCut | D1@inner bore@FujaraBottomG2.Part | 6283.1853 | 247.3695 | N/A | FALSE | FALSE | FALSE
FujaraBottomG2-1 | Default | inner bore | RevCut | inner_bore_radius@Sketch2@FujaraBottomG2.Part | 15.8750 | 0.6250 | N/A | TRUE | FALSE | FALSE
FujaraBottomG2-1 | Default | inner bore | RevCut | finished_length@Sketch2@FujaraBottomG2.Part | 1755.7750 | 69.1250 | N/A | FALSE | FALSE | FALSE
FujaraBottomG2-1 | Default | Sketch2 | ProfileFeature | inner_bore_radius@Sketch2@FujaraBottomG2.Part | 15.8750 | 0.6250 | N/A | TRUE | FALSE | FALSE
FujaraBottomG2-1 | Default | Sketch2 | ProfileFeature | finished_length@Sketch2@FujaraBottomG2.Part | 1755.7750 | 69.1250 | N/A | FALSE | FALSE | FALSE
FujaraBottomG2-1 | Default | Sketch9 | ProfileFeature | flange_foot_recess@Sketch9@FujaraBottomG2.Part | 10.5410 | 0.4150 | N/A | FALSE | FALSE | FALSE
FujaraBottomG2-1 | Default | Sketch9 | ProfileFeature | finished_length@Sketch9@FujaraBottomG2.Part | 1755.7750 | 69.1250 | N/A | FALSE | FALSE | FALSE
FujaraBottomG2-1 | Default | Sketch9 | ProfileFeature | flange_counterbore_radius@Sketch9@FujaraBottomG2.Part | 19.5580 | 0.7700 | N/A | FALSE | FALSE | FALSE
FujaraBottomG2-1 | Default | flanged foot relief | RevCut | D1@flanged foot relief@FujaraBottomG2.Part | 6283.1853 | 247.3695 | N/A | FALSE | FALSE | FALSE
FujaraBottomG2-1 | Default | flanged foot relief | RevCut | flange_foot_recess@Sketch9@FujaraBottomG2.Part | 10.5410 | 0.4150 | N/A | FALSE | FALSE | FALSE
FujaraBottomG2-1 | Default | flanged foot relief | RevCut | finished_length@Sketch9@FujaraBottomG2.Part | 1755.7750 | 69.1250 | N/A | FALSE | FALSE | FALSE
FujaraBottomG2-1 | Default | flanged foot relief | RevCut | flange_counterbore_radius@Sketch9@FujaraBottomG2.Part | 19.5580 | 0.7700 | N/A | FALSE | FALSE | FALSE
FujaraBottomG2-1 | Default | Sketch9 | ProfileFeature | flange_foot_recess@Sketch9@FujaraBottomG2.Part | 10.5410 | 0.4150 | N/A | FALSE | FALSE | FALSE
FujaraBottomG2-1 | Default | Sketch9 | ProfileFeature | finished_length@Sketch9@FujaraBottomG2.Part | 1755.7750 | 69.1250 | N/A | FALSE | FALSE | FALSE
FujaraBottomG2-1 | Default | Sketch9 | ProfileFeature | flange_counterbore_radius@Sketch9@FujaraBottomG2.Part | 19.5580 | 0.7700 | N/A | FALSE | FALSE | FALSE
FujaraBottomG2-1 | Default | Sketch5 | ProfileFeature | mouthpiece_hole@Sketch5@FujaraBottomG2.Part | 12.7762 | 0.5030 | N/A | TRUE | FALSE | FALSE
FujaraBottomG2-1 | Default | Sketch5 | ProfileFeature | mouthpiece_location@Sketch5@FujaraBottomG2.Part | 22.2250 | 0.8750 | N/A | FALSE | FALSE | FALSE
FujaraBottomG2-1 | Default | mouthpiece hole | ICE | D1@mouthpiece hole@FujaraBottomG2.Part | 21.5900 | 0.8500 | N/A | FALSE | FALSE | FALSE
FujaraBottomG2-1 | Default | mouthpiece hole | ICE | mouthpiece_hole@Sketch5@FujaraBottomG2.Part | 12.7762 | 0.5030 | N/A | TRUE | FALSE | FALSE
FujaraBottomG2-1 | Default | mouthpiece hole | ICE | mouthpiece_location@Sketch5@FujaraBottomG2.Part | 22.2250 | 0.8750 | N/A | FALSE | FALSE | FALSE
FujaraBottomG2-1 | Default | Sketch5 | ProfileFeature | mouthpiece_hole@Sketch5@FujaraBottomG2.Part | 12.7762 | 0.5030 | N/A | TRUE | FALSE | FALSE
FujaraBottomG2-1 | Default | Sketch5 | ProfileFeature | mouthpiece_location@Sketch5@FujaraBottomG2.Part | 22.2250 | 0.8750 | N/A | FALSE | FALSE | FALSE
FujaraBottomG2-1 | Default | Sketch6 | ProfileFeature | dowel_pin_diameter@Sketch6@FujaraBottomG2.Part | 6.3500 | 0.2500 | N/A | TRUE | FALSE | FALSE
FujaraBottomG2-1 | Default | Sketch6 | ProfileFeature | dowel_pin_location@Sketch6@FujaraBottomG2.Part | 15.8750 | 0.6250 | N/A | FALSE | FALSE | FALSE
FujaraBottomG2-1 | Default | dowel pin hole | ICE | depth@dowel pin hole@FujaraBottomG2.Part | 15.2400 | 0.6000 | N/A | FALSE | FALSE | FALSE
FujaraBottomG2-1 | Default | dowel pin hole | ICE | dowel_pin_diameter@Sketch6@FujaraBottomG2.Part | 6.3500 | 0.2500 | N/A | TRUE | FALSE | FALSE
FujaraBottomG2-1 | Default | dowel pin hole | ICE | dowel_pin_location@Sketch6@FujaraBottomG2.Part | 15.8750 | 0.6250 | N/A | FALSE | FALSE | FALSE
FujaraBottomG2-1 | Default | Sketch6 | ProfileFeature | dowel_pin_diameter@Sketch6@FujaraBottomG2.Part | 6.3500 | 0.2500 | N/A | TRUE | FALSE | FALSE
FujaraBottomG2-1 | Default | Sketch6 | ProfileFeature | dowel_pin_location@Sketch6@FujaraBottomG2.Part | 15.8750 | 0.6250 | N/A | FALSE | FALSE | FALSE
FujaraBottomG2-1 | Default | Sketch8 | ProfileFeature | tube_diameter@Sketch8@FujaraBottomG2.Part | 16.2560 | 0.6400 | N/A | TRUE | FALSE | FALSE
FujaraBottomG2-1 | Default | Sketch8 | ProfileFeature | bracket_length@Sketch8@FujaraBottomG2.Part | 691.1340 | 27.2100 | N/A | FALSE | FALSE | FALSE
FujaraBottomG2-1 | Default | mounting holes | ICE | counter_bore_depth@mounting holes@FujaraBottomG2.Part | 10.3124 | 0.4060 | N/A | FALSE | FALSE | FALSE
FujaraBottomG2-1 | Default | mounting holes | ICE | tube_diameter@Sketch8@FujaraBottomG2.Part | 16.2560 | 0.6400 | N/A | TRUE | FALSE | FALSE
FujaraBottomG2-1 | Default | mounting holes | ICE | bracket_length@Sketch8@FujaraBottomG2.Part | 691.1340 | 27.2100 | N/A | FALSE | FALSE | FALSE
FujaraBottomG2-1 | Default | Sketch8 | ProfileFeature | tube_diameter@Sketch8@FujaraBottomG2.Part | 16.2560 | 0.6400 | N/A | TRUE | FALSE | FALSE
FujaraBottomG2-1 | Default | Sketch8 | ProfileFeature | bracket_length@Sketch8@FujaraBottomG2.Part | 691.1340 | 27.2100 | N/A | FALSE | FALSE | FALSE
FujaraBottomG2-1 | Default | Chamfer1 | Chamfer | size@Chamfer1@FujaraBottomG2.Part | 16.7386 | 0.6590 | N/A | FALSE | FALSE | FALSE
FujaraBottomG2-1 | Default | Chamfer1 | Chamfer | angle@Chamfer1@FujaraBottomG2.Part | 785.3982 | 30.9212 | N/A | FALSE | FALSE | FALSE
FujaraBottomG2-1 | Default | Sketch3 | ProfileFeature | outer_diameter@Sketch3@FujaraBottomG2.Part | 47.6250 | 1.8750 | N/A | TRUE | FALSE | FALSE
FujaraBottomG2-1 | Default | outer diameter | ICE | outer_diameter@Sketch3@FujaraBottomG2.Part | 47.6250 | 1.8750 | N/A | TRUE | FALSE | FALSE
FujaraBottomG2-1 | Default | Sketch3 | ProfileFeature | outer_diameter@Sketch3@FujaraBottomG2.Part | 47.6250 | 1.8750 | N/A | TRUE | FALSE | FALSE
FujaraBottomG2-1 | Default | Sketch7 | ProfileFeature | groove_width@Sketch7@FujaraBottomG2.Part | 3.1750 | 0.1250 | N/A | FALSE | FALSE | FALSE
FujaraBottomG2-1 | Default | Sketch7 | ProfileFeature | groove_depth@Sketch7@FujaraBottomG2.Part | 6.3500 | 0.2500 | N/A | FALSE | FALSE | FALSE
FujaraBottomG2-1 | Default | Sketch7 | ProfileFeature | groove_location@Sketch7@FujaraBottomG2.Part | 47.6250 | 1.8750 | N/A | TRUE | FALSE | FALSE
FujaraBottomG2-1 | Default | Sketch7 | ProfileFeature | finished_length@Sketch7@FujaraBottomG2.Part | 1755.7750 | 69.1250 | N/A | TRUE | FALSE | FALSE
FujaraBottomG2-1 | Default | end length locator | RevCut | D1@end length locator@FujaraBottomG2.Part | 6283.1853 | 247.3695 | N/A | FALSE | FALSE | FALSE
FujaraBottomG2-1 | Default | end length locator | RevCut | groove_width@Sketch7@FujaraBottomG2.Part | 3.1750 | 0.1250 | N/A | FALSE | FALSE | FALSE
FujaraBottomG2-1 | Default | end length locator | RevCut | groove_depth@Sketch7@FujaraBottomG2.Part | 6.3500 | 0.2500 | N/A | FALSE | FALSE | FALSE
FujaraBottomG2-1 | Default | end length locator | RevCut | groove_location@Sketch7@FujaraBottomG2.Part | 47.6250 | 1.8750 | N/A | TRUE | FALSE | FALSE
FujaraBottomG2-1 | Default | end length locator | RevCut | finished_length@Sketch7@FujaraBottomG2.Part | 1755.7750 | 69.1250 | N/A | TRUE | FALSE | FALSE
FujaraBottomG2-1 | Default | Sketch7 | ProfileFeature | groove_width@Sketch7@FujaraBottomG2.Part | 3.1750 | 0.1250 | N/A | FALSE | FALSE | FALSE
FujaraBottomG2-1 | Default | Sketch7 | ProfileFeature | groove_depth@Sketch7@FujaraBottomG2.Part | 6.3500 | 0.2500 | N/A | FALSE | FALSE | FALSE
FujaraBottomG2-1 | Default | Sketch7 | ProfileFeature | groove_location@Sketch7@FujaraBottomG2.Part | 47.6250 | 1.8750 | N/A | TRUE | FALSE | FALSE
FujaraBottomG2-1 | Default | Sketch7 | ProfileFeature | finished_length@Sketch7@FujaraBottomG2.Part | 1755.7750 | 69.1250 | N/A | TRUE | FALSE | FALSE
FujaraBottomG2-1 | Default | Chamfer at foot | Chamfer | length@Chamfer at foot@FujaraBottomG2.Part | 1.9050 | 0.0750 | N/A | FALSE | FALSE | FALSE
FujaraBottomG2-1 | Default | Chamfer at foot | Chamfer | angle@Chamfer at foot@FujaraBottomG2.Part | 785.3982 | 30.9212 | N/A | FALSE | FALSE | FALSE
FujaraBottomG2-1 | Default | [Equation 0] | Equation |  |  |  |  |  |  | TRUE | "g_body_OD"= 47.625mm
FujaraBottomG2-1 | Default | [Equation 1] | Equation |  |  |  |  |  |  | TRUE | "g_body_ID"= 31.75mm
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

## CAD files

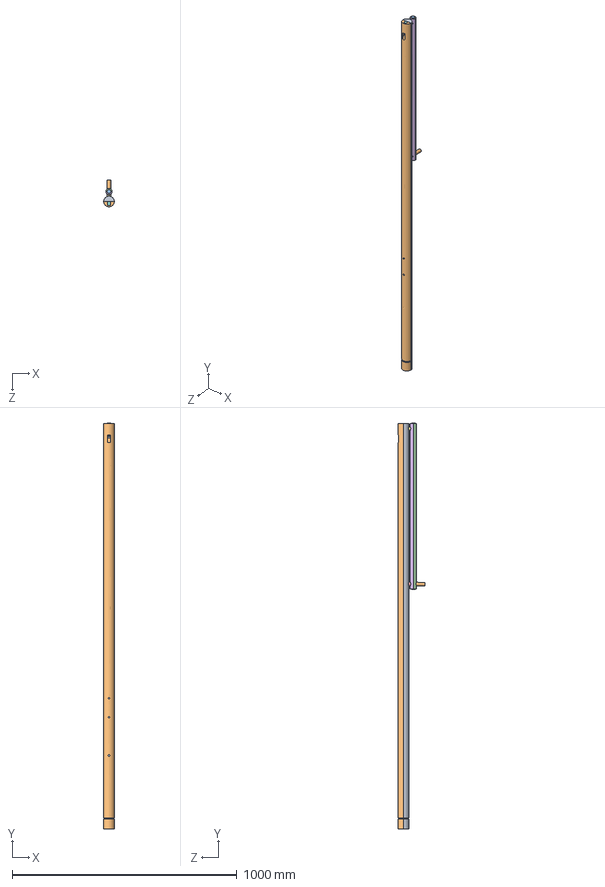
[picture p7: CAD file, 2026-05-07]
CAD/fujara-body/Fujara_Assembly.SLDASM
47.6 x 1806.6 x 118.9 mm
G2FujaraTop
FujaraBottomG2
G2FujaraFluePlug
toptube
G2Fujara_MouthpieceBottom
bottomtube
G2Fujara_MouthpieceTop
Cork x 2
mouthpiece
7815K833_High-Strength 932 Bronze Flanged Sleeve Bearing

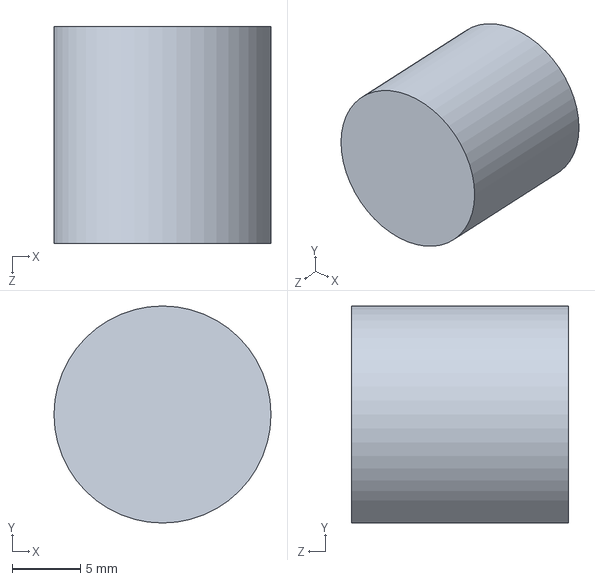
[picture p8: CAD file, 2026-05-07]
CAD/fujara-body/bottomtube.SLDPRT
15.9 x 15.9 x 15.9 mm

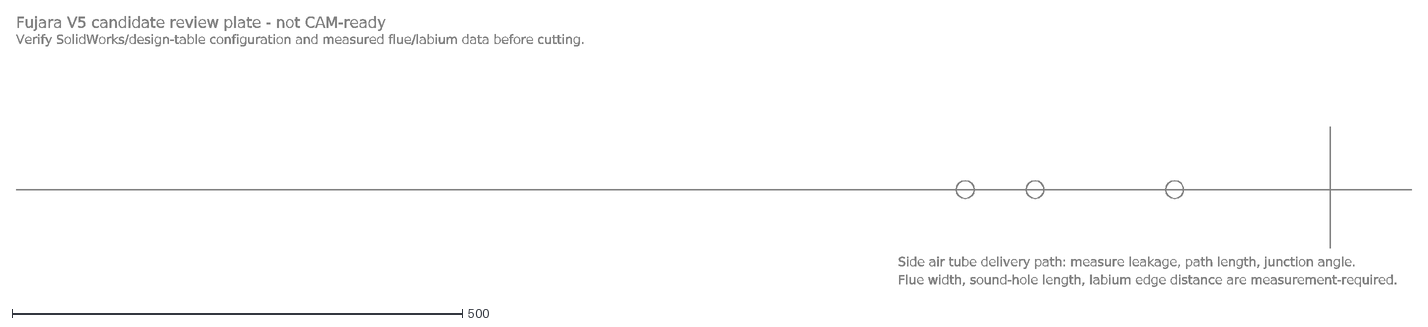
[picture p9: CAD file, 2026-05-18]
drawings/fujara.dxf
Fujara V5 candidate review plate - not CAM-ready
Verify SolidWorks/design-table configuration and measured flue/labium data before cutting.
Side air tube delivery path: measure leakage, path length, junction angle.
Flue width, sound-hole length, labium edge distance are measurement-required.

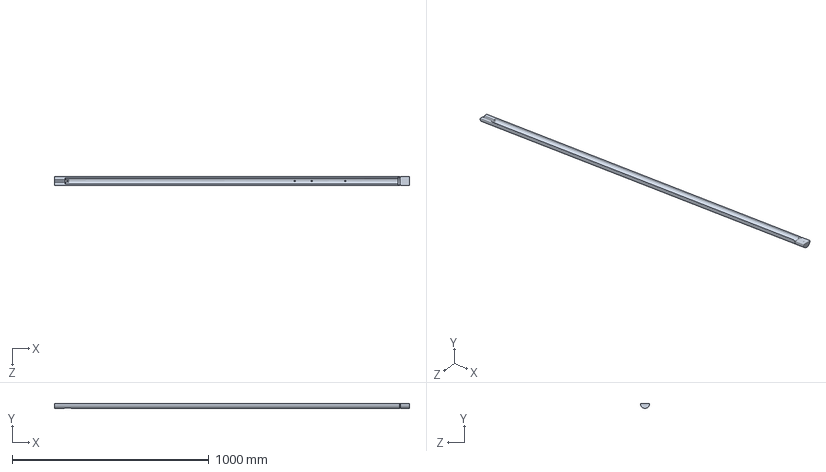
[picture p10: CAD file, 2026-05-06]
CAD/fujara-body/G2FujaraTop.SLDPRT
1803.4 x 23.8 x 47.6 mm

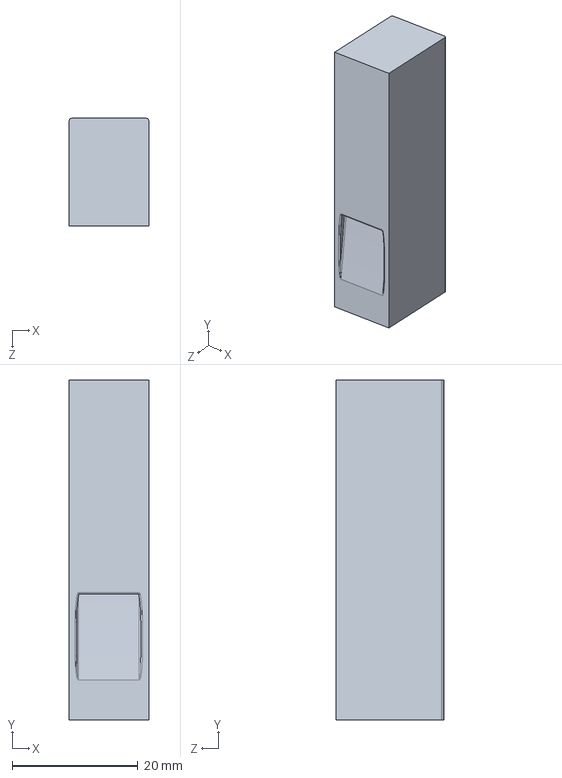
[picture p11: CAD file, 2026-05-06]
CAD/fujara-body/G2FujaraFluePlug.SLDPRT
12.6 x 54.0 x 17.1 mm

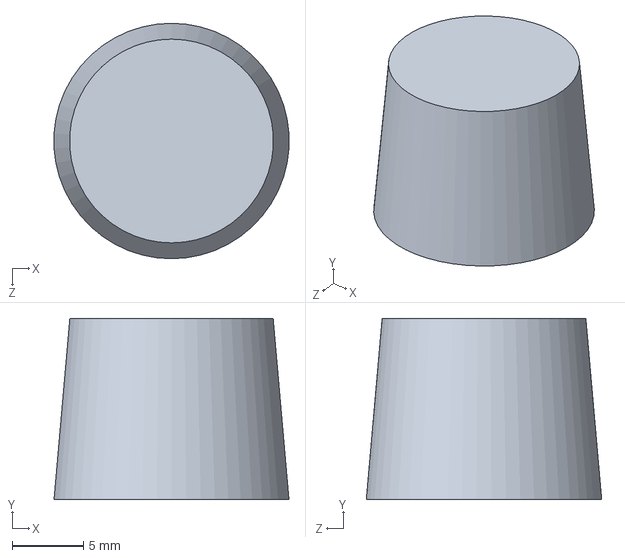
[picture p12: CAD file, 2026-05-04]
CAD/fujara-body/Cork.SLDPRT
16.5 x 12.7 x 16.5 mm

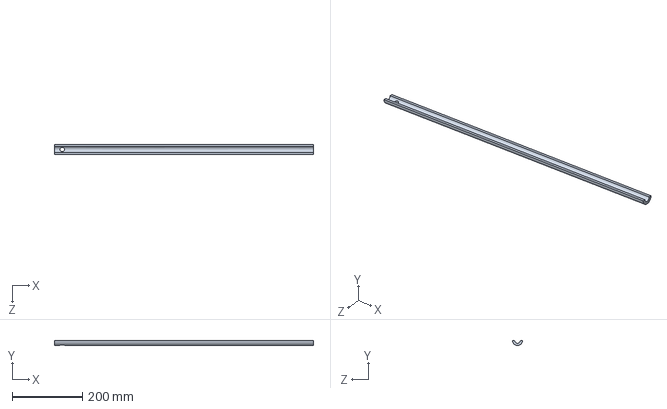
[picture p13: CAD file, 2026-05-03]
CAD/fujara-body/G2Fujara_MouthpieceTop.SLDPRT
735.6 x 14.3 x 28.6 mm

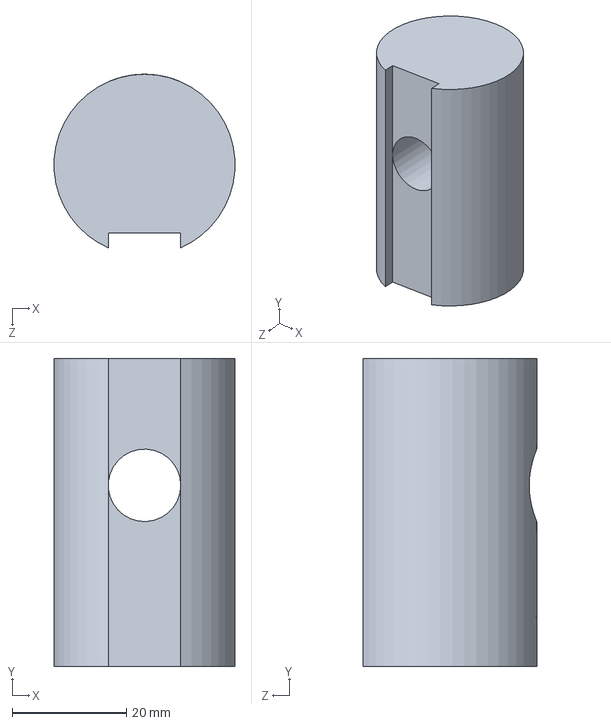
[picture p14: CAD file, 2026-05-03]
CAD/fujara-body/G2FujaraFlue.SLDPRT
31.7 x 54.0 x 30.4 mm

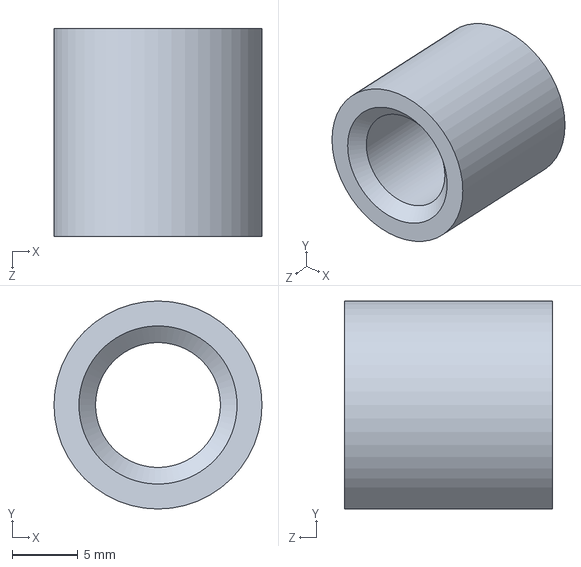
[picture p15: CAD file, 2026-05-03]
CAD/fujara-body/toptube.SLDPRT
15.9 x 15.9 x 15.9 mm

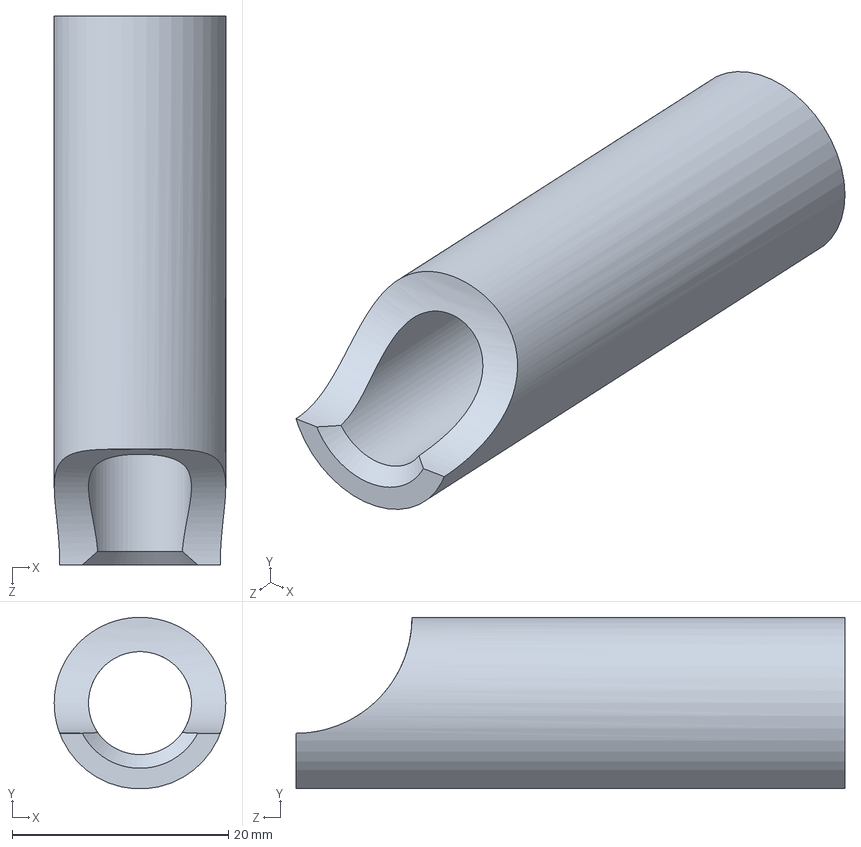
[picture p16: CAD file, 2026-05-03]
CAD/fujara-body/mouthpiece.SLDPRT
15.9 x 15.9 x 50.8 mm

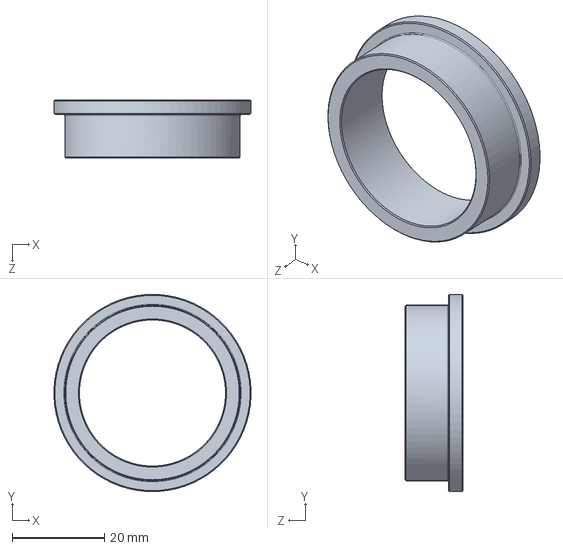
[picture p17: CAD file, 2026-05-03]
CAD/fujara-body/7815K833_High-Strength 932 Bronze Flanged Sleeve Bearing.SLDPRT
42.8 x 42.9 x 12.7 mm

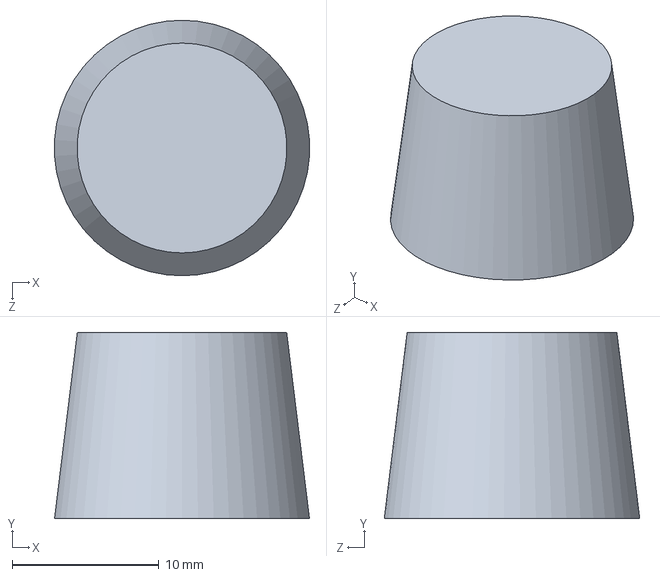
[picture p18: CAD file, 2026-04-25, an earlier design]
CAD/labium-and-nest/Cork.SLDPRT
17.4 x 12.7 x 17.4 mm

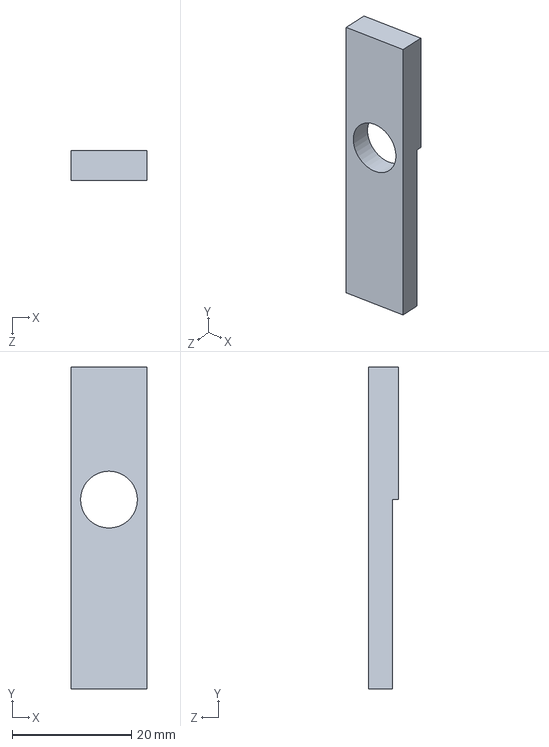
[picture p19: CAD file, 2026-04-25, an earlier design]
CAD/labium-and-nest/G2FujaraFluePlug.SLDPRT
12.7 x 54.0 x 5.08 mm

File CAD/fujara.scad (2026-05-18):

// Fujara V5 candidate OpenSCAD starter.
// Review scaffold only: verify against SolidWorks/design-table authority before shop use.

$fn = 72;

// Source refs:
// - family-spec.csv member FUJ-A2-STUDY
// - sw-reference/Fujara-SW-Design-Table.csv
// - CAD/fujara-body/G2Fujara_Assembly.SLDASM_dimensions.csv

target_note = "A2";
target_hz = 110.00;
temperature_c = 20;

// Validator-compatible first-pass open-open length at 20 C.
main_bore_length_mm = 1550.96;
main_bore_id_mm = 31.75;
wall_thickness_mm = 6.35;
outer_diameter_mm = main_bore_id_mm + 2 * wall_thickness_mm;

// Traditional fujara three-hole layout rule measured from the foot end.
hole1_from_foot_mm = main_bore_length_mm * 0.83;
hole2_from_foot_mm = main_bore_length_mm * 0.73;
hole3_from_foot_mm = main_bore_length_mm * 0.68;
hole_diameter_mm = 10;

// Measurement-required delivery/voicing placeholders.
side_tube_center_offset_mm = 58;
side_tube_od_mm = 22;
side_tube_id_mm = 14;
side_tube_length_mm = 420;
flue_width_mm = 12;
sound_hole_length_mm = 6.35;

module main_bore_shell() {
  difference() {
    cylinder(h = main_bore_length_mm, d = outer_diameter_mm);
    translate([0, 0, -1]) cylinder(h = main_bore_length_mm + 2, d = main_bore_id_mm);
  }
}

module tone_hole(z_pos) {
  translate([0, -outer_diameter_mm / 2, z_pos])
    rotate([90, 0, 0])
      cylinder(h = outer_diameter_mm, d = hole_diameter_mm);
}

module side_air_tube() {
  translate([side_tube_center_offset_mm, 0, main_bore_length_mm - side_tube_length_mm])
    difference() {
      cylinder(h = side_tube_length_mm, d = side_tube_od_mm);
      translate([0, 0, -1]) cylinder(h = side_tube_length_mm + 2, d = side_tube_id_mm);
    }
}

module labium_review_marker() {
  translate([-outer_diameter_mm / 2, -outer_diameter_mm / 2, main_bore_length_mm - 75])
    cube([outer_diameter_mm, 2, sound_hole_length_mm]);
}

difference() {
  main_bore_shell();
  tone_hole(hole1_from_foot_mm);
  tone_hole(hole2_from_foot_mm);
  tone_hole(hole3_from_foot_mm);
}

side_air_tube();
labium_review_marker();

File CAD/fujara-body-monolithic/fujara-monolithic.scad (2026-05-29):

// Fujara — Monolithic Body Variant (CAD/fujara-body-monolithic/)
// Issue #2: integrate Flue_Top voicing geometry into Body_Top + Body_Bottom.
//
// This variant keeps the original fujara.scad assembly as the default.
// The monolithic version eliminates the separate Flue_Top glue joint by
// cutting the flue windway, sound window, and labium edge directly into
// Body_Top. Body_Bottom is the lower bore continuation.
//
// Fabrication authority status: PENDING_MEASUREMENT.
// Verify all dimensions against design-table/fujara-dimensions-parametric.xlsx
// and family-spec.csv before any machining.
// See CAD/mcp-session-log.md for V5 provenance.

$fn = 72;

// ── Parameters (from family-spec.csv FUJ-A2-STUDY + design-table) ────────────

target_note       = "A2";
target_hz         = 110.00;

main_bore_length_mm  = 1550.96;   // open-open effective length seed
main_bore_id_mm      = 31.75;     // bore ID from design table
wall_thickness_mm    = 6.35;
outer_dia_mm         = main_bore_id_mm + 2 * wall_thickness_mm;

// Tone holes (position from foot end — traditional 0.83/0.73/0.68 ratios).
hole1_from_foot_mm = main_bore_length_mm * 0.83;
hole2_from_foot_mm = main_bore_length_mm * 0.73;
hole3_from_foot_mm = main_bore_length_mm * 0.68;
hole_diameter_mm   = 10;

// ── Body_Top / Body_Bottom split point ───────────────────────────────────────
// The joint sits just below the voicing zone so both pieces are manageable
// on a lathe. Adjust split_z to match your blank/lathe capacity.
split_z_mm = main_bore_length_mm - 500;  // starter value; measurement-required

// ── Monolithic flue geometry (integrated into Body_Top) ──────────────────────
// In the separate-part assembly these lived in Fujara_Flue_Top.
// Here they are cut directly into the top section.
flue_width_mm           = 12.0;   // windway width — measurement-required
flue_depth_mm           = 4.0;    // windway height — measurement-required
sound_window_length_mm  = 30.0;   // labium opening along bore axis — measurement-required
sound_window_width_mm   = 16.0;   // labium opening across bore — measurement-required
labium_angle_deg        = 35;     // splitting-edge angle from horizontal — measurement-required

// Side air tube (unchanged from fujara.scad reference design).
side_tube_center_offset_mm = 58;
side_tube_od_mm            = 22;
side_tube_id_mm            = 14;
side_tube_length_mm        = 420;

// ── Modules ──────────────────────────────────────────────────────────────────

module bore_shell(len_mm) {
  difference() {
    cylinder(h = len_mm, d = outer_dia_mm);
    translate([0, 0, -1]) cylinder(h = len_mm + 2, d = main_bore_id_mm);
  }
}

module tone_hole(z_pos) {
  translate([0, -outer_dia_mm / 2, z_pos])
    rotate([90, 0, 0])
      cylinder(h = outer_dia_mm + 2, d = hole_diameter_mm);
}

// Integrated flue windway cut into the body wall at the top.
// The windway runs axially through the wall from the side-tube inlet port
// to the sound window opening.
module flue_windway() {
  translate([side_tube_center_offset_mm - flue_width_mm / 2,
             -outer_dia_mm / 2,
             main_bore_length_mm - side_tube_length_mm - flue_depth_mm])
    cube([flue_width_mm, outer_dia_mm / 2 + flue_depth_mm, side_tube_length_mm + flue_depth_mm]);
}

// Sound window opening through the bore wall.
module sound_window() {
  translate([-sound_window_width_mm / 2,
             -outer_dia_mm / 2 - 1,
             main_bore_length_mm - side_tube_length_mm - sound_window_length_mm])
    cube([sound_window_width_mm, wall_thickness_mm + 2, sound_window_length_mm]);
}

// Labium (splitting edge) — angled face at the top of the sound window.
// Modelled as a rotated wedge; refine angle after P0 voicing tests.
module labium_edge() {
  translate([0, -outer_dia_mm / 2, main_bore_length_mm - side_tube_length_mm])
    rotate([labium_angle_deg, 0, 0])
      cube([sound_window_width_mm, 2, wall_thickness_mm], center = true);
}

module side_air_tube() {
  translate([side_tube_center_offset_mm, 0,
             main_bore_length_mm - side_tube_length_mm])
    difference() {
      cylinder(h = side_tube_length_mm, d = side_tube_od_mm);
      translate([0, 0, -1]) cylinder(h = side_tube_length_mm + 2, d = side_tube_id_mm);
    }
}

// ── Body_Top: upper bore section with integrated flue/voicing geometry ────────
module body_top() {
  top_len = main_bore_length_mm - split_z_mm;
  translate([0, 0, split_z_mm])
    difference() {
      union() {
        bore_shell(top_len);
        side_air_tube();
      }
      flue_windway();
      sound_window();
    }
}

// ── Body_Bottom: lower bore continuation with tone holes ─────────────────────
module body_bottom() {
  difference() {
    bore_shell(split_z_mm);
    tone_hole(hole1_from_foot_mm);
    tone_hole(hole2_from_foot_mm);
    tone_hole(hole3_from_foot_mm);
  }
}

// ── Assembly ─────────────────────────────────────────────────────────────────
// Render Body_Top + Body_Bottom together for visual review.
// Change SHOW_TOP / SHOW_BOTTOM to isolate pieces for machining review.

SHOW_TOP    = true;
SHOW_BOTTOM = true;

if (SHOW_BOTTOM) body_bottom();
if (SHOW_TOP)    body_top();

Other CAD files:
CAD/fujara-body/FujaraBottomG2.SLDPRT
CAD/fujara-body/G2Fujara_MouthpieceBottom.SLDPRT
CAD/labium-and-nest/mouthpiece.SLDPRT
CAD/labium-and-nest/G2Fujara_MouthpieceTop.SLDPRT
CAD/labium-and-nest/G2Fujara_MouthpieceBottom.SLDPRT
CAD/fujara-body/G2Fujara_Assembly.SLDDRW
CAD/labium-and-nest/G2FujaraFlue.SLDPRT

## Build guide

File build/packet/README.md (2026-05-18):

# Round 23 B8 — `fujara` issue #5

Lane `B8` V5 build-packet starter.

Scope: focus bore profile confidence and side-branch authority gating before any CAD/CADX/fabrication claims.

Current status: **V5 build-packet candidate for design review**. This is not
build-ready, measured, or runtime-verified.

## Packet Files

- `design.md` — issue scope and authority boundary
- `family-spec.csv` — single family/spec row describing side-branch architecture
- `bore-station-plan.csv` — measurement plan for the main bore and side branch
- `validation-loop.csv` — explicit measurement and authority steps
- `validation.csv` — move-condition gates from L2 to L3/L4
- `visual-output-register.csv` — visual/dependency authority control
- `acoustic-model.md` — bore/flue/side-tube acoustic reasoning and tuning discipline
- Root V5 files (`design.md`, `bom.csv`, `sourcing.csv`, `cut-list.csv`,
  `validation.csv`, `risks.md`, `drawing-brief.md`, `photo-shotlist.md`)
  mirror the issue #5 acceptance surface.

## Non-claims

- This starter does not include build-ready DXF/CAD geometry.
- No validated bore profile, flue/labium response, or side-tube delivery
  measurements are committed yet.
- No supplier, CNC, or sourcing claims are final.
- This packet is intended for planning, design review, and first-party capture planning only.

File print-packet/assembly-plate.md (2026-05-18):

# Fujara Assembly Plate

Current status: V5 build-packet candidate, not build-ready.

This review plate summarizes the candidate A2 study baseline and the evidence
chain for issue #5.

## Dimensions

- Governing model: open-open edge-tone/overtone flute.
- Target: A2, 110.00 Hz at 20 C validator baseline.
- First-pass geometry length: 1550.96 mm.
- Bore ID reference: 31.75 mm from SolidWorks/design-table evidence.
- Hole layout: 68%, 73%, and 83% of long chamber length from the foot end.

## Measurement-Required Before Build Release

- Bore stations at foot, mid-body, side-tube/labium zone, and top.
- Flue width and height.
- Sound-hole length and labium edge distance.
- Side air-tube leak/path/junction-angle checks.
- Fundamental and overblown partial tuner captures at known temperature and
  humidity.

Generated images are concept-only. The DXF/SVG/PDF artifacts are review plates
and must be checked against the selected CAD/design-table configuration before
machining.

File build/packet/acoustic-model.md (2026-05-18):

# Fujara Bore, Flue, And Side-Tube Acoustic Model

Current status: V5 build-packet candidate, not build-ready.

## Model Choice

The fujara packet uses `acoustic_law=open_open` and
`end_condition=both_ends_open`.

That is deliberate: the fujara is an edge-tone overtone flute. Its long main
bore controls the fundamental and harmonic-series behavior. The side air tube
delivers breath to the labium; it should be measured for leakage, pressure
drop, centerline length, and junction angle, but it is not treated as a pitched
side branch unless measured evidence proves a repeatable coupling effect.

## First-Pass Length Check

At 20 C, the validator's open-open relation uses:

```text
L_geom = 343000 / (2 * target_hz) - 8.13 mm
```

For the A2 study baseline:

```text
target_hz = 110.00
L_geom = 1550.96 mm
```

This row exists so `validate_acoustic_law.py` checks the model and stops silent
physics drift. It does not replace the existing design table, SolidWorks
configurations, or measured tuning work.

## Flue And Labium Variables

Before any public build packet or shop cut:

- Measure flue width and height.
- Measure sound-hole length and labium edge distance.
- Confirm nest depth and side-tube outlet alignment.
- Record response notes at low, medium, and overblown pressure.
- Log temperature and humidity for every tuning measurement.

## Tuning Discipline

The next physical validation pass should record:

- Fundamental pitch at room temperature.
- Fundamental pitch after breath-warmed stabilization.
- Overblown partials through the practical melody range.
- Three-hole response against the 68%, 73%, and 83% layout rule.
- Cents error against the target scale, with any trim decision logged before
  geometry is revised.

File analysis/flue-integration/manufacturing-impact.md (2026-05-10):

# Manufacturing impact — separate vs integrated flue

## Joinery + glue strategy

### Separate-flue (current G2)

Three permanent joints in the head zone:

1. `G2FujaraTop ↔ FujaraBottomG2` — the body's split-blank glue line
   (full body length, ~1755 mm). Hide-glue or PVA, edge-to-edge with
   `c_glue_gap = 0.0762 mm` clearance.
2. `G2FujaraTop ↔ G2FujaraFlue` — radial glue between block OD and
   bore ID at the head zone, ~54 mm long. Same clearance.
3. `FujaraBottomG2 ↔ G2FujaraFlue` — same as (2), other half.

Plus one removable joint:

4. `G2FujaraFluePlug` ↔ flue block — wax-sealed,
   `c_wax_seal_fit = 0.0762 mm`. User-serviceable.

### Integrated-flue

One permanent joint in the head zone:

1. `G2FujaraTop ↔ FujaraBottomG2` — the body's split-blank glue line.
   **Unchanged** — already runs the full body length, the head zone's
   integrated windway features are just additional pocket cuts on the
   inside faces before glue-up.

Plus one removable joint, unchanged:

2. `G2FujaraFluePlug` ↔ pocket in top board — wax-sealed,
   `c_wax_seal_fit = 0.0762 mm`. User-serviceable.

**Net delta:** −2 permanent joints, same removable joint.

## Tolerance impact

### Separate: stack-up across three joints

The labium-to-bore-wall offset is what voices the instrument. In the
separate variant, it depends on:

- `g_body_ID` (bore diameter, master global)
- `flue_block_diameter = g_body_ID − c_glue_gap` (block OD)
- Labium edge cut on `G2FujaraTop` (literal sketch dim)
- Glue-line gap between block and bore (process variable)

Worst-case stack: ~0.15 mm (sum of the two `c_glue_gap` instances on
opposite sides of the block, plus mid-tolerance bias on the labium
literal). In practice this is recoverable by post-glue voicing
(scraping the labium, adjusting the plug).

### Integrated: stack-up across one joint

- `g_body_ID` (bore diameter, master global)
- Labium edge cut on `G2FujaraTop` (literal sketch dim)
- Top↔bottom glue line offset (one number)

Worst-case stack: ~0.05 mm. The flue-block radial glue gap drops out
because there is no separate flue block. **Tighter and less variable.**

This is the single strongest reason to integrate: the labium-to-bore
relationship gets simpler and more repeatable.

## Jig changes

### Glue-up jig

Separate: needs the body-half glue jig **and** a radial concentric jig
to seat the flue block to the bore at the right axial location while
the body halves register against each other. Two-stage glue-up
(seat block, then close body halves) or one-stage (everything at
once with the block held by a removable mandrel through the bore).

Integrated: needs only the body-half glue jig. The windway pockets on
the inside faces are CNC-cut before glue-up, no separate seating
operation.

**Net delta:** drop the radial concentric jig.

### CNC tool paths

Separate: three SLDPRT files mean three CAM setups (top board, bottom
board, flue block). The flue block is small enough to be batched
several-up on a single sheet.

Integrated: two SLDPRT files (top board, bottom board), each with the
windway pocket added to its existing inside-face program. **Top
board's program grows** by the windway slot + breath duct + flue
engagement step (three additional cuts, ~3 minutes of machine time
on a typical hobby CNC). **Bottom board's program grows** by the
optional matching engagement step (or stays flat — a flat windway
floor works acoustically).

**Net delta:** lose one CAM setup (the flue block), grow two existing
programs slightly. Wall-clock saving is on the order of one block
batch's setup time.

### Voicing fixture

Both variants use the same final voicing fixture: the assembled body
clamped at the foot with a microphone at the labium and the flue plug
in place. No change.

## Repair-friendliness

This is where separate **wins**.

| Failure mode | Separate | Integrated |
|---|---|---|
| Cracked flue block | swap block (~$5 stock) | rebuild whole body |
| Bad labium cut on flue side | replace flue block | replace top board → rebuild body |
| Tone-hole misposition | replace top board → rebuild body | same |
| Wax plug worn | re-cut plug (both variants) | re-cut plug |

The integrated variant ties windway integrity to body integrity.
A broken windway means the whole instrument goes back to billet.
This is the price of the cleaner tolerance stack.

## Sourcing impact

| Stock | Separate | Integrated |
|---|---|---|
| Body boards | 2 × 71" × 2.25" × 1.125" | 2 × 71" × 2.25" × 1.125" |
| Flue block | 1 × 32mm × 60mm hardwood | — |
| Flue plug | 1 × 13mm × 50mm hardwood | 1 × 13mm × 50mm hardwood |

Drops one ~$5 hardwood block per instrument. Negligible against the
~$60 board cost.

## Process change risk

The integrated variant requires the windway pocket to be cut into the
inside face of `G2FujaraTop` **before** the bore is bored through. If
the bore operation goes second (typical), the windway pocket is
intersected by the bore — this is intended. If the bore goes first
(less typical), the windway pocket has to be milled on a curved
inside face, which is harder and less repeatable.

**Recommended order:** windway pocket → glue-up → bore. The
split-blank construction makes this natural — the windway is on a flat
face, the bore is the operation that creates the cylindrical inner
surface.

## Summary

| Aspect | Separate | Integrated | Winner |
|---|---|---|---|
| Permanent joints (head zone) | 3 | 1 | integrated |
| CAM setups | 3 | 2 | integrated |
| Tolerance stack at labium | ±0.15 mm | ±0.05 mm | integrated |
| Glue-up fixtures | 2 | 1 | integrated |
| Repair-friendly (windway-only failure) | yes | no | separate |
| Sourcing parts | 3 stock items | 2 stock items | integrated |
| Mass at finish | ~30 g extra | baseline | wash (negligible) |

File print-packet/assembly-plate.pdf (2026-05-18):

## Fujara Assembly Plate - V5 Candidate

Status: V5 build-packet candidate; not build-ready or empirically verified. Model: open-open edge-tone/overtone flute; A2 study baseline at 110.00 Hz. First-pass geometry length: 1550.96 mm at 20 C validator baseline.
Bore ID reference: 31.75 mm from SolidWorks/design-table evidence.
Hole layout: 68%, 73%, and 83% of long chamber length from the foot end.
Authority: design tables, SolidWorks sources, CAD/fujara.scad, drawings/fujara.dxf.
Concept images and renders do not control dimensions or toolpaths.
Before build release: measure bore stations, flue/labium geometry, side air-tube leakage/path/junction angle, and tuner captures at known temperature/humidity.

Review sketch (not to scale)

68% 73% 83%

Generated locally from print-packet/assembly-plate.md for issue #5 review.

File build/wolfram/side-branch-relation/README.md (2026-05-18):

# Fujara B7 sidecar: bore / side-branch relation starter

This folder is a **sidecar** packet for `fujara` issue `#5` and is intentionally additive
because draft PR `#6` already owns `build/packet/*`.

## Purpose
- Add a small Wolfram starter that compares candidate side-branch geometries against
  the coupling-to-main-bore sensitivity metric.
- Keep the model explicitly marked as a starter and avoid claims of final physical
  validation.
- Produce committed runtime evidence with `wolframscript` output files.

## Files
- `fujara_sidebranch_starter.wl` — starter with assumptions and sensitivity equations.
- `fujara_sidebranch_study.csv` — runtime table generated by the script when available.

## Run command
```bash
wolframscript -file build/wolfram/side-branch-relation/fujara_sidebranch_starter.wl
```

Use a manager-side queue wrapper, such as `instrument-maker/scripts/wolframscript-queued.sh`,
when running alongside other Wolfram lanes. The script writes runtime artifacts
in the same folder and prints generated paths when execution succeeds.

## Notes and assumptions
- This lane is for a **runtime evidence starter** only.
- The formulas are intentionally simplified and labeled runtime-only.
- Geometric coupling labels are not treated as fabrication or acoustic build certification.

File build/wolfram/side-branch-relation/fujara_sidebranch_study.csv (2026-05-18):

Case | FrequencyHz | MainBoreDiameterIn | SideBranchDiameterIn | SideBranchLengthIn | MainAdjacentLengthIn | LabiumPhaseOffsetIn | ShuntFraction | PhaseTerm | Perturbation | MainImpedanceReal | MainImpedanceImag | SideImpedanceReal | SideImpedanceImag
A2-1.25in-bore | 73 | 1.25 | 0.19 | 4 | 54 | 0.5 | 0.0009086281533749789 | 0.9997116082015366 | 0.0009420093018183479 | 0 | -147910.81720721928 | 0 | 162932672.28186592
A2-1.25in-bore | 98 | 1.25 | 0.19 | 4 | 54 | 0.5 | 0.005576379649897046 | 0.9994802962617104 | 0.005779906828418979 | 0 | -669590.5809737579 | 0 | 120745809.0260576
A2-1.25in-bore | 122 | 1.25 | 0.19 | 4 | 54 | 0.5 | 0.10911347578323011 | 0.9991946549756799 | 0.11306358703984484 | 0 | -9481140.755983988 | 0 | 96373622.98998103
A2-1.25in-bore | 147 | 1.25 | 0.19 | 4 | 54 | 0.5 | 0.009998661702374805 | 0.9988309198307886 | 0.010356860334343606 | 0 | 801178.9307136952 | 0 | 79327437.73439513
A2-1.25in-bore | 196 | 1.25 | 0.19 | 4 | 54 | 0.5 | 0.00225871570840978 | 0.9979222654147438 | 0.002337505018762828 | 0 | -131293.45948845719 | 0 | 58258776.70123411
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

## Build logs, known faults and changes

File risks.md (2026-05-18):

# Fujara V5 Candidate Risks

Current readiness: V5 build-packet candidate, not build-ready.

## Acoustic Risks

- Main-bore end corrections may not match the simple open-open validator model.
- Side air tube leakage, pressure drop, and junction angle may change response
  even if they do not set the bore fundamental.
- Flue/labium geometry is response-critical and needs physical adjustment.
- Overblown partials may not align with the intended modal scale until the
  bore, tone holes, and voicing are measured together.

## Fabrication Risks

- Long stave glue-up can distort the bore or change the effective ID.
- Existing SolidWorks files may not match the selected key/configuration until
  a configuration-specific export is reviewed.
- The DXF and SVG plates are review plates, not CNC toolpaths.
- Long stock sourcing, workholding, and lathe capacity remain practical
  blockers.

## Safety And Cultural Risks

- Breath-contact finishes and adhesives must be fully cured and appropriate for
  repeated contact.
- Moisture drainage and cleaning must be planned before public build guidance.
- Cultural attribution to Slovak fujara traditions must stay visible; this repo
  documents an engineering derivation, not ownership of the tradition.

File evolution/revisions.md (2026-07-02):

# Revision Register — fujara

| Rev | Date | Parent | Delta | Downstream artifacts invalidated |
| --- | --- | --- | --- | --- |
| A | 2026-07-01 | — | Stage 0 intake of current masters (CAD/fujara.scad + native SolidWorks assembly + design-table/fujara-dimensions-parametric.xlsx). | none (no alpha/beta/production artifacts exist yet) |

Stage 0 only. Gate A has not been run; no Alpha compiles, vendor quotes, or production lock exist for this product.

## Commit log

2026-04-25 Initial content: README, parametric design table, folder skeleton
    [fujara-dimensions-parametric.xlsx]
2026-04-25 Add hero image and CAD files (body, labium-and-nest, cnc-toolpaths)
    [Cork.SLDPRT, FujaraBottomG2.SLDPRT, G2FujaraFlue.SLDPRT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]
2026-05-02 Add Fujara design table from Musical Instruments workbook
    [fujara-design-table.xlsx]
2026-05-09 capstone: parametric modal + acoustic FEM across L:D 45/50/55/60 (#3)
    L3-frontier analysis for fujara #1. Adds capstone/ with:
    - capstone/scripts/fujara_design_math.py — shared closed-form physics
    (open-open pipe with end correction, free-free Euler-Bernoulli beam,
    Smith-Korpela wall-flex perturbation), four canonical L:D rows at A2
    (110 Hz), 0.22*D wall-thickness rule.
    - capstone/scripts/generate_design_table.py — emits
    design-table/aspect-ratio-matrix.csv (4 rows; D, L, t, L_eff,
    cavity volume, first 3 analytic modes, predicted f0).
    - capstone/scripts/modal_fem.py — analytic free-free Euler-Bernoulli
    + scipy cubic-Hermite FE eigensolve (80 elements, free-free), lowest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
    [aspect-ratio-matrix.csv, cavity_modes.csv, coupled-vs-uncoupled.csv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]
2026-05-10 analysis: integrated-flue variant comparison (refs #2) (#4)
    Re-run capstone PR #3 1-D Webster cavity FEM on an integrated-flue
    profile (Flue_Top features rolled into Body_Top + Body_Bottom). The
    comparison sits at L2-L3: design + first-pass physics, no L4
    empirical claim.
    Findings
    - 1-D Webster reports zero delta on f0_modal and f0_coupled across
    all five modes — both variants share the labium-to-foot length and
    bore geometry the solver sees.
    - Real acoustic differences live in the labium-end correction
    (sensitivity-bounded at +/-5 cents for +/-2 mm shift) and mode
    purity, which need a built prototype.
    - Manufacturing trades drop one part, two glue joints, and one CAM
    setup in e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
    [integrated-vs-separate.csv, sensitivity-end-correction.csv]
2026-05-18 Add fujara V5 bore and side-branch starter (#6)
    [bore-station-plan.csv, family-spec.csv, validation-loop.csv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]
2026-05-18 Add fujara side-branch Wolfram runtime starter (#7)
    * Add B7 fujara wolfram side-branch starter sidecar
    * B7: queue-verification blocker for fujara side-branch Wolfram starter
    ---------
    [fujara_sidebranch_study.csv]
2026-05-18 Add fujara V5 candidate packet (#9)
    [bom.csv, cut-list.csv, family-spec.csv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]
2026-05-23 Recover from 2026-05-18 hygiene-bot stash; restore Wolfram/scratch files (stash@{1})
    [Fujaras.xlsx, fujara-dimensions-parametric.xlsx]
2026-05-29 Add monolithic body variant integrating Flue_Top into Body_Top/Bottom (Refs #2) (#10)
    Adds CAD/fujara-body-monolithic/fujara-monolithic.scad: new variant that
    integrates the flue windway, sound window, and labium edge directly into
    Body_Top instead of a separate Flue_Top glue-in. Body_Bottom holds the
    three tone holes. Split point at split_z_mm is measurement-required.
    All voicing dimensions (flue_width, flue_depth, labium_angle, sound_window)
    are measurement-required starters pending P0 voicing tests.
    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
    [fujara-monolithic.scad]
2026-05-31 Add image-gen concept prompt; wire explorer images
2026-06-21 Wire 3 rendered concept image(s) into explorer gallery
2026-07-02 V5 packet refresh: status line, provenance, evolution intake
    Normalized Status to explicit **Status:** L2 V5 build-packet candidate (kept
    prose + status table). Added provenance rows to CAD/mcp-session-log.md for
    fujara-design-table.xlsx, the native SolidWorks assembly + G2 dimension CSV, the
    OpenSCAD master, and the wolfram side-branch starter. Added wolfram register row
    (gap). Stage 0 evolution intake (manifest, design-intent, revisions). Existing
    CAD/fujara.scad kept (no rewrite); openscad render check pass.
    v5-validator: 3 fails -> 0 fails.
    [visual-output-register.csv]
